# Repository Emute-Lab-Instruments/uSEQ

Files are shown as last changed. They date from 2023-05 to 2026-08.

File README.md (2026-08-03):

# uSEQ

uSEQ is a livecodeable eurorack module.

There's a paper on it here: 

Kyriakoudis, Dimitris, & Kiefer, Chris. (2023, April 19). uSEQ: A LISPy Modular Sequencer for Eurorack with a Livecodable Microcontroller. 7th International Conference on Live Coding (ICLC2023), Utrecht, The Netherlands. https://doi.org/10.5281/zenodo.7843874

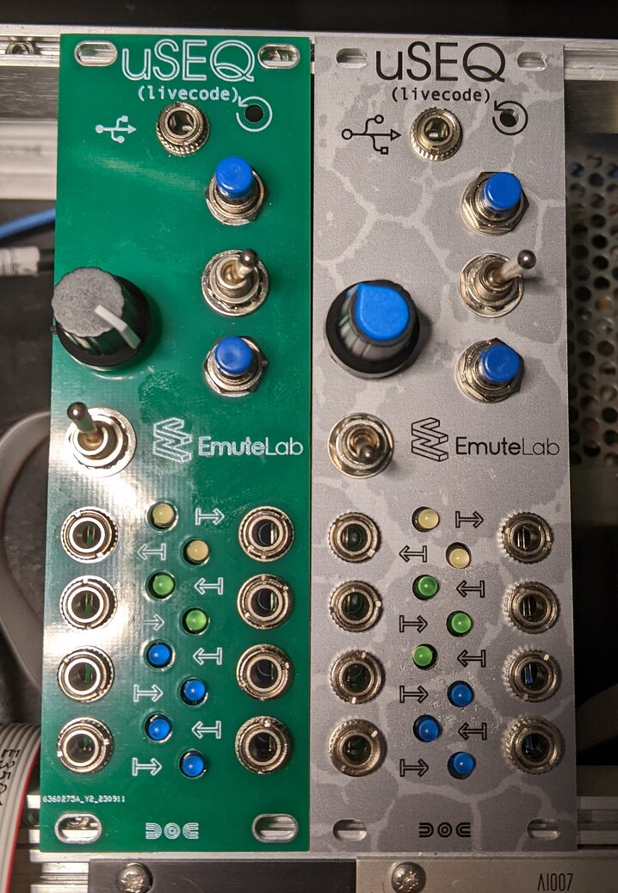
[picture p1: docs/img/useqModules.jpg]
uSEQ Modules


uSEQ modules, two panel designs (PCB, Aluminium)

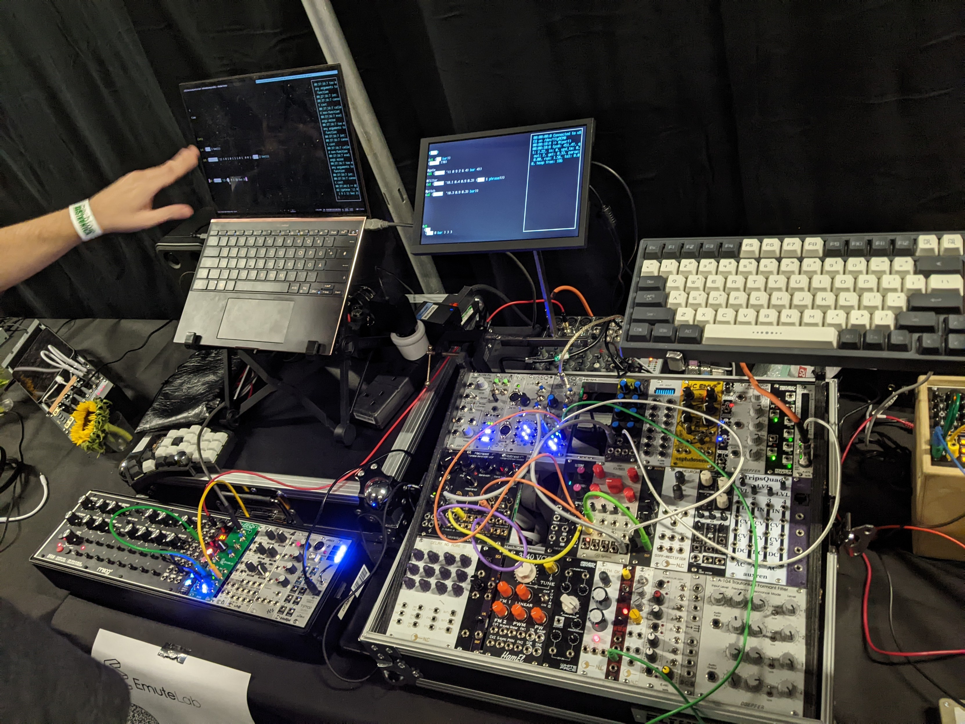
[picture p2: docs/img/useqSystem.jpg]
uSEQ In Use


uSEQ modules set up within eurorack performance systems

## Features:

* Open source hardware and software
* Low-cost DIY project
* Live code using a simple LISP language library, from a laptop or mobile device, using serial-over-USB
* Stream waveforms back over USB serial to a computer, and route it to MIDI or OSC, linking the modular with software and external hardware
* Livecoding engine with flexible timing and varied options for creating gate and CV patterns (from basic waveforms to euclidean sequencing) and structuring arrangements

More info from [https://www.emutelabinstruments.co.uk/useq/](https://www.emutelabinstruments.co.uk/useq/)

## Canonical Specs

The firmware/language specs live in [docs/specs/MAIN.md](docs/specs/MAIN.md).
Protocol details live in [docs/specs/wire-protocol.md](docs/specs/wire-protocol.md).
Read [MAP.md](MAP.md) for the repository index and [ALIGNMENT.md](ALIGNMENT.md)
for the dated mission-level gaps.

## Verification

- `nix-shell` enters the declared compiler, conformance, WASM, PlatformIO,
  and RP2040 goal-gate environment. On unattended hosts, use
  `nix-shell --run '<command>'` so PyYAML and the target tools come from the
  same environment.
- `meson setup build && meson compile -C build && meson test -C build` runs
  the native suites.
- `python3 scripts/run_conformance.py --probe build/test/signal_engine_probe --target native`
  runs the shared language corpus against the native probe.
- `scripts/build_wasm.sh` builds and checks the generated interpreter;
  `python3 scripts/run_conformance.py --target wasm` runs the same corpus
  against it; `python3 scripts/wasm_manifest.py verify` verifies its compiler
  record.
- `pio run -e musicthing` establishes target compile, link, and static size;
  it is not a physical-execution result.
- `python3 scripts/rp2040_memory_report.py` reads the exact linked ELF and
  enforces the 96KiB main-heap and 1MiB flash-image headroom gates. Runtime
  heap and stack watermarks remain separate target observations.
- `pio run -e musicthing-observe` builds the release-equivalent telemetry
  image used by simulator and physical-device capacity/endurance runs;
  `musicthing` remains the production image without devtools overhead.
- `python3 scripts/run_rp2040_profile.py` runs the full local RP2040
  acceptance surface: native correctness, constrained-profile conformance,
  capacity and sanitized endurance workloads, both target links, and exact
  ELF memory gates. See
  [docs/testing/rp2040-optimization.md](docs/testing/rp2040-optimization.md).
- `python3 scripts/run_wokwi_rp2040.py` boots that exact observation ELF in
  Wokwi and gates serial responses, target compile and tick timing, runtime
  heap/stack headroom, resource high-water, sustained tick throughput,
  protocol integrity, reset state, retained workload capacity, transactional
  rejection, and externally captured GPIO. It requires `wokwi-cli` and an
  unprinted `WOKWI_CLI_TOKEN`.
- `python3 scripts/run_rp2040_goal_gate.py` composes the complete native,
  exact-link, and simulator grades into one uniquely named candidate evidence
  directory for an optimization loop. Physical-device acceptance remains a
  separate release grade.

## Building the Firmware

The firmware is in the [uSEQ](./uSEQ/) folder.

Build the firmware in Arduino IDE, using the [Earle Philhower Pico core](https://github.com/earlephilhower/arduino-pico).

| Setting  | Value |
| --- | --- |
| Board  | Generic RP2040  |
| Boot Stage 2  | W25Q080 QSPI /2  |
| Flash Size | 16MB (Sketch 2MB, FS: 14MB) for `musicthing` |
| CPU Speed | 250MHz (Overclock) |
| Optimize | Optimize Even More (-O3) |

Overclock the Pico at 250Mhz and set the optimisation level to -O3.
Other program-card capacities require a matching PlatformIO partition profile;
the default `musicthing` environment is the 16MB card profile.

We welcome pull requests.

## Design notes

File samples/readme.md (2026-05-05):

# Sample Library Creation for uSEQ

## Requirements

Python 3
A terminal
[Picotool](https://github.com/raspberrypi/picotool)

## Samples

Create a folder with the samples that you'd like to have in your library.  The names of the files will be the names that you use to refer to the samples in Modulisp code.

# Compiling samples into a binary File

To get help:

```
 python3 multi_audio_converter.py -h
```

Usage:

This code creates a binary file ```mysamples.bin```, converting all the samples to 22050 KHz. It also creates a script to load the samples into flash memory

```
python3 multi_audio_converter.py [folder of samples] -o mysamples.bin -r 22050 -s loader.sh
```

# Load the samples onto the hardware

Connect the instrument, and make sure no other serial connections are open (e.g. the code editor).  Run the sample loading script that was generated in the step above. e.g.

```
./loader.sh
```

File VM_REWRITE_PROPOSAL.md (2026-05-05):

# VM Rewrite Proposal

## Summary

The current bytecode VM migration improved performance and correctness, but it did not fully remove the architectural mismatch between:

- cold-path Lisp evaluation for REPL / top-level forms
- hot-path sampled output execution for signals

That mismatch still shows up as:

- runtime bridges from compiled output graphs back into AST-driven evaluation
- `Environment`-copy churn on bridge-heavy paths
- hybrid semantics where some forms are fully compiled, some are partly lowered, and some fall back dynamically
- extra complexity around dependency invalidation, closure capture, and late-bound globals

This document proposes a rewrite direction that keeps the working parts of the current system, but replaces the hybrid execution model with a cleaner architecture.

## Recommendation

Do not rewrite this as "the same VM, but cleaner."

Rewrite it as a two-tier execution system with a hard boundary:

- a cold general evaluator/VM for full Lisp semantics
- a hot signal compiler/runtime for outputs and sampled execution

The hot signal path should never call back into AST evaluation on the sample path.

## Why

The current implementation has already shown three distinct categories of issues:

1. Straight defects

- semantic mismatches like `time`
- unnecessary invalidation/stringification work
- wasteful batch fallback behavior

2. Local inefficiencies

- temporary argument allocation
- repeated environment copying
- bridge cache misses

3. Structural friction

- sampled graphs still use runtime bridge callbacks for unsupported forms
- the environment model is still string-keyed and interpreter-oriented
- output execution still depends on a hybrid of compile-time inlining and runtime lookup

Category 1 should be fixed in place.

Category 2 can be improved incrementally, and we already did some of that.

Category 3 is where the architecture is carrying debt. Further work there is mostly compensation, not real simplification.

## Architectural Position

### 1. Separate Cold and Hot Execution

The system should have two execution modes with different constraints and internal representations.

Cold path:

- REPL evaluation
- top-level `define`, `defn`, transport commands, scheduling
- general Lisp semantics
- can allocate freely
- can use tagged values everywhere
- latency matters less than completeness and diagnostics

Hot path:

- output sampling
- time-window evaluation
- WASM render loops
- RP2040/RP2350 per-sample execution
- allocation-free during execution
- no AST callbacks
- no string-keyed lookups
- predictable failure and recovery behavior

This boundary should be explicit in the implementation and in the language contract.

### 2. Make Output Programs Closed Over Explicit Inputs

Compiled output programs should not depend on an `Environment` object at runtime.

Instead, a compiled output graph should read from explicit runtime inputs:

- temporal channels: `t`, `time`, `beat`, `bar`, `phrase`, `section`, counts, durations
- hardware inputs
- global cells referenced by the graph
- closure captures lowered to slots/cells

A sampled program should be executable from:

- bytecode/IR
- a runtime context struct
- a compact global-cell table

and nothing else.

### 3. Replace Environment-Based Lookup With Slot/Cell-Based Lookup

The current `Environment` is a good interpreter data structure. It is a poor hot-path runtime substrate.

A rewrite should distinguish:

- lexical local slots
- closure capture slots
- global cell indices
- builtins/opcodes
- temporal/input channels

Name lookup should happen during lowering, not repeatedly during execution.

Suggested model:

- locals: integer slot indices
- globals: interned symbol ID -> cell index
- captures: explicit capture vector or cell references
- builtins: direct opcode lowering or builtin ID dispatch

This removes the need for sampled execution to copy or walk chained `Environment` objects.

### 4. Remove Runtime AST Bridges From the Sample Path

The current fallback model is convenient but expensive:

- some forms compile natively
- some partially compile
- some fall back through bridge intrinsics

That is exactly the boundary where performance work keeps piling up.

For a rewrite, choose one of these models explicitly:

Option A: Restricted output language

- outputs may only use the signal-safe subset
- unsupported forms are compile errors
- no runtime bridge exists for sampled graphs

Option B: General output VM

- outputs may use broader Lisp semantics
- the general VM is real and self-contained
- no fallback to AST interpreter from compiled execution

What should not survive is the current middle ground where sampled graphs may bounce back into the interpreter machinery.

### 5. Use an Explicit IR Instead of Bytecode Plus Escape Hatches

The rewrite should introduce an explicit intermediate representation between AST and executable bytecode.

Suggested pipeline:

1. Parse Lisp AST
2. Lower to typed-ish IR with explicit value categories
3. Resolve names to slots/cells
4. Run transforms
5. Validate hot-path safety
6. Lower to execution form

IR-level distinctions that matter:

- numeric scalar
- tagged value
- vector data segment
- temporal/input load
- global cell load
- closure/call node
- effectful op
- bounded loop / reducible loop

This gives a clean place for:

- constant folding
- common-subexpression elimination
- closure lowering
- loop lowering
- time-transform composition
- future WASM SIMD or RP2350-specific specialization

## Language and Semantics Policy

### Output Language

A rewrite should define a hard policy for outputs.

Recommended default:

- outputs are expression graphs
- top-level effects are forbidden inside outputs
- mutable/general control-flow support is explicit and bounded
- `eval` is not allowed on the sampled path

`for` and `while` should not be "maybe compiled, maybe bridged." They should either:

- lower to native hot-path constructs
- or be rejected in output context

### Globals

Globals referenced by outputs should be represented as versioned cells.

Each cell should have:

- current value
- current expression, if lazily derived
- revision number
- hot-path compatibility metadata

Compiled outputs should depend on cell IDs and revision stamps, not on serialized snapshots.

### Closures

Closures should not capture `Environment` objects.

They should capture:

- values by slot
- or references to global cells

If a closure is allowed in output context, it must lower to a representation the hot runtime can execute without re-entering the cold evaluator.

## Runtime Design

### Hot Runtime Requirements

The hot runtime should guarantee:

- no heap allocation during steady-state execution
- no string lookup
- no AST traversal
- no `Environment` cloning
- no symbol-changed callbacks during local slot mutation
- bounded branches / bounded loops
- direct numeric fast path when possible

### Failure Model

The current LKG and batch-fallback design is reasonable and should mostly be kept.

Hot runtime errors should:

- abort the current graph evaluation
- preserve already-valid batch prefix results
- switch to last-known-good or neutral fallback
- emit diagnostics on the cold side, not allocate per sample

## WASM and Microcontroller Implications

### WASM

The rewrite should optimize for:

- compact transfer/storage of compiled graphs
- worker-friendly execution
- easy future SIMD backend
- deterministic hot loop with no JS-interpreter crossover

### RP2040 / RP2350

The rewrite should optimize for:

- low heap pressure
- fixed-size or amortized-stable runtime storage
- predictable instruction dispatch
- minimal pointer chasing
- data locality for globals and registers

This argues strongly against keeping `std::function`-heavy bridge callbacks on the hot path.

## What To Keep From The Current Work

These ideas are still good and should be retained:

- unboxed numeric fast path
- structured diagnostics
- dependency tracking by symbol ID / revision
- batch execution APIs
- LKG fallback strategy
- compile-time time-transform lowering
- direct lowering for common math / vector operations

The rewrite should preserve those gains, not start from zero conceptually.

## Proposed Rewrite Shape

### Phase 0. Freeze the Contract

Before implementation, define:

- what is legal in output context
- what closure semantics are supported in output context
- whether dynamic `for`/`while` are hot-path features or cold-path-only features
- whether a general tagged VM will fully replace cold interpreter execution

### Phase 1. Introduce Global Cells

Create a runtime global-cell table with:

- stable cell IDs
- revision counters
- current value / expression metadata

Move output invalidation and compiled dependencies onto cells directly.

### Phase 2. Introduce a Real IR

Lower AST to IR that has:

- explicit slot/cell references
- explicit effectful nodes
- explicit hot-path legality markers

Use the IR to decide:

- hot signal compilation
- cold tagged execution
- rejection with diagnostics

### Phase 3. Build the Signal Runtime

Implement a signal runtime that consumes only:

- compiled graph
- temporal/input context
- global-cell table

No runtime AST bridge.

### Phase 4. Migrate Outputs First

Do not rewrite everything at once.

Migrate output execution first:

- `a*`, `d*`, `s*`
- batch sampling
- time-window rendering

This is where the performance constraints are strictest and the architecture matters most.

### Phase 5. Decide the Fate of the General VM

At that point choose:

- keep cold evaluator as interpreter
- or finish a full tagged VM for cold execution too

Either choice is acceptable.

What matters is that the hot path no longer depends on the cold evaluator.

## Non-Goals

This proposal does not require:

- JIT compilation
- LLVM
- immediate SIMD work
- type inference beyond what is useful for hot-path validation
- eliminating tagged values from cold execution

Those can come later.

## Tradeoffs

### Pros

- cleaner hot/cold separation
- less bridge complexity
- less environment churn
- easier reasoning about correctness
- easier future specialization for WASM / RP2350

### Cons

- stricter output language unless a real general VM is built
- larger up-front rewrite cost
- migration complexity around closures and global state
- some existing permissive behaviors may become explicit compile errors

## Recommended Direction

Recommended practical choice:

- keep a permissive cold evaluator
- build a strict compiled signal runtime for outputs
- reject unsupported output forms instead of bridging them

This is the best fit for:

- live-coding reliability
- microcontroller constraints
- WASM execution
- simpler long-term maintenance

If full generality in outputs is a hard product requirement, then the right answer is not more bridge work. The right answer is a proper general VM that does not delegate back to the interpreter.

## Questions For The AI Council

1. Should output context become a formally restricted language, or is full general Lisp semantics in outputs a hard requirement?
2. Should dynamic `for` and `while` be supported natively in sampled graphs, or moved to cold-path-only semantics?
3. Should closures in output context capture by value, by cell reference, or be restricted further?
4. Is a full tagged general VM worth the complexity, or should the cold evaluator remain interpreter-based?
5. What is the minimal IR needed to support the signal runtime cleanly without overengineering?
6. What migration plan best preserves live-coding behavior while removing the runtime bridge from sampled outputs?

## Bottom Line

The recent fixes were valuable, but they also clarified the boundary:

- correctness fixes were necessary
- bridge optimization work was mostly debt service

If we rewrite from scratch, the goal should be to eliminate the need for that debt service, not become better at paying it.

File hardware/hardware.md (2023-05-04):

# uSEQ Hardware

The hardware version is show n the front side of the PCB

## Version 0.2

Panels and schematic in the version0.2 folder

[version 0.2 guide](version0.2/v0.2.guide.md)

(coming soon: build docs and Kicad files)

## Version 0.1

This is almost the same as v2, except for a differences which are detailed in the [version 0.1 guide](version0.1/v0.1.guide.md)

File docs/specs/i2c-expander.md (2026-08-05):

# I2C Output Expander

> Spec: host discovery and the synth-free eight-output expander transport.
> This is a control-rate transport between RP2040 modules, not a ModuLisp or
> synthesis execution profile.

## 1. Build and hardware profile

1.1 `bringup-expander-L2` defines `USEQHARDWARE_EXPANDER_OUT_0_1`,
`ENABLE_I2C_NETWORKING`, and `ENABLE_I2C_CLIENT`. The firmware selects client
mode at boot. A primary hardware profile selects host mode even where its
historical build flags also define client support.

1.2 The expander I2C pins are SDA GPIO4 and SCL GPIO1. GPIO0 remains LED 8.
The bus operates at 400 kHz. A valid factory record's non-zero default address
wins. Otherwise a build may set `USEQ_I2C_CLIENT_ADDRESS` in `[1,126]`; the
final fallback derives an address from the RP2040 chip ID and maps zero to 1.

1.3 The expander image contains no signal engine or synth engine. It receives
already-evaluated values and maps them to its eight continuous output slots.

1.4 The current RP2040 expander profile declares 2 MiB flash and reserves the
final 4 KiB erase sector at offset `0x1ff000` as its factory partition. The
Arduino Pico core already excludes that EEPROM sector from application UF2s;
the expander runtime exposes no EEPROM write path. This is read-only by
firmware/build policy; external QSPI has no hardware write-protect boundary.

## 2. Discovery

2.1 The host scans addresses 1 through 126 during initialization. For each
acknowledging address it writes the eight ASCII bytes `$gettype` and requests
seven response bytes.

2.2 An output expander responds with `aout08` followed by NUL. The host records
at most five matching addresses. Discovery occurs at host startup and when the
editor sends the explicit JSON `rescan-modules` request; it is not continuous.

2.3 After the legacy type response, a current host writes `$identify` and asks
for the fixed 206-byte identity response. Its schema contains the encoded
factory record, firmware version, exact firmware target, protocol version, and
capability bits. Failure to answer keeps an older expander discoverable.

2.4 A missing or CRC-invalid factory record is not repaired or guessed. The
main reports the module as `unidentified-prototype`; editors must not select a
UF2 automatically. A valid record bubbles product, hardware revision,
assembly variant, batch, unit serial, manufacture date, MCU family, update
transport, and firmware identity through `hello.modules`.

## 3. Factory identity record

3.1 `factory_identity.{h,cpp}` defines a 128-byte little-endian record with
magic `USEQID1`, schema version 1, MCU family (`rp2040` or `rp2350`), default
I2C address, feature bits, product, hardware revision, assembly variant,
batch, serial, manufacture date, flash size, and CRC32 over bytes 0 through
123. CRC provides corruption detection only; it is not authentication. A
default I2C address of zero selects the chip-ID-derived policy, avoiding a
shared fixed address across production units; 1 through 126 requests a fixed
manufacturing-assigned address.

3.2 `scripts/prepare_factory_identity.py` emits a 4 KiB sector image, a
provision-only UF2 at the final sector of the selected flash size, and JSON
metadata for manufacturing review. Flash the identity UF2 once, verify it by
discovery/readback, then flash ordinary application UF2s. Never include a
factory-identity UF2 in the public firmware manifest.

## 4. Value frame

4.1 The host mirrors logical outputs `a1` through `a8` to every discovered
output expander after signal execution on each firmware tick.

4.2 A value frame is exactly:

| Offset | Size | Meaning |
|---|---:|---|
| 0 | 6 | ASCII `$vals` followed by NUL |
| 6 | 1 | value count, 1 through 8 |
| 7 | `count * 8` | IEEE-754 binary64 values, little-endian |

No padding, checksum, or terminator follows the final value. The frame length
must equal `7 + count * 8` exactly.

4.3 The client validates the complete frame before changing any output. A bad
prefix, invalid count, wrong length, or non-finite value rejects the whole
frame. Finite values are clamped to `[0,1]` at the electrical boundary. A
valid partial frame updates its first `count` channels and retains the other
channels.

## 5. Runtime safety

5.1 The hardware receive callback only copies complete Wire transactions into
a fixed-capacity single-producer/single-consumer queue. It does not decode,
allocate, or write GPIO.

5.2 The main firmware tick drains the queue in FIFO order before writing
outputs. If several valid packets are queued, the newest applied packet is the
observable vector for that tick.

5.3 The queue holds four transactions. When full it rejects the newest
transaction and preserves accepted order. Invalid packets, queue overflow,
NACK, and disconnection retain the last applied output vector.

5.4 Host broadcast uses bounded synchronous Wire transactions. One expander
frame is 71 bytes at 400 kHz. This deliberately trades tick cadence for the
required synth-free streaming path; its physical worst-case latency remains a
target measurement, not a native-test claim.

## 6. Evidence boundary

6.1 `test/firmware/test_i2c_expander.cpp` connects production host and client
`I2CNetwork` instances through `MockI2CBus`. It strictly covers build-mode
selection, factory codec/CRC, discovery/type and identity responses, all eight output
values, malformed and non-finite rejection, queue capacity, NACK hold, and
recovery.

6.2 The native fake bus does not exercise the RP2040 Wire peripheral, board
traces, pull-ups, voltage stages, PWM filtering, LED polarity, or connector
orientation. The `bringup-expander-L2` target build and synth-boundary ELF
inspection establish target composition, not those physical properties.

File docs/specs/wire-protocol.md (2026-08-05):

# Wire Protocol

> Spec: the byte-level and message-level contract over USB CDC serial between
> a uSEQ module and a host editor. Counterpart to [MAIN.md](MAIN.md) and
> [firmware.md](firmware.md). This is the **single source of truth** for
> what crosses the wire — where any other doc, comment, or implementation
> disagrees with this file, this file wins and they are bugs.
>
> See also: [live-edit.md](live-edit.md) for the slot-write semantics that
> ride on top of `set-live-inputs`; [diagnostics.md](diagnostics.md) for the
> diagnostic shape; [failure-model.md](failure-model.md) for the
> must-deliver vs. opportunistic guarantees.
>
> Editor-side counterpart: `useq-perform/docs/specs/transport.md` (transport
> state machine, clock policy). Editor-side reference implementation:
> `useq-perform/src/transport/`.
>
> Firmware implementation map (non-normative): request handling and dispatch
> live in `uSEQ/src/firmware/serial_protocol.cpp`; protocol state and JSON
> response/log helpers live in `uSEQ/src/utils/log.cpp`; lightweight JSON
> construction lives in `uSEQ/src/utils/json_builder.h`; output routing,
> including serial stream frame emission, lives under `uSEQ/src/uSEQ/`.

### Source Files

Firmware side:

- `uSEQ/src/firmware/serial_protocol.{h,cpp}` — `SerialProtocol`: RX ring buffer, JSON message extraction, `dispatch_message()`, `handle_hello()`, `handle_ping()`, `handle_stream_config()`, `handle_set_live_inputs()`, `send_eval_response()`, `send_stream_data()`, `send_diagnostics()`, `send_log()`, `send_ready()`. Dispatches `debug` messages to the devtools subsystem.
- `uSEQ/src/devtools/devtools.{h,cpp}` — `debug` message handler: capability negotiation, channel configuration, query dispatch, streaming telemetry. Compile-gated behind `USEQ_DEVTOOLS`.
- `uSEQ/src/firmware/firmware.{h,cpp}` — `Firmware::tick()` (drains serial, dispatches eval, emits stream frames)
- `uSEQ/src/utils/serial_message.h` — wire-level constants: start marker (`0x1F`), message type bytes (`STREAM`, `INPUT_SET`), rate limits
- `uSEQ/src/utils/json_builder.h` — `JsonBuilder`: lightweight fluent JSON construction (no external library)
- `uSEQ/src/utils/log.{h,cpp}` — `Protocol` namespace: JSON mode toggle, request ID tracking, response helpers
- `uSEQ/src/firmware/flash_storage.{h,cpp}` — persistence surface referenced by boot sequence

WASM parity:

- `wasm/wasm_wrapper.cpp` — same JSON shapes as ABI calls (`useq_eval`, `useq_last_diagnostics`, etc.)

Tests:

- `test/firmware/test_wire_protocol_contract.cpp` — contract tests encoding the spec section by section
- `test/firmware/test_firmware_e2e.cpp` — end-to-end tests including serial protocol interactions

---

## 1. Frame

1.1 The protocol is **JSON-only for structured traffic** with a single binary
escape for high-rate output stream frames. There is no plain-text legacy
mode, no negotiated fallback, no `@`-prefix immediate-eval marker, and no
queued/immediate flag on the wire (per [firmware.md §6.2](firmware.md)).
The host (the *editor*, in app terminology) initiates all conversations
because Web Serial only enumerates host-side: the device has no signal
that a host is now listening.

1.2 The wire protocol has an independent integer version advertised by
`hello` and `ready`; protocol v1 first ships in firmware `1.2.0-beta.1`.
This firmware implementation remains JSON-only. A host may carry an isolated
adapter for pre-1.2 firmware, but legacy framing is not part of protocol v1
and does not enter this firmware's receive path.

1.3 The protocol is **symmetric** in framing: editor → device and device →
editor share the same on-wire shape. Reserved/forward-compatible binary
frame types (§3.4) exist in both directions.

---

## 2. Physical Layer

| Parameter | Value |
|---|---|
| Interface | USB CDC (virtual serial port) |
| Baud rate | 115,200 |
| Data bits | 8 |
| Stop bits | 1 |
| Parity | None |
| Flow control | None |

The baud rate `1200` is **not** a serial mode; opening the port at 1200 baud
and closing it immediately is the RP2040 BOOTSEL convention for entering
the DFU bootloader. The editor uses this for firmware updates. The device
itself does not handle 1200 baud as a runtime mode.

---

## 3. Wire-Level Framing

3.1 **Discrimination from the first byte.** (See `uSEQ/src/utils/serial_message.h` — start marker 0x1F, message type byte constants; `uSEQ/src/firmware/serial_protocol.cpp` — try_extract_message, byte-level discrimination.)

| First byte | Frame kind |
|---|---|
| `0x1F` (`31`, ASCII Unit Separator) | Binary frame (see §3.2). Second byte selects the binary subtype. |
| `{` | JSON message (see §3.3). Continues until terminator. |
| anything else | Garbage / out-of-sync; receiver advances one byte and re-discriminates. |

3.2 **Binary frame layout.** All binary frames begin with `[0x1F][type]`.
The type byte selects a fixed-shape payload. Binary frames are **not**
terminated by a delimiter — their length is determined by the type byte.

| Type byte | Name | Direction | Payload shape | Total length |
|---|---|---|---|---|
| `0x00` | `STREAM` | device → editor | `[channel:u8][value:f64-LE]` | 11 bytes |
| `0x01` | `INPUT_SET` (**implemented**) | editor → device | `[count:u16-LE][(slot_index:u16-LE, value:f64-LE) × count]` | 4 + 10·count bytes |

Type bytes outside this table are reserved. Receivers MUST advance one
byte (i.e. discard the leading `0x1F`) on encountering an unknown type
byte, then re-discriminate.

3.3 **JSON message layout.** A JSON message is a single JSON object (one
`{ … }` pair) followed by a line terminator. Implementations MUST emit
`\n` (LF) as terminator. Implementations MUST accept either `\n` or
`\r\n`, and MUST ignore intervening blank lines. There is **no** `0x1F`
marker or type byte preceding the `{`.

3.4 **Forward compatibility.** New binary type bytes will be added as
needed; new JSON `type` values will be added as needed. Receivers MUST
ignore unknown JSON `type` values (logging them at debug level is
acceptable; raising an error is not).

3.5 **No legacy types.** The legacy type bytes `0x20 TEXT` and `0x64
MSG_TO_EDITOR` are removed. Anything that was previously framed text from
the device is now a JSON `{type:"log",...}` envelope (§5.6). Anything
that was previously raw text from the editor (the `(useq-version)` probe,
the `@`-prefix, plain LISP code) is removed entirely.

---

## 4. Connection Lifecycle

### 4.1 Boot (device side)

On boot completion, the device emits **one** unsolicited `ready` frame
(§5.5) and then enters its tick loop. The frame may or may not be
delivered to a listening host — the device has no way to know if a host
is currently attached. Hosts MUST NOT depend on receiving the `ready`
frame.

### 4.2 Connect (editor side)

When the editor opens the port (whether via user gesture or
auto-reconnect to a saved port):

1. Editor opens the port at 115,200 baud.
2. Editor sends a `hello` request (§5.1) immediately.
3. Editor starts a retry timer (~700 ms per attempt, ≤ 8 attempts).
4. While waiting:
   - If the device replies with a `hello` response (§5.2): handshake
     complete. Editor proceeds to §4.3.
   - If the editor receives an unsolicited `ready` frame: editor
     immediately re-sends `hello` (a `ready` indicates the device just
     finished booting, possibly mid-handshake).
   - If the retry timer fires without either of the above: editor
     re-sends `hello` and increments attempt count.
5. If all 8 attempts time out, editor surfaces a connection error.

### 4.3 Steady state

Once the handshake is complete, the editor:

1. Sends a `stream-config` request (§5.3) using the io config from the
   `hello` response.
2. Starts a heartbeat: a `ping` request (§5.4) every 60 s, with a 10 s
   timeout. On heartbeat failure, the editor warns the user but does not
   forcibly disconnect.
3. Begins sending `eval` requests (§5.7) and `set-live-inputs` requests
   (§5.8) as the user works.
4. Begins consuming binary `STREAM` frames (§3.2 / §6) and any
   unsolicited JSON messages (§5.5, §5.6, §5.9, §5.10).

### 4.4 Disconnect

The Web Serial API fires a disconnect event when the USB device is
removed. On disconnect, the editor:

- Rejects all pending requests with `"Connection reset"`.
- Stops the heartbeat.
- Resets all protocol state.
- Posts a console notice.

The device has no observable disconnect event; it simply stops receiving
bytes. Outstanding TX writes that have not been drained are lost.

---

## 5. JSON Messages

5.1 **Common rules.**

- Every JSON message MUST be a single object on one line, terminated per
  §3.3.
- Every JSON message MUST have a top-level `"type"` string field.
- Every **request** (editor → device) MUST have a `"requestId"` string
  field unless that message's section explicitly defines a fire-and-forget
  form. Format is freeform (the reference editor uses `req-N`); receivers
  MUST treat it as opaque and echo it verbatim.
- Every **response** (reply to a request) MUST have `"type":"response"`,
  the echoed `"requestId"`, and a `"success":bool` field.
- Every **unsolicited** message (e.g. `ready`, `log`, standalone
  `diagnostics`) MUST have its own `type` value and MUST NOT have a
  `requestId`.

The full request → response → unsolicited message catalog follows.

### 5.1 `hello` (editor → device, request)

Sent by the editor immediately on port open. Retried per §4.2. (See `uSEQ/src/firmware/serial_protocol.cpp` — handle_hello parses hello request, sends hello response with config.)

```json
{"type":"hello","client":"editor","version":"1.2.0","requestId":"req-1"}
```

| Field | Type | Required | Description |
|---|---|---|---|
| `type` | string | yes | Always `"hello"`. |
| `client` | string | yes | Identifier for the host implementation. The reference editor sends `"editor"`. Devices MAY log this but MUST NOT vary behaviour by client. |
| `version` | string | yes | Editor's protocol version (semver). |
| `requestId` | string | yes | Per §5.1. |

### 5.2 `hello` response (device → editor)

```json
{
  "type": "response",
  "requestId": "req-1",
  "success": true,
  "mode": "json",
  "fw": "1.2.0-beta.1",
  "protocol": 1,
  "target": "hardware_v1_0",
  "capabilities": ["json-v1", "stream-v1", "diagnostics-v1"],
  "modules": [{
    "kind": "output-expander", "address": 42,
    "identityStatus": "verified", "product": "useq-exp-aout08",
    "target": "expander_aout08_v0_1", "firmware": "1.2.0-beta.1",
    "hardwareRevision": "0.1", "batch": "PP-2026-01",
    "serial": "EXP-0007", "mcu": "rp2040",
    "connectedVia": "i2c", "updateTransport": "i2c-only",
    "autoUpdateSafe": false
  }],
  "config": {
    "inputs":  [{"index": 1, "name": "ssin1"}, ...],
    "outputs": [{"index": 1, "name": "time"},
                {"index": 2, "name": "s1"}, ...]
  }
}
```

| Field | Type | Required | Description |
|---|---|---|---|
| `type` | string | yes | Always `"response"`. |
| `requestId` | string | yes | Echoed from the request. |
| `success` | bool | yes | Always `true` if a hello response is sent at all. (Failure mode is "no response"; editor times out and retries.) |
| `mode` | string | yes | Always `"json"`. Reserved field; future protocol variants might use other values. |
| `fw` | string | yes | Device firmware version. Used by the editor for upgrade checks. |
| `protocol` | integer | yes | Independent wire-protocol version; `1` for this contract. |
| `target` | string | yes | Exact build target (`musicthing`, `hardware_v0_2`, or `hardware_v1_0`; native tests report `unknown`). |
| `capabilities` | string[] | yes | Additive feature identifiers. Editors ignore unknown names and gate optional requests on advertised names. |
| `modules` | object[] | yes when I2C networking is compiled | Startup-discovered subordinate modules. A missing/corrupt factory record uses `identityStatus:"unidentified-prototype"` and `autoUpdateSafe:false`; see [i2c-expander.md](i2c-expander.md). |
| `config` | object | yes | I/O configuration; see below. |

**`config.inputs`** is an array of `{index, name}` describing externally
addressable hardware-input slots. Indices are 1-based. Names match the
ModuLisp builtins (`ssin1`, `ssin2`, …). Currently informational —
externally-driven inputs flow via `set-live-inputs` (§5.8), not via input
channels.

**`config.outputs`** is an array of `{index, name}` describing streamed
outputs. Indices are 1-based. The reserved name `"time"` denotes the
canonical time channel; other names follow the s-output convention
(`s1`, `s2`, …). Stream frames (§6) carry these indices in the channel
byte.

The hello response is the **single source of truth** for the firmware
version, protocol, build target, capabilities, module inventory, and I/O configuration, replacing all prior probing
mechanisms.

### 5.3 `stream-config` (editor → device, request)

Sent by the editor after a successful hello, using the io config from the
hello response. (See `uSEQ/src/firmware/serial_protocol.cpp` — handle_stream_config parses channel configs, updates `stream_rate_limit_us` and the `stream_channels[]` array of `StreamChannel{enabled, source, source_idx, on_change_only}`.)

```json
{
  "type": "stream-config",
  "maxRateHz": 30,
  "channels": [
    {"id": 1, "name": "time", "direction": "output", "enabled": true,  "maxRateHz": 30},
    {"id": 2, "name": "s1",   "direction": "output", "enabled": true,  "maxRateHz": 30},
    ...
  ],
  "requestId": "req-2"
}
```

| Field | Type | Required | Description |
|---|---|---|---|
| `maxRateHz` | number | yes | Global maximum stream emission rate. Device MUST NOT emit stream frames faster than this rate, summed across channels. |
| `channels` | array | yes | Per-channel configuration. |
| `channels[].id` | number | yes | Channel index (matches `hello.config` index space). |
| `channels[].name` | string | yes | Channel name (informational; mirrors `hello.config`). |
| `channels[].direction` | string | yes | One of `"input"` / `"output"`. |
| `channels[].enabled` | bool | yes | If `false`, device MUST NOT emit stream frames for this channel. |
| `channels[].maxRateHz` | number | optional | Per-channel rate cap. Reserved for future use; current firmware ignores it. The global `maxRateHz` is authoritative. |
| `requestId` | string | yes | Per §5.1. |

**Response:** standard ack `{type:"response",requestId,success:true}`.

The reference editor enables all advertised channels at the default rate
(100 Hz). Editors MAY narrow this if they need to reduce bandwidth.

### 5.4 `ping` (editor → device, request)

```json
{"type":"ping","requestId":"req-3"}
```

**Response:** standard ack `{type:"response",requestId,success:true}`.

The editor sends a ping every **60 seconds** while the connection is
established. If no response arrives within **10 seconds**, the editor
warns the user but does not forcibly disconnect.

The ping carries no payload other than the type and request id. Devices
MUST respond promptly without doing meaningful work.

### 5.5 `ready` (device → editor, unsolicited)

Sent **once** by the device on boot completion (post-flash-load,
post-watchdog-arm). Advisory only — see §4.1.

```json
{"type":"ready","version":"1.2.0-beta.1","protocol":1,"target":"hardware_v1_0","capabilities":["json-v1","stream-v1"]}
```

| Field | Type | Required | Description |
|---|---|---|---|
| `type` | string | yes | Always `"ready"`. |
| `version` | string | yes | Device firmware version (matches the `fw` field of the hello response). |
| `protocol` | integer | yes | Independent wire-protocol version. |
| `target` | string | yes | Exact hardware build target. |
| `capabilities` | string[] | yes | Additive feature identifiers. |

The field name on this frame is `"version"` — not `"fw"` — matching the
historical naming in [firmware.md §3.1.6](firmware.md). The hello
response keeps `"fw"` for backwards compatibility with prior editors;
both name the same value.

Editors that see a `ready` after their handshake is already complete MUST
treat it as a no-op (the device may have rebooted; the editor SHOULD log
this but does not need to re-handshake unless it observes other failure).

### 5.6 `log` (device → editor, unsolicited)

Replaces the legacy `TEXT (0x20)` and `MSG_TO_EDITOR (0x64)` framed-text
type bytes. Used by builtins such as `(println …)` and
`(message-editor …)` to emit unsolicited text.

```json
{"type":"log","level":"info","text":"Hello from uSEQ"}
```

| Field | Type | Required | Description |
|---|---|---|---|
| `type` | string | yes | Always `"log"`. |
| `level` | string | yes | One of `"debug"`, `"info"`, `"notice"`, `"warn"`, `"error"`. |
| `text` | string | yes | The message text. May be multi-line (newlines escaped per JSON). |

`"notice"` is the level used by `(message-editor …)` — the editor SHOULD
display these prominently rather than mixing them into routine console
output.

### 5.7 `eval` (editor → device, request)

Evaluate a ModuLisp expression. (See `uSEQ/src/firmware/serial_protocol.cpp` — dispatch_message returns true for eval type, caller reads code; `uSEQ/src/firmware/firmware.cpp` — Firmware::tick calls eval_cold with the code buffer, then send_eval_response; `uSEQ/src/signal_engine/cold_eval.cpp` — eval_cold, the actual evaluation.) Defaults to immediate; the optional
`quant` flag opts the request into the runtime's quantised-eval queue.

```json
{"type":"eval","code":"(a1 0.5)","requestId":"req-4"}
{"type":"eval","code":"(a1 0.5)","quant":true,"requestId":"req-5"}
```

| Field | Type | Required | Description |
|---|---|---|---|
| `type` | string | yes | Always `"eval"`. |
| `code` | string | yes | The ModuLisp source to evaluate. Multi-form bodies are permitted. |
| `quant` | bool | optional | When `true`, the device queues the form and evaluates it on the next wrap of the global quant phasor (see Quantisation note below). When `false` or absent, the form evaluates immediately. |
| `requestId` | string | yes | Per §5.1. |

Maximum `code` length: 2048 bytes (firmware RX buffer cap). Editors SHOULD
keep evals comfortably under this; oversized inputs MAY be truncated by
the device.

**Response shape:**

```json
{
  "type": "response",
  "requestId": "req-4",
  "success": true,
  "text": "0.5",
  "console": "",
  "diagnostics": [
    {"severity":"warning","category":"…","start":3,"end":7,"message":"…","suggestion":"…"}
  ],
  "meta": null
}
```

| Field | Type | Required | Description |
|---|---|---|---|
| `type` | string | yes | Always `"response"`. |
| `requestId` | string | yes | Echoed from the request. |
| `success` | bool | yes | `false` iff the eval produced an error diagnostic that aborted execution. Compile-time warnings do not flip success to false. |
| `text` | string | optional | The eval's return value rendered as a string. Empty string if the result is unprintable or `nil`. |
| `console` | string | optional | Captured stdout from `print`/`println` invocations during the eval, accumulated as a single string. Empty string if nothing was printed. |
| `diagnostics` | array | optional | Diagnostics produced during compile or evaluation; see [diagnostics.md](diagnostics.md). Per §5.9, these are also delivered embedded in this response (not just as standalone frames). |
| `meta` | object \| null | optional | Structured side-channel data (e.g. transport state changes resulting from the eval). When non-null, the editor dispatches this to interested subscribers. May be `null` (or absent) for evals that produce no side-effect metadata. |

Per [failure-model.md](failure-model.md) and [firmware.md §7.2](firmware.md),
eval responses are **must-deliver**: the device blocks briefly until TX
buffer space exists rather than dropping. Stream frames and standalone
diagnostics are opportunistic and may be dropped under load.

**Quantisation.** Eval requests are immediate by default. Setting
`quant: true` opts the request into the device's quantised-eval queue:
the device buffers the form and evaluates it on the next wrap of the
**global quant phasor** — a single runtime-side phasor that defaults to
`bar` and is changed via the ModuLisp builtin
`(set-quant-phasor expr)`. The wire only conveys the on/off bit; the
period itself is part of runtime state, not protocol state. See
[firmware.md §6](firmware.md) for queue ordering, drain semantics, and
phasor-update behaviour.

The eval response (§5.7 response shape) is sent **after the deferred
evaluation completes**, not at submission time, so a quantised eval's
`requestId` round-trip latency is bounded by the current quant period.
Editors SHOULD surface a "pending" affordance until the response
arrives.

### 5.8 `set-live-inputs` (editor → device, request)

Write to one or more `live-edit` slots in a single atomic message. (See `uSEQ/src/firmware/serial_protocol.cpp` — handle_set_live_inputs parses slot JSON, applies values.) See
[live-edit.md §5.3](live-edit.md) for the runtime semantics; this section
specifies only the wire shape.

```json
{
  "type":"set-live-inputs",
  "slots":{"knob1":0.5,"toggle1":true,"mode1":"forward"},
  "requestId":"req-5"
}
```

| Field | Type | Required | Description |
|---|---|---|---|
| `type` | string | yes | Always `"set-live-inputs"`. |
| `slots` | object | yes | Map of `:id` (string) → new value. Numeric values are JSON numbers; boolean slots accept `true`/`false`; keyword slots accept the keyword name as a JSON string (without the leading colon). |
| `requestId` | string | optional | Editors MAY include a request id for tracing. If present, device responds with `{type:"response",requestId,success:true,"applied":N}` where `N` is the count of slots successfully applied (matching the `useq_set_live_inputs` ABI return — see [live-edit.md §5.10](live-edit.md)). If absent, the message is fire-and-forget; the device applies what it can and emits no response. |

Per [live-edit.md §5.4](live-edit.md), unknown ids are silently dropped
(the host may be racing the most recent eval). Type or range violations
emit a runtime warning via the standalone diagnostics frame (§5.9) but
do not flip `success` for the request.

The shape of `slots` exactly mirrors the WASM ABI
`useq_set_live_inputs(json_str)` argument (see [live-edit.md §5.10](live-edit.md))
so editors and tests can use one payload-builder for both transports.

### 5.9 `diagnostics` (device → editor, unsolicited)

Standalone diagnostics frame — sent for runtime-occurring diagnostics
that do not correspond to a single eval response (e.g. live-edit
slot-write type violations, fallback-to-LKG events, runtime non-finite
warnings).

```json
{"type":"diagnostics","diagnostics":[{"severity":"warning",...}]}
```

| Field | Type | Required | Description |
|---|---|---|---|
| `type` | string | yes | Always `"diagnostics"`. |
| `diagnostics` | array | yes | Same shape as the embedded form in eval responses (§5.7). See [diagnostics.md](diagnostics.md). |

These frames are **opportunistic** — the device MAY drop them if TX is
backed up. Eval responses are still the must-deliver path for
eval-correlated diagnostics; the standalone frame is for everything else.

### 5.10 `hw-input` (device → editor, unsolicited)

Pushed by the device when a physical control (button, toggle, encoder
click, gate input) changes state. The device emits one frame per edge
transition — rising and falling for momentary controls, state-change for
toggles.

See [hardware-bindings.md](../../useq-perform/docs/specs/hardware-bindings.md)
for how the editor routes these events to bound expressions.

```json
{"type":"hw-input","kind":"button","id":"sw1","state":"pressed","ts":123456}
{"type":"hw-input","kind":"toggle","id":"sw2","state":true}
{"type":"hw-input","kind":"encoder","id":"swr","state":"pressed"}
{"type":"hw-input","kind":"gate","id":"in1","state":"released"}
```

| Field | Type | Required | Description |
|---|---|---|---|
| `type` | string | yes | Always `"hw-input"`. |
| `kind` | string | yes | One of `"button"`, `"toggle"`, `"encoder"`, `"gate"`. Identifies the control type — see below. |
| `id` | string | yes | Physical-control keyword **without** the leading colon. E.g. `"sw1"`, `"sw2"`, `"swr"`, `"in1"`. Matches the `<input-id>` keywords in [hardware-bindings.md §2.4](../../useq-perform/docs/specs/hardware-bindings.md). |
| `state` | string \| bool | yes | For `button`/`encoder`/`gate`: `"pressed"` or `"released"` (string). For `toggle`: `true` (on) or `false` (off) (boolean). |
| `ts` | number | optional | Device-side timestamp in milliseconds since boot. Absent when the firmware does not yet emit timestamps. Editors MUST NOT depend on its presence. |

**Kind semantics:**

- `"button"` — momentary switch. Two edges: `"pressed"` then `"released"`.
  The device debounces; the editor receives clean edges.
- `"toggle"` — sticky toggle switch. One event per flip, carrying the
  post-flip boolean state (`true` = on, `false` = off).
- `"encoder"` — encoder click (the push-button on a rotary encoder).
  Treated as momentary (`"pressed"` / `"released"`). Encoder *rotation*
  is a continuous signal (`(rot)`), not an event — it has no `hw-input`
  frame.
- `"gate"` — external gate/trigger input (`:in1`, `:in2`). Carries
  `"pressed"` (gate high) and `"released"` (gate low).

**Delivery.** `hw-input` frames are **must-deliver**: hardware input
events are infrequent (human-rate, not audio-rate) and losing one would
silently break the performer's control flow. The device blocks briefly
if TX is full, matching eval-response delivery semantics.

**Forward compatibility.** New `kind` values may be added in future
firmware. Editors MUST ignore unknown kinds (logging at debug level is
acceptable).

### 5.11 `calibrate-begin` (editor → device, request)

Enter calibration takeover mode for one analog output. The device freezes
all other outputs at their current LKG values and takes exclusive control
of the named output. See
[calibration.md](../../docs/specs/calibration.md) for the editor-side UX
spec.

```json
{"type":"calibrate-begin","output":"a1","requestId":"req-20"}
```

| Field | Type | Required | Description |
|---|---|---|---|
| `type` | string | yes | Always `"calibrate-begin"`. |
| `output` | string | yes | Analog output id (e.g. `"a1"`, `"a2"`). Must match an output exposed by the connected variant. |
| `requestId` | string | yes | Per §5.1. |

**Response:**

```json
{
  "type": "response",
  "requestId": "req-20",
  "success": true,
  "status": {"kind": "uncalibrated"}
}
```

| Field | Type | Required | Description |
|---|---|---|---|
| `type` | string | yes | Always `"response"`. |
| `requestId` | string | yes | Echoed from the request. |
| `success` | bool | yes | `false` if the output is unknown, already in takeover for a different output, or the variant does not support calibration. |
| `error` | string | on failure | Human-readable rejection reason. |
| `status` | object | on success | Per-output calibration status. One of `{"kind":"uncalibrated"}`, `{"kind":"calibrated","date":"<ISO>"}`, or `{"kind":"partial","savedOctaves":[0,1]}`. |

Only one output may be in takeover at a time. Sending `calibrate-begin`
for a second output while a takeover is active MUST fail with
`success: false`.

### 5.12 `calibrate-set-target` (editor → device, request)

Drive the takeover output to a specific target voltage. Sent on takeover
entry (to set the initial 0V target) and when advancing to the next
octave step.

```json
{"type":"calibrate-set-target","output":"a1","voltage":1.0,"requestId":"req-21"}
```

| Field | Type | Required | Description |
|---|---|---|---|
| `type` | string | yes | Always `"calibrate-set-target"`. |
| `output` | string | yes | Must match the output currently in takeover. |
| `voltage` | number | yes | Target voltage (typically 0, 1, 2, 3, or 4). The firmware drives the DAC to produce this voltage (before any calibration correction). |
| `requestId` | string | yes | Per §5.1. |

**Response:** standard ack `{type:"response",requestId,success:true}`.
On failure (e.g. output mismatch, no active takeover), `success: false`
with `error`.

### 5.13 `calibrate-adjust` (editor → device, request)

Apply a fine correction delta (in cents) to the current output. The
firmware accumulates deltas internally; the editor maintains a local
mirror for display (see
[calibration.md §4.5](../../docs/specs/calibration.md)).

```json
{"type":"calibrate-adjust","output":"a1","delta":0.5,"requestId":"req-22"}
```

| Field | Type | Required | Description |
|---|---|---|---|
| `type` | string | yes | Always `"calibrate-adjust"`. |
| `output` | string | yes | Must match the output currently in takeover. |
| `delta` | number | yes | Signed correction in cents. Positive = sharper / higher voltage; negative = flatter / lower voltage. |
| `requestId` | string | yes | Per §5.1. |

**Response:**

```json
{"type":"response","requestId":"req-22","success":true}
```

If the firmware clamps the accumulated offset (e.g. hardware limit), the
response includes `clampedOffset`:

```json
{"type":"response","requestId":"req-22","success":true,"clampedOffset":48.2}
```

| Field | Type | Required | Description |
|---|---|---|---|
| `clampedOffset` | number | optional | The firmware's authoritative cumulative offset in cents after applying the delta. Present only when the value was clamped. The editor MUST snap its UI to this value. |

### 5.14 `calibrate-save-point` (editor → device, request)

Stage the current calibration point for a specific octave. The value is
held in RAM; it is not flushed to flash until `calibrate-end` with
`commit: true` (§5.15).

```json
{"type":"calibrate-save-point","output":"a1","octave":2,"requestId":"req-23"}
```

| Field | Type | Required | Description |
|---|---|---|---|
| `type` | string | yes | Always `"calibrate-save-point"`. |
| `output` | string | yes | Must match the output currently in takeover. |
| `octave` | number | yes | Octave index: `0` (0V), `1` (1V), `2` (2V), `3` (3V), or `4` (4V). |
| `requestId` | string | yes | Per §5.1. |

**Response:** standard ack `{type:"response",requestId,success:true}`.
On failure (e.g. flash write error), `success: false` with `error`.

### 5.15 `calibrate-end` (editor → device, request)

Exit calibration takeover and resume normal operation.

```json
{"type":"calibrate-end","commit":true,"requestId":"req-24"}
```

| Field | Type | Required | Description |
|---|---|---|---|
| `type` | string | yes | Always `"calibrate-end"`. |
| `commit` | bool | yes | `true` — flush all staged calibration points to flash and apply them. `false` — discard staged points and revert the output to its pre-takeover calibration state. |
| `requestId` | string | yes | Per §5.1. |

**Response:** standard ack `{type:"response",requestId,success:true}`.

After a successful `calibrate-end`, the device resumes normal output
behaviour. Stream frames resume if they were suspended during takeover.

### 5.16 `debug` (editor → device, request)

Dev-build-only telemetry and introspection. Gated behind `USEQ_DEVTOOLS` at compile time. Release-build devices ignore this message type per §3.4.

```json
{"type":"debug","action":"capabilities","requestId":"req-30"}
{"type":"debug","action":"configure","channels":{"tick":"stream"},"requestId":"req-31"}
{"type":"debug","action":"query","channel":"state","requestId":"req-32"}
{"type":"debug","action":"status","requestId":"req-33"}
```

| Field | Type | Required | Description |
|---|---|---|---|
| `type` | string | yes | Always `"debug"`. |
| `action` | string | yes | One of `"capabilities"`, `"configure"`, `"query"`, `"status"`. |
| `requestId` | string | yes | Per §5.1. |

Additional fields depend on `action`. See [devtools.md](devtools.md) for
the full channel catalog, response shapes, and streaming semantics.

**Delivery.** Unsolicited `debug` frames (streaming telemetry) are
**opportunistic** — dropped if TX is full, matching stream-frame
semantics (§3.2).

### 5.17 Calibration response conventions

All `calibrate-*` requests are **must-deliver** (the device blocks
briefly on TX backpressure rather than dropping). Response shapes follow
the standard `{type:"response",requestId,success}` envelope (§5.1).

Additional fields that MAY appear on calibration responses:

| Field | Type | Description |
|---|---|---|
| `error` | string | Human-readable rejection reason (present when `success: false`). |
| `clampedOffset` | number | Firmware's authoritative cumulative offset in cents. Present on `calibrate-adjust` responses when the value was clamped. |
| `status` | object | Per-output calibration status. Present on `calibrate-begin` success responses. |

The pre-takeover calibration state is sacred: the firmware holds the
prior calibration in memory across the takeover and only commits new
points to flash on `calibrate-end { commit: true }`. Individual
`calibrate-save-point` messages stage values; they do not flush
per-step. This protects the user from data loss on disconnect / abort.
See [calibration.md §6.3](../../docs/specs/calibration.md).

### 5.18 `set-failure-mode` (editor → device, request)

Configure the runtime non-finite failure policy
([failure-model.md §3.2](failure-model.md)). (See
`uSEQ/src/firmware/serial_protocol.cpp` — `handle_set_failure_mode`.)

```json
{"type":"set-failure-mode","mode":"lkg","requestId":"req-9"}
```

| Field | Type | Required | Description |
|---|---|---|---|
| `type` | string | yes | Always `"set-failure-mode"`. |
| `mode` | string | yes | `"lkg"` (default — non-finite at an output root falls back to the last-known-good value and raises a runtime diagnostic) or `"zero"` (legacy — every non-finite node result is clamped to `0.0`, no fallback, no diagnostic). |
| `requestId` | string | optional | Standard response correlation. |

The device responds with the standard `{type:"response",success}`
envelope; `success: false` (with an explanatory `text`) for any `mode`
other than `"lkg"` / `"zero"`. The mode is engine-global (not
per-output), defaults to `"lkg"` at boot, and is not persisted — editors
that expose the setting re-send it on connect. The WASM runtime
equivalent is `useq_set_failure_mode(0|1)` (0 = lkg, 1 = zero), keeping
both transports behind one editor setting.

### 5.19 `rescan-modules` (editor → device, request)

Repeats the bounded I2C discovery scan and returns a fresh `modules` array in a
standard response envelope:

```json
{"type":"rescan-modules","requestId":"req-10"}
```

```json
{"type":"response","success":true,"modules":[],"requestId":"req-10"}
```

The request is explicit rather than continuous hotplug polling. `success` is
false when the build is not operating as an I2C host. Discovery does not imply
an I2C firmware-update relay: a subordinate expander must use its own supported
update transport.

---

## 6. Binary Stream Frames

6.1 **Output stream frame** (`type 0x00`, device → editor). (See `uSEQ/src/firmware/serial_protocol.cpp` — send_stream_data writes 0x1F 0x00 channel value bytes; `uSEQ/src/utils/serial_message.h` — SerialMsg constants for frame layout.)

```
[0x1F] [0x00] [channel: u8] [value: 8 bytes, IEEE 754 double, little-endian]
  0      1        2                3..10
```

Total: **11 bytes**, fixed.

| Field | Width | Description |
|---|---|---|
| `0x1F` | 1 byte | Marker. |
| `0x00` | 1 byte | STREAM type byte. |
| `channel` | 1 byte | 1-based channel index, matching `hello.config.outputs[].index`. |
| `value` | 8 bytes | IEEE 754 double, little-endian. NaN and ±Inf are valid (and reserved for future health-state signalling). |

6.2 **Channel space.** Channels are 1-based and dense: 1, 2, 3, …, N where
N = `hello.config.outputs.length`. The reserved channel `1` carries
`time` by convention; channels `2..N` carry s-outputs (`s1..s(N-1)`).
This is **not** the same numbering as the firmware's internal output-slot
index (the 24-slot a/d/s space defined in [firmware.md §4.4](firmware.md));
the wire uses a stream-only channel namespace advertised in `hello`.

6.3 **Rate.** Limited by the most recent `stream-config.maxRateHz`
(default 100 Hz from the editor). The firmware's built-in default rate
cap is 100 Hz (`serial_message_rate_limit` in `serial_message.h`),
which applies before `stream-config` arrives. Devices MAY emit fewer
frames than the cap when a channel's value has not changed
(implementation-defined). Devices MUST NOT emit faster than the cap.

6.3.1 **Default streaming (before `stream-config`).** On entering JSON
mode (after hello), the device streams **only channel 1 (time)** at the
firmware default rate (100 Hz). All other channels are disabled until
the editor sends `stream-config` to enable them. This ensures the wire
is not saturated during the handshake window and that the editor
receives a time reference immediately for clock synchronization.

6.4 **Drop policy.** Stream frames are **opportunistic** — the device
drops them if its TX buffer is full ([failure-model.md](failure-model.md)).
Visualisation must tolerate gaps.

6.5 **Binary input frame** (`type 0x01`, `INPUT_SET`, editor → device):
**implemented**. This is the low-latency / high-throughput fast-path for
manual live control (knob/slider/joystick scrub, MIDI-learn CC) — it
carries high-rate value updates to live-edit slots that were already
**declared** via `set-live-inputs` (§5.8). Byte layout:

```
[0x1F] [0x01] [count: u16-LE] [(slot_index: u16-LE, value: f64-LE) × count]
  0      1        2..3              4..(4 + 10·count - 1)
```

Total: 4 + 10·count bytes. Multi-byte fields are little-endian. `value`
is an IEEE-754 `binary64` (f64-LE). A `count` of 0 is a valid (empty)
frame.

**`slot_index` semantics.** `slot_index` is a **direct zero-based index
into the device's live-slot table** — i.e. the same `live_slots[]` array
(`engine->pool.live_slots[0 .. live_slot_count)`) that `set-live-inputs`
(§5.8) writes after resolving its string `:id` keys. Slot indices are
assigned in **declaration order** by the most recent successful eval
(the order in which `live-edit` slots are first allocated during graph
build). A `set-live-inputs` write to `:knob1` and an `INPUT_SET` write to
that slot's index therefore target the **identical** slot and apply the
**identical** clamp/variant coercion (numeric clamp to `[min,max]`,
boolean → 0/1, keyword → option index; non-finite values rejected,
slot retains its prior value).

**Obtaining the index.** The editor learns each slot's index from the
`liveSlots` array returned by `get-state` (state-sync.md §2) and/or from
the `set-live-inputs` declaration order: entry *i* in the device's
live-slot table has `slot_index = i`. Because eval re-allocates the
table, the editor MUST re-sync its `id → slot_index` map after every
successful eval; until it has, it should fall back to JSON
`set-live-inputs` (which is keyed by string `:id` and is robust to
re-ordering).

**Bounds / garbage.** A `slot_index ≥ live_slot_count` is silently
dropped (consistent with §5.4 "unknown ids are dropped" and the
project's "garbage: skip" philosophy); other entries in the same frame
still apply. The frame is fire-and-forget — the device emits **no**
response or `applied` count. Range/type coercion is applied silently (no
per-frame diagnostics on the hot path).

Devices parse `INPUT_SET` allocation-free directly in the serial RX
demux (`SerialProtocol::try_consume_binary_frame` →
`NodePool::set_live_slot_value_by_index`). An incomplete frame (fewer
than `4 + 10·count` bytes buffered) is left in the RX buffer until the
remaining bytes arrive — **but only if the frame can ever fit**. A frame
whose declared length `4 + 10·count` exceeds the RX buffer capacity
(2048 bytes), or whose `count` exceeds the live-slot cap
(`MAX_LIVE_SLOTS`), can never be completed by waiting; the device MUST
treat it as a protocol error, drop the `0x1F` marker, and resync to the
next message start rather than parking on it forever. (A single
corrupted `count` byte must not be able to wedge the RX path.)

**RX resync (line/frame too long).** The RX ring buffer is fixed at 2048
bytes. If a single logical message — a JSON line with no newline, or a
malformed binary frame — fills the ring so that no further bytes can be
read, the device MUST NOT stall permanently. It drops the overflowing
message (advancing the read head to the next `{` or `0x1F` marker, or
clearing the ring if none) and emits a `{"type":"log","level":"error"}`
diagnostic ("message too long") so the editor learns its send was
dropped. Serial input remains live for subsequent messages.

> **NOTE (editor manual-control path).** `set-live-inputs` (§5.8) and the
> `0x01` `INPUT_SET` binary frame are **complementary**, not alternatives:
> `set-live-inputs` **declares** a live input (binds a string `:id` to a
> slot, with min/max/variant/options) and is the robust, self-describing
> path; the §6.5 `INPUT_SET` frame carries **high-rate value updates** to
> those already-declared slots, addressed by their integer table index,
> for the lowest-latency manual-control path (knob/slider/joystick scrub,
> MIDI-learn CC). An earlier editor build emitted a malformed 10-byte
> frame (`[0x1F][channel:u8][value:f64]`, with **no** type byte and no
> count); that shape is **not** conforming — the conforming binary write
> is the type-tagged, length-prefixed `INPUT_SET` frame above. Editors
> that have not yet synced their `id → slot_index` map after an eval MUST
> use `set-live-inputs` until the map is rebuilt.

---

## 7. Limits and Constants

| Constant | Value | Notes |
|---|---|---|
| Baud rate | 115,200 | USB CDC; not negotiable (1200 is the BOOTSEL trigger, not a runtime mode). |
| Heartbeat interval | 60 s | Editor-driven. |
| Heartbeat timeout | 10 s | Editor warns user on miss; does not forcibly disconnect. |
| Default stream rate | 100 Hz | Editor's `stream-config` initial value (`DEFAULT_STREAM_MAX_RATE_HZ`). |
| Max JSON message length | 2048 bytes | Firmware RX buffer cap. Editors SHOULD stay comfortably below. Oversized messages MAY be truncated. |
| Hello retry attempts | 8 | Per §4.2. |
| Hello attempt timeout | ≈ 700 ms | Per §4.2. |
| Live-edit slot cap | 16 (firmware) / 256 (WASM) | Compile-time `MAX_LIVE_SLOTS` (`signal_engine/types.h`); see [live-edit.md §5.1](live-edit.md). `INPUT_SET` `slot_index` is bounds-checked against the live runtime `live_slot_count`, not this static cap. |
| `INPUT_SET` `slot_index` | u16 (0…65535) | Wire range; values `≥ live_slot_count` are silently dropped (§6.5). |
| `INPUT_SET` `count` | u16 (0…65535) | Entries per frame; frame is `4 + 10·count` bytes. `count = 0` is a valid no-op. |

---

## 8. Worked Examples

### 8.1 Cold start, healthy device

```
device boots:
  → 0x1F 0x65 ... NO. Device emits:
    {"type":"ready","version":"1.2.0-beta.1","protocol":1,"target":"hardware_v1_0","capabilities":[...]}\n

editor opens port:
  ← {"type":"hello","client":"editor","version":"1.2.0","requestId":"req-1"}\n

device replies:
  → {"type":"response","requestId":"req-1","success":true,"mode":"json",
     "fw":"1.2.0-beta.1","protocol":1,"target":"hardware_v1_0",
     "capabilities":[...],"config":{"inputs":[...],"outputs":[...]}}\n

editor sends stream-config:
  ← {"type":"stream-config","maxRateHz":30,"channels":[...],"requestId":"req-2"}\n

device acks:
  → {"type":"response","requestId":"req-2","success":true}\n

steady state — device emits stream frames:
  → 0x1F 0x00 0x01 [time-bytes]
  → 0x1F 0x00 0x02 [s1-bytes]
  ...
```

### 8.2 Boot race (editor connects mid-boot)

```
editor opens port (device still booting):
  ← {"type":"hello","client":"editor","version":"1.2.0","requestId":"req-1"}\n

(no response — device's RX buffer received the hello but hasn't reached
 the tick loop yet)

device finishes boot:
  → {"type":"ready","version":"1.2.0-beta.1","protocol":1,"target":"hardware_v1_0","capabilities":[...]}\n

editor sees ready, retries hello immediately:
  ← {"type":"hello","client":"editor","version":"1.2.0","requestId":"req-2"}\n

device tick loop reads RX, processes the latest hello:
  → {"type":"response","requestId":"req-2","success":true,...}\n

editor proceeds to stream-config + steady state.
```

### 8.3 Eval with diagnostics

```
editor:
  ← {"type":"eval","code":"(a1 (+ 1 nope))","requestId":"req-7"}\n

device:
  → {"type":"response","requestId":"req-7","success":false,
     "text":"","console":"",
     "diagnostics":[
       {"severity":"error","category":"unbound","start":7,"end":11,
        "message":"unknown name 'nope'",
        "suggestion":"did you mean 'note'?"}
     ],
     "meta":null}\n
```

### 8.4 Live-edit slot updates

```
editor (on every UI tick while user drags slider):
  ← {"type":"set-live-inputs","slots":{"knob1":0.42},"requestId":"req-12"}\n

device (if requestId present):
  → {"type":"response","requestId":"req-12","success":true,"applied":1}\n
```

### 8.5 Hardware button press (with binding)

```
user presses sw1 on the module:
  → {"type":"hw-input","kind":"button","id":"sw1","state":"pressed","ts":48230}\n

editor looks up binding for (on-press :sw1 …), dispatches eval:
  ← {"type":"eval","code":"(mute-toggle)","requestId":"req-14"}\n

device responds:
  → {"type":"response","requestId":"req-14","success":true,"text":"1","console":"","meta":null}\n

user releases sw1:
  → {"type":"hw-input","kind":"button","id":"sw1","state":"released","ts":48412}\n

editor looks up binding for (on-release :sw1 …) — none registered, no eval sent.
```

### 8.6 Toggle switch flip

```
user flips toggle sw2 to "on":
  → {"type":"hw-input","kind":"toggle","id":"sw2","state":true}\n

editor dispatches (on-toggle :sw2 (lambda (state) …)) with state = true.
```

### 8.7 CV calibration session (one output, two octaves then abort)

```
editor enters calibration for a1:
  ← {"type":"calibrate-begin","output":"a1","requestId":"req-20"}\n

device acks with status:
  → {"type":"response","requestId":"req-20","success":true,
     "status":{"kind":"uncalibrated"}}\n

editor sets initial target to 0V:
  ← {"type":"calibrate-set-target","output":"a1","voltage":0,"requestId":"req-21"}\n
  → {"type":"response","requestId":"req-21","success":true}\n

user adjusts slider (delta = +1.3 cents):
  ← {"type":"calibrate-adjust","output":"a1","delta":1.3,"requestId":"req-22"}\n
  → {"type":"response","requestId":"req-22","success":true}\n

user saves octave 0:
  ← {"type":"calibrate-save-point","output":"a1","octave":0,"requestId":"req-23"}\n
  → {"type":"response","requestId":"req-23","success":true}\n

editor advances to 1V:
  ← {"type":"calibrate-set-target","output":"a1","voltage":1,"requestId":"req-24"}\n
  → {"type":"response","requestId":"req-24","success":true}\n

user adjusts, firmware clamps:
  ← {"type":"calibrate-adjust","output":"a1","delta":52,"requestId":"req-25"}\n
  → {"type":"response","requestId":"req-25","success":true,"clampedOffset":50}\n
  (editor snaps slider to 50 cents)

user aborts — discard partial calibration:
  ← {"type":"calibrate-end","commit":false,"requestId":"req-26"}\n
  → {"type":"response","requestId":"req-26","success":true}\n

device reverts a1 to pre-takeover state, resumes normal operation.
```

---

## 9. Implementation Notes

This section is non-normative — pointers for implementers, not part of the
contract.

### 9.1 Device side

- `firmware::SerialProtocol` in `uSEQ/src/firmware/serial_protocol.{h,cpp}` is
  the canonical implementation surface.
- `firmware::Firmware::tick()` drains RX once per tick (non-blocking) and
  emits responses and stream frames synchronously within the tick.
- TX backpressure: eval responses use `Serial.availableForWrite()` and
  block briefly; stream frames and standalone diagnostics check the same
  flag and drop if it returns 0.
- The legacy `Protocol::` namespace in `uSEQ/src/utils/log.cpp` and the
  legacy `uSEQ/src/uSEQ_lisp.h` interpreter declarations are out of scope
  for this spec; they belong to the old interpreter path being phased
  out.

### 9.2 Editor side

- The reference implementation lives in `useq-perform/src/transport/`.
  - `connector.ts`: port lifecycle, Web Serial events.
  - `json-protocol.ts`: hello/eval/ping/set-live-inputs lifecycle.
  - `stream-parser.ts`: byte-level discrimination per §3.
  - `types.ts`: TypeScript shape definitions.
- `useq-perform/src/runtime/jsonProtocol.ts` is the schema/type layer
  shared between the wire driver and the WASM in-memory transport.

### 9.3 WASM parity

- The same JSON shapes that flow over the wire flow as ABI calls into the
  WASM build (`useq_eval`, `useq_set_live_inputs`, etc.). One shape, two
  transports.
- See [live-edit.md §5.10](live-edit.md) for the live-edit ABI mirror.

---

## 10. Migration Notes (from prior protocol versions)

This section is non-normative — context for upgrading editor and firmware
implementations against this spec.

### 10.1 Removed surfaces

- **Legacy text mode.** Editor no longer sends raw LISP text; firmware no
  longer interprets bytes outside JSON `{ … }` and binary frames.
- **Firmware-info text probe** (`@(useq-report-firmware-info)`). Replaced
  by the `hello` response's `fw` field.
- **`@`-prefix immediate-eval marker.** Wire is immediate-only.
- **`exec` field on eval requests.** The legacy string-enum `exec` field
  was removed. The current spec exposes a single boolean `quant` flag on
  the eval request (§5.7) — opting an eval into the runtime's
  quantised-eval queue, gated by the global quant phasor. This is a
  different surface from the legacy `exec` (no per-request "scheduled at
  absolute time" mode, no editor-side hold).
- **`pending_commands` ring buffer in `firmware::Firmware`.** The legacy
  ring buffer (drained on bar-phasor wrap, populated by `@`-prefix text)
  is gone. The new firmware-side quantised-eval queue (§5.7,
  [firmware.md §6](firmware.md)) is its replacement: drained on
  global-quant-phasor wrap, populated by JSON eval requests carrying
  `quant: true`.
- **`TEXT (0x20)` and `MSG_TO_EDITOR (0x64)` type bytes.** Replaced by
  `{type:"log",...}` JSON envelopes.
- **Inbound 10-byte stream frame** (`[0x1F][channel][value]` editor →
  device, no type byte). Malformed/non-conforming. Replaced by
  `set-live-inputs` (§5.8) for slot **declaration** and the
  type-tagged, length-prefixed binary `INPUT_SET` frame (§6.5,
  **implemented**) for high-rate value updates.
- **`0x65` JSON type-byte prefix.** Both directions now emit bare
  `{ … }\n` with no `0x1F`/`0x65` framing prefix.

### 10.2 Renamed / reshaped

- **Ready frame field.** Was `"fw"` in current firmware code, now
  `"version"` (matches [firmware.md §3.1.6](firmware.md)). The hello
  response keeps `"fw"`; both name the same value.
- **Diagnostics field on eval response.** Newly required: editors that
  ignored it now MUST parse it and route to inline annotations.
- **`set-live-inputs`.** Newly defined. Editors implementing live-edit
  use this; firmware implementing live-edit handles this.
- **Standalone `diagnostics` frame.** Newly defined for runtime-occurring
  diagnostics outside an eval.

### 10.3 Editor changes implied by this spec

- Drop the firmware-info text-probe path; send `hello` immediately on
  port open.
- Re-send `hello` on receiving an unsolicited `ready`.
- Drop the `0x65` JSON type-byte expectation when receiving (or accept
  both for a transition window).
- Add handlers for `{type:"ready"}`, `{type:"log"}`, and standalone
  `{type:"diagnostics"}`.
- Parse `diagnostics` from eval responses (currently read only from the
  WASM exports).
- Drop `exec: "immediate"` from `JsonEvalRequest` (legacy field).
- Send `quant: true` on the eval request when the user invokes the
  Quantised eval keybinding; omit (or send `false`) for Immediate eval.
- Surface a "pending" affordance for in-flight quantised evals — the
  response arrives only after the deferred evaluation completes.
- Implement `set-live-inputs` request (when live-edit ships).

### 10.4 Firmware changes implied by this spec

- Change `ready` frame field name from `"fw"` to `"version"`.
- Stop emitting the `0x65` JSON type-byte prefix; emit bare `{ … }\n`.
- Stop emitting `TEXT (0x20)` and `MSG_TO_EDITOR (0x64)` type bytes;
  migrate to `{type:"log",level,text}` envelopes.
- Implement `set-live-inputs` handler (when live-edit ships).
- Implement the binary `INPUT_SET` (§6.5) RX demux (done:
  `SerialProtocol::try_consume_binary_frame` →
  `NodePool::set_live_slot_value_by_index`) for the low-latency
  manual-control fast-path.
- Remove the legacy `pending_commands` ring buffer in
  `firmware::Firmware`. Add the new quantised-eval queue, drained on
  global-quant-phasor wrap, populated by eval requests with
  `quant: true` (§5.7, [firmware.md §6](firmware.md)).
- Implement the `(set-quant-phasor expr)` ModuLisp builtin (default
  phasor: `bar`).

---

## 11. Open / Deferred

11.1 **Slot-registration sync for binary `INPUT_SET` (§6.5).** The
firmware side is **implemented**: `slot_index` is a direct index into the
live-slot table in declaration order, and `get-state`'s `liveSlots` array
(state-sync.md §2) exposes that table for the editor to build its
`id → slot_index` map. Remaining open question (editor-side): whether to
add a lightweight dedicated `slot-table` query frame rather than reusing
the heavier `get-state` snapshot, and how the editor should atomically
swap its index map on eval to avoid a window where a stale index targets
the wrong slot (mitigation today: fall back to `set-live-inputs` until the
map is re-synced).

11.2 **Per-channel `maxRateHz` in `stream-config` (§5.3).** Currently
ignored by firmware. Either drop the field or implement honoring it
when a real use case appears.

11.3 **Structured error codes.** v1 surfaces protocol-level errors as
`{success:false, text:"…"}` with a human-readable message. A future
revision could add a structured `errorCode` enum for programmatic
handling.

11.4 **Capability granularity.** Protocol v1 advertises named capabilities,
but the initial set is coarse. Split a capability only when a real build can
implement one half without the other; do not infer optional support from
firmware semver.

(11.5 was the open `(at-next-bar …)` question — resolved in v1 by the
`quant: true` eval-request flag (§5.7) plus the `(set-quant-phasor expr)`
ModuLisp builtin; see [firmware.md §6](firmware.md).)

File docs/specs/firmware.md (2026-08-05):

# Firmware Architecture

> Spec: composition, tick loop, hardware contracts, persistence surface,
> hardware variants, boot/recovery behaviour. Counterpart to
> [MAIN.md](MAIN.md). The user-observable surface lives here; module C++
> contracts (struct layouts and method signatures) are implementation
> details, not independent specs.

### Source Files

- `uSEQ/src/firmware/firmware.{h,cpp}` — `Firmware` struct (composition root), `init()`, `tick()` loop, watchdog
- `uSEQ/src/firmware/hardware_io.{h,cpp}` — `HardwareIO`: pin access, input sampling, output writing, boot LED sequence. All variant-specific pin maps and I/O logic live here.
- `uSEQ/src/firmware/serial_protocol.{h,cpp}` — `SerialProtocol`: JSON wire protocol, hello/ping/eval/stream-config dispatch
- `uSEQ/src/firmware/flash_storage.{h,cpp}` — `FlashStorage`: save/load via LittleFS, CRC32 validation
- `uSEQ/src/firmware/dsp_engine.{h,cpp}` — `DSPEngine`: optional core 1 audio-rate DSP, lock-free command queue (stub — P3)
- `uSEQ/src/firmware/i2c_network.{h,cpp}` — `I2CNetwork`: host discovery,
  fixed-capacity callback intake, and output-expander value broadcast; see
  [i2c-expander.md](i2c-expander.md)
- `uSEQ/src/firmware/utils/piopwm.h` — PIO-based PWM program for LED outputs (auto-generated by pioasm)
- `uSEQ/src/signal_engine/cold_eval.{h,cpp}` — `SignalEngine` struct, `eval_cold()`, `recompile_all_outputs()`
- `uSEQ/src/signal_engine/executor.{h,cpp}` — `execute_all_outputs()`, `commit_outputs()`, `commit_state()`
- `uSEQ/src/ports/IStorage.h` — testable storage interface for flash persistence
- `test/firmware/test_firmware_e2e.cpp` — full tick-loop end-to-end tests
- `test/firmware/test_wire_protocol_contract.cpp` — wire protocol contract tests
- `test/signal_engine/test_flash_storage.cpp` — flash save/load round-trip tests

### Build Configuration

Variant selection is compile-time via PlatformIO environments in `platformio.ini`. Each environment passes `-D MUSICTHING`, `-D USEQHARDWARE_1_0`, etc. as build flags. There is no separate `configure.h` — feature flags are defined directly in the PIO env. Pin maps are defined inline in `hardware_io.cpp` under `#ifdef` guards per variant.

## 1. Composition

1.1 The firmware is a **composition of independent modules**, not an inheritance hierarchy. Each module has one responsibility and communicates through explicit data:

- `SignalEngine` — owns all interpreter state (cells, node graphs, output slots).
- `HardwareIO` — pin access, input sampling, output writing (PWM + SPI DAC), indicator LEDs.  See [hardware-io.md](hardware-io.md) for pin maps, filtering, and LED details.
- `SerialProtocol` — JSON wire protocol over USB serial.
- `FlashStorage` — preset save/load via LittleFS on on-chip flash.
- `I2CNetwork` — primary-module discovery and control-rate value broadcast to
  synth-free output expanders.
- `DSPEngine` — optional, audio synthesis on core 1 (stub — P3).

The `Firmware` struct is the composition root, instantiated once. `HardwareIO` never reads or writes the signal engine; it only touches its own input/output buffers, which the tick loop bridges to the engine.

## 2. Tick Loop

2.1 Each cycle on core 0 runs the following sequence in order:

1. Read system time.
2. `io.read_inputs()` — sample all hardware inputs once per tick.
3. If a serial command is pending: `engine.eval_cold(code)` and send response.
4. In expander client mode, validate and apply queued I2C value frames.
5. `engine.execute(time, inputs)` — one forward pass over all output graphs.
6. In host mode, broadcast logical values `a1` through `a8` to discovered
   output expanders.
7. `io.write_outputs(values)` — write to PWM / SPI DAC / digital pins.
8. **Swap `current → prev`** for cross-output `prev` reads (see [prev.md](prev.md)).
9. Opportunistic streaming back to the editor (skipped when budget exceeded).

2.2 **Hot-path invariants.** The signal execution and expander client paths
never allocate or compile; serial reads are non-blocking. Host-mode expander
broadcast is the one bounded synchronous-I2C exception: each discovered
expander receives one 71-byte frame at 400 kHz per tick. Hardware inputs are
sampled exactly once per tick; multiple reads of the same input within a tick
see the same value. Physical measurement must establish the resulting maximum
tick latency before a real-time headroom claim includes an expander.

2.3 **Dual-core split (RP2040 / RP2350).** Core 0 runs the tick loop above. Core 1 is reserved for optional `DSPEngine.tick()` (audio-rate synthesis, P3). Communication is through lock-free queues only — no shared mutable state. The signal engine can enqueue DSP commands but never waits for core 1.

## 3. Boot, Recovery, Watchdog

3.1 **Boot sequence:**

1. Hardware init (pins, ADC, PIO PWM, LEDs, PDM timer, gate interrupts).
2. Boot LED animation (variant-specific LED chase — see [hardware-io.md §6](hardware-io.md)).
3. Serial protocol init.
4. Signal engine init: register builtins, set defaults (BPM 120, 4/4).
5. Mount LittleFS. If a saved state file exists and passes CRC32 validation, load it and recompile all outputs. On checksum mismatch or missing file the engine starts with defaults.  On flash load failure, `boot_led_error_flash()`.
6. LED → green (all LEDs off, onboard LED flash — ready).
7. Enable the watchdog.
8. Send `{"type":"ready","version":"..."}` over serial. This frame is advisory; the editor does not wait for it and may send `hello` immediately after opening the port.
9. Enter the tick loop.

3.2 **LED indicator states** (user-visible minimum contract):

| Colour | Meaning |
|---|---|
| amber | booting; or compile error on most recent eval (transient flash) |
| green | running |
| red | flash load failure (transient flash); or persistent runtime error (held) |

Implementations may add finer-grained states (e.g. RGB channels per output health); the three-state contract above is the floor.

3.3 **Watchdog.** A hardware watchdog with a **200 ms timeout** is kicked at the end of every tick. If a tick exceeds the timeout (catastrophic bug, infinite loop in the cold path), the watchdog resets the MCU. On reset, the firmware boots fresh — flash-saved state is preserved and reloaded normally. The reset is invisible to the performer beyond a brief LED amber-flash.

## 4. Hardware Variants

4.1 Hardware differences are resolved at **compile time**. There is no runtime variant detection, no virtual dispatch, and no dead variant code in the binary. Variant defines (`-D MUSICTHING`, etc.) are passed by PlatformIO environments. Pin maps and I/O logic are defined inline in `hardware_io.cpp` under per-variant `#ifdef` guards.

4.2 Variant table:

| Variant | Continuous outs | Binary outs | Inputs | Controls | Flash | Notes |
|---|---|---|---|---|---|---|
| MUSICTHING | 4 | 2 | 2 CV + 2 gate + 2 audio | 3 knobs, 1 switch | 16 MB | Inverted outputs; SPI DAC for aL/aR |
| USEQHARDWARE_0_2 | 2 | 4 | 2 gate | Rotary encoder, switches | 8 MB | |
| USEQHARDWARE_1_0 | 3 | 3 | 2 CV + 2 gate | Toggle switch, momentary | 8 MB | |
| USEQHARDWARE_EXPANDER_OUT_0_1 | 8 | 0 | — | — | — | I2C output expander (no local inputs) |
| MINIMAL | 2 | 2 | — | — | 2 MB | Testing only (desktop) |

4.3 **Variant gating of language surface.** Hardware input leaves and outputs that don't exist on a given variant are compile-time errors when referenced in code. See [inputs.md](inputs.md) and [outputs.md](outputs.md). The signal engine queries `HardwareIO::num_*` counts at compile time to validate references.

4.4 **Output index convention** (matches the signal engine's slot numbering):

| Index range | Slot names | Type |
|---|---|---|
| 0–7 | `a1`–`a8` | continuous (analog voltage, 0–5 V or 0–10 V depending on variant) |
| 8–15 | `d1`–`d8` | binary (gate, 0 V or 5 V) |
| 16–23 | `s1`–`s8` | serial (virtual, streamed over the wire protocol) |

Indices beyond the variant's physical count are skipped by `write_outputs()`; they remain valid as serial-stream destinations.

4.5 **Music Thing SPI DAC.** The Music Thing variant uses an MCP4822 SPI DAC for the first two continuous outputs (aL, aR). These are driven via SPI writes, not analogWrite(). Outputs a3/a4 use PWM. The DAC SPI pins are defined in `hardware_io.cpp` under `#ifdef MUSICTHING`. **Status: not yet implemented in the new firmware — currently uses analogWrite() as a placeholder.**

4.6 **Input filtering.** Analog input filtering is variant-specific.  USEQHARDWARE_1_0 uses a **median-of-51 filter** (fixed-size, no heap allocation) matching the original production firmware.  Music Thing uses **ResponsiveAnalogRead** with 4x oversampling on mux-based inputs.  See [hardware-io.md §3](hardware-io.md) for full details.

## 5. Persistence Surface

5.1 The user-observable persistence surface — what survives a power cycle:

| Persisted | Not persisted |
|---|---|
| `(define name expr)` cells (source text) | `(set name value)` mutations (no source text) |
| Output expressions (source text) | Runtime state (current `t`, prev-output values, hardware inputs) |
| Tempo / metre (`bpm`, `time-sig`) | Diagnostic history |
| Module ID (for I2C addressing) | LKG slots (rebuilt by re-evaluation) |

5.2 **LittleFS for flash persistence.** State is stored as a named file on a LittleFS filesystem mounted on the RP2040's on-chip flash. LittleFS provides wear-levelling, power-loss atomicity, and named-file access. The `IStorage` port interface (`uSEQ/src/ports/IStorage.h`) abstracts the filesystem for testability; `MockStorage` provides an in-memory implementation for tests.

5.3 **`save` is a cold-path action.** Triggered by `(memory-save)`. The serial buffer is drained first and a `"save-in-progress"` status sent so the editor knows to expect a brief pause. Outputs continue running from the live pool throughout the save. **Status: current implementation uses raw flash sector writes — migration to LittleFS is pending.**

5.4 **No backward compatibility with pre-2.0 firmware flash.** Upgrading requires a clean flash erase. The old format serialised `Value` objects and environment maps that have no equivalent in the current signal engine.

## 6. Quantised Eval

6.1 Quantised eval is **runtime-driven**, gated by a single **global quant phasor**. The editor sets `quant: true` on the eval request (see [wire-protocol.md §5.7](wire-protocol.md)); the firmware buffers the form in a quantised-eval queue and drains the queue on the next wrap of the quant phasor. The eval response is sent only after the deferred evaluation completes, so the request's `requestId` round-trip is bounded by the current quant period. Within a single wrap, queued evals execute in submission order with no "latest wins" coalescing — every queued eval runs.

6.2 The **global quant phasor** defaults to `bar`. It is changed via the ModuLisp builtin `(set-quant-phasor expr)` — e.g. `(set-quant-phasor (slow 2 bar))` for a two-bar period. The phasor is global runtime state, not per-request: the wire only conveys the on/off bit for each eval. **Phasor changes are an atomic switch:** calling `(set-quant-phasor …)` immediately replaces the gating phasor for the entire queue — all already-queued entries, plus any subsequent ones, drain together on the next wrap of the new phasor. The previous phasor is dropped without firing; queued entries are never lost, only retimed.

6.3 The historical `@`-prefix immediate-eval surface and the legacy `pending_commands` ring buffer (drained on bar-phasor wrap, populated by `@`-prefix text) are both **gone**. The new quantised-eval queue replaces the ring buffer with a JSON-driven, phasor-configurable mechanism. Editor-side hold is no longer used; the editor sends `quant: true` and lets the runtime do the timing — keeping hardware and WASM behaviour identical by construction.

## 7. LKG and Error Handling

7.1 The "never stop the music" contract is firmware-relevant in several places beyond the language-level LKG fallback ([failure-model.md §2](failure-model.md)):

| Source of failure | Firmware behaviour | Outputs |
|---|---|---|
| Parse / compile error in serial command | Diagnostic in eval response. No engine state change. | Active program unchanged. |
| Flash load failure on boot | Engine starts with defaults. | All outputs neutral until user evaluates code. |
| Flash CRC32 mismatch | Treated as no saved state. | Same as above. |
| Serial TX buffer full during `eval` response | Block briefly until space available. Never drop. | Unchanged. |
| Serial TX buffer full during stream / diagnostic | Drop the message. | Unchanged. |
| Watchdog reset | Fresh boot; saved state reloaded. | Brief discontinuity then resume. |

7.2 `eval` responses are the user's confirmation that their code was received and processed. The serial protocol guarantees they are never silently dropped.

7.3 Diagnostics on the wire follow the format in [diagnostics.md](diagnostics.md). The firmware's serial JSON eval response embeds them as a `diagnostics` field.

## 8. Known Gaps (Implementation vs Spec)

These are known discrepancies between what this spec describes and what the firmware currently implements. Each should have a corresponding beads issue.

| Gap | Spec says | Current state | Priority |
|---|---|---|---|
| LittleFS | Persistence via LittleFS filesystem | Raw flash sector writes with CRC32 | P2 |
| General I2C networking | Named modules, leader/follower negotiation, tempo/input sharing | The output-expander discovery and value path is implemented; general module networking remains deferred | P2 |
| DSPEngine | Optional core 1 audio synthesis | Hollow stub | P3 |

Previously listed gaps that have been resolved:
- **SPI DAC** — Music Thing aL/aR now use MCP4822 SPI DAC via `dac_write()`.
- **Input filtering** — v1.0 uses median-of-51 matching original firmware; Music Thing uses ResponsiveAnalogRead with 4x oversampling.  See [hardware-io.md §3](hardware-io.md).

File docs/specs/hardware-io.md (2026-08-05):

# Hardware I/O

> Spec: physical pin assignments, input sampling, output writing, LED
> feedback, and boot LED sequences for every hardware variant.  Normative —
> where the implementation disagrees, the implementation is the bug.
> Counterpart to [firmware.md](firmware.md) (composition and tick loop) and
> [inputs.md](inputs.md) / [outputs.md](outputs.md) (language-level leaves
> and sinks).

### Source Files

- `uSEQ/src/firmware/hardware_io.{h,cpp}` — `HardwareIO` struct, all pin maps, `init()`, `read_inputs()`, `write_outputs()`, `update_leds()`, boot LED sequences
- `uSEQ/src/firmware/utils/piopwm.h` — PIO-based PWM program for LED outputs (auto-generated by pioasm)
- `uSEQ/src/firmware/utils/ResponsiveAnalogRead.{h,cpp}` — adaptive-threshold analog smoothing (Music Thing variant)
- `platformio.ini` — variant selection via build environments and `-D` flags

---

## 1. Variant Pin Maps

All pin numbers are RP2040 GPIO indices.  Pin maps are defined inline in
`hardware_io.cpp` under per-variant `#ifdef` guards.  There is no runtime
variant detection.

### 1.1 USEQHARDWARE_1_0

| Function | Pin(s) | Mode | Notes |
|---|---|---|---|
| Gate input I1 | 8 | INPUT_PULLUP | Interrupt-driven (CHANGE) |
| Gate input I2 | 9 | INPUT_PULLUP | Interrupt-driven (CHANGE) |
| Analog input AI1 | 26 | INPUT (ADC) | 11-bit, median-of-51 filter |
| Analog input AI2 | 27 | INPUT (ADC) | 11-bit, median-of-51 filter |
| Momentary switch M1 | 10 | INPUT_PULLUP | |
| Toggle switch T1 (leg A) | 14 | INPUT_PULLUP | 3-way: reads two pins |
| Toggle switch T2 (leg B) | 23 | INPUT_PULLUP | |
| Continuous out A1 | 21 | OUTPUT_2MA | 11-bit PWM, 100 kHz |
| Continuous out A2 | 20 | OUTPUT_2MA | |
| Continuous out A3 | 19 | OUTPUT_2MA | |
| Binary out D1 | 18 | OUTPUT_2MA | |
| Binary out D2 | 17 | OUTPUT_2MA | |
| Binary out D3 | 16 | OUTPUT_2MA | |
| LED A1 | 3 | OUTPUT_2MA, slew slow | PIO PWM, exponential curve |
| LED A2 | 2 | OUTPUT_2MA, slew slow | PIO PWM, exponential curve |
| LED A3 | 11 | OUTPUT_2MA, slew slow | PIO PWM, exponential curve |
| LED D1 | 12 | OUTPUT_2MA, slew slow | analogWrite, proportional |
| LED D2 | 13 | OUTPUT_2MA, slew slow | analogWrite, proportional |
| LED D3 | 22 | OUTPUT_2MA, slew slow | analogWrite, proportional |
| LED I1 | 5 | OUTPUT_2MA | Digital, driven by gate ISR |
| LED I2 | 4 | OUTPUT_2MA | Digital, driven by gate ISR |
| LED AI1 | 25 | OUTPUT_2MA | PDM via 150 µs hardware timer |
| LED AI2 | 24 | OUTPUT_2MA | analogWrite, squared curve |

Counts: 3 continuous, 3 binary, 9 serial (virtual).  No output inversion.

### 1.2 USEQHARDWARE_0_2

| Function | Pin(s) | Mode | Notes |
|---|---|---|---|
| Gate input I1 | 8 | INPUT_PULLUP | |
| Gate input I2 | 9 | INPUT_PULLUP | |
| Momentary switch M1 | 10 | INPUT_PULLUP | |
| Momentary switch M2 | 11 | INPUT_PULLUP | |
| Toggle switch T1 | 14 | INPUT_PULLUP | |
| Toggle switch T2 | 15 | INPUT_PULLUP | |
| Encoder switch R1 | 7 | INPUT_PULLUP | |
| Rotary encoder A | 13 | INPUT_PULLUP | Quadrature decoding |
| Rotary encoder B | 12 | INPUT_PULLUP | |
| Continuous out A1 | 21 | OUTPUT_2MA | |
| Continuous out A2 | 20 | OUTPUT_2MA | |
| Binary out D1–D4 | 19, 18, 17, 16 | OUTPUT_2MA | |
| LED A1 | 3 | OUTPUT_2MA, slew slow | PIO PWM |
| LED A2 | 2 | OUTPUT_2MA, slew slow | PIO PWM |
| LED D1 | 28 | OUTPUT_2MA, slew slow | analogWrite |
| LED D2 | 27 | OUTPUT_2MA, slew slow | analogWrite |
| LED D3 | 26 | OUTPUT_2MA, slew slow | analogWrite |
| LED D4 | 22 | OUTPUT_2MA, slew slow | analogWrite |
| LED I1 | 5 | OUTPUT_2MA | Digital |
| LED I2 | 4 | OUTPUT_2MA | Digital |

Counts: 2 continuous, 4 binary.  No output inversion.  No analog CV inputs.

### 1.3 MUSICTHING

| Function | Pin(s) | Mode | Notes |
|---|---|---|---|
| Gate input I1 | 2 | INPUT_PULLUP | Polled |
| Gate input I2 | 3 | INPUT_PULLUP | Polled |
| Mux input 1 | 28 | INPUT (ADC) | 12-bit, 4x oversampling, ResponsiveAnalogRead |
| Mux input 2 | 29 | INPUT (ADC) | |
| Mux logic A | 24 | OUTPUT | Channel select |
| Mux logic B | 25 | OUTPUT | |
| Audio in L | 26 | INPUT (ADC) | Direct, no mux |
| Audio in R | 27 | INPUT (ADC) | Direct, no mux |
| DAC CS | 21 | OUTPUT | MCP4822 SPI chip select |
| DAC SCK | 18 | — | SPI clock |
| DAC SDI | 19 | — | SPI data |
| Continuous out A3 | 23 | OUTPUT_2MA | PWM (a3/a4 only; aL/aR via SPI DAC) |
| Continuous out A4 | 22 | OUTPUT_2MA | |
| Binary out D1 | 8 | OUTPUT_2MA | |
| Binary out D2 | 9 | OUTPUT_2MA | |
| LED Audio L | 10 | OUTPUT_2MA, slew slow | analogWrite |
| LED Audio R | 11 | OUTPUT_2MA, slew slow | analogWrite |
| LED A3 | 12 | OUTPUT_2MA, slew slow | analogWrite |
| LED A4 | 13 | OUTPUT_2MA, slew slow | analogWrite |
| LED D1 | 14 | OUTPUT_2MA, slew slow | analogWrite |
| LED D2 | 15 | OUTPUT_2MA, slew slow | analogWrite |

Counts: 4 continuous, 2 binary.  Outputs **inverted** (`INVERT_ANALOG = true`, `INVERT_DIGITAL = true`).  First two continuous outputs (aL, aR) use MCP4822 SPI DAC (12-bit, 20 MHz SPI); output pins for those slots are `-1` (no PWM pin).

### 1.4 USEQHARDWARE_EXPANDER_OUT_0_1

| Function | Pin(s) |
|---|---|
| Continuous out 1–8 | 13, 14, 10, 11, 8, 7, 5, 3 |
| LED 1–8 | 15, 20, 17, 12, 9, 6, 2, 0 |
| I2C SDA / SCL | 4 / 1 |

8 continuous, 0 binary, 0 inputs. No inversion. I2C client only; GPIO0
remains LED 8 and must not be used as the generic SDA default. See
[i2c-expander.md](i2c-expander.md).

---

## 2. PWM Configuration

2.1 All variants configure PWM identically:
- `analogWriteFreq(100000)` — 100 kHz, well above audible range.
- `analogWriteResolution(11)` — 11-bit (0–2047).

2.2 Constants: `MAX_PWM_I = 2047`, `MAX_PWM = 2047.0`.

---

## 3. Input Sampling

All inputs are sampled once per tick in `read_inputs()`, before the signal
engine executes.  Values are stored in `HardwareIO::inputs[MAX_HW_INPUTS]`
(doubles, normalised to `[0, 1]` unless noted).

### 3.1 Input Index Convention

Indices are fixed across all variants.  Unused slots on a given variant
hold 0.0.

| Index | Name | Type |
|---|---|---|
| 0 | INP_I1 | Digital gate |
| 1 | INP_I2 | Digital gate |
| 2 | INP_M1 | Momentary switch |
| 3 | INP_M2 | Momentary switch |
| 4 | INP_T1 | Toggle switch |
| 5 | INP_T2 | Toggle switch |
| 6 | INP_RS1 | Encoder switch |
| 7 | INP_R1 | Encoder position (accumulates) |
| 8 | INP_AI1 | Analog CV |
| 9 | INP_AI2 | Analog CV |
| 10 | INP_MAINKNOB | Knob (Music Thing) |
| 11 | INP_XKNOB | Knob (Music Thing) |
| 12 | INP_YKNOB | Knob (Music Thing) |
| 13 | INP_ZSWITCH | Switch (Music Thing) |
| 14 | INP_AUDIO_L | Audio in (Music Thing) |
| 15 | INP_AUDIO_R | Audio in (Music Thing) |

### 3.2 Digital Gate Inputs (v1.0)

Gate inputs on USEQHARDWARE_1_0 are **interrupt-driven**.  ISR functions
attached via `attachInterrupt(..., CHANGE)` capture the pin state on every
edge and update volatile state variables.  A **rising-edge latch** ensures
short pulses are not missed between ticks:

1. ISR fires on pin change → reads pin, stores to `s_gateN_state`.
2. If the new state is HIGH, sets `s_gateN_latched = 1`.
3. `read_inputs()` reads the volatile state; if the latch is set, reports
   1.0 and clears the latch.

The ISR also drives the gate input LED (`LED_I1`/`LED_I2`) via `digitalWrite`
for instant visual feedback with zero main-loop latency.

The rising-edge latch is a new addition.  The original production firmware
used interrupt-driven reads and ISR-driven LEDs (same as now), but wrote
the pin state directly to the input array without latching — a short pulse
that arrived and departed between ticks could be missed by the main loop
(though the ISR still processed it for external clock tracking).  The
original ISR also called `update_clock_from_external()` on rising edges
when the clock source was set to external; in the current firmware, tempo
estimation is handled separately.

On other variants, gate inputs are polled via `digitalRead` in `read_inputs()`.

### 3.3 Toggle Switch (v1.0, 3-way)

Read from two pins (T1 leg A and T1 leg B), both active-low with pull-ups:

| Leg A | Leg B | Value |
|---|---|---|
| 0 | 0 | 1.0 (center) |
| 1 | — | 2.0 (upper) |
| 0 | 1 | 0.0 (lower) |

### 3.4 Momentary Switch

`1.0 - digitalRead(pin)` — active-low with pull-up.  0.0 = released, 1.0 = pressed.

### 3.5 Analog CV Inputs (v1.0)

- ADC resolution: 11-bit (0–2047).
- Normalisation: `raw * (1.0 / 2048.0)` → `[0, 1)`.
- Filtering: **median-of-51** filter operating on normalised doubles.
  Fixed-size circular buffer (51 elements), partial sort via
  `std::nth_element` per tick.  Same window size as the original
  production firmware.  The original used `std::vector` with heap
  allocation; the current implementation uses a fixed-size stack array.
  On startup, the buffer fills progressively (median of `n` available
  samples) rather than the original's all-zeros initialisation — this
  eliminates the brief 0-biased transient the original had.

### 3.6 Analog Inputs (Music Thing)

- ADC resolution: 12-bit (0–4095).
- Mux-based: 4 channels via 2-bit address lines, 8 µs settle delay.
- 4x oversampling: each mux channel read is averaged over 4 ADC samples
  with 1 µs inter-sample delay.
- Filtering: `ResponsiveAnalogRead` per channel (adaptive-threshold
  smoothing with noise gating and activity detection).
- Normalisation: `value * (1.0 / 4096.0)` → `[0, 1)`.
- CV inputs (mux ch 4–5) are inverted: `4095 - raw`.

### 3.7 Rotary Encoder (v0.2)

Quadrature decoding via a 4-bit state table.  The encoder position
(`INP_R1`) is an accumulating counter — it increases/decreases without
bound.  The encoder switch (`INP_RS1`) is a simple active-low digital
read.

---

## 4. Output Writing

`write_outputs()` iterates over `HardwareIO::outputs[]`, which the tick
loop fills from the signal engine's output values before calling this
method.

### 4.1 Continuous Outputs

1. Clamp value to `[0, 1]`.
2. Scale to PWM range: `(int)(val * 2047.0)`, clamped to `[0, 2047]`.
3. If `INVERT_ANALOG` (Music Thing only): `2047 - scaled`.
4. Write output pin via `analogWrite(pin, scaled)`.
5. For Music Thing aL/aR (indices 0–1): write via MCP4822 SPI DAC instead
   (12-bit, scaled from 11-bit range).

### 4.2 Continuous Output LEDs

LED brightness follows the output value with an **exponential (squared)
curve** for perceptually linear brightness:

```
led_val = (scaled * scaled) >> 11
```

On standard hardware (v1.0, v0.2), continuous output LEDs are driven by
**PIO state machines** (one per LED, 11-bit period).  On Music Thing and
Expander, they use `analogWrite`.

The `set_output_led()` helper routes correctly based on variant and LED
index, preventing conflicts between PIO and analogWrite on the same pin.

### 4.3 Binary Outputs

1. Threshold: `val > 0.0` → 1, else 0.
2. If `INVERT_DIGITAL` (Music Thing only): flip the bit.
3. Write via `digitalWrite(pin, dv)`.
4. LED: proportional brightness via `analogWrite(led_pin, (int)(val * 2047))`.

Note: the original production firmware used `digitalWrite(led_pin, val > 0)`
for binary output LEDs (simple on/off).  The current proportional brightness
is a deliberate improvement — it shows signal strength on binary LEDs.

### 4.4 Serial Outputs

Indices beyond the physical output count are virtual.  They are not
written to hardware pins; the serial protocol streams them over USB.  See
[wire-protocol.md](wire-protocol.md).

---

## 5. LED Feedback System

The module provides real-time visual feedback through multiple LED
subsystems.

### 5.1 Output LEDs (all variants)

One LED per physical output.  Continuous output LEDs show signal level
with an exponential brightness curve.  Binary output LEDs show
proportional brightness.  All output LED pins are configured with
`OUTPUT_2MA` drive strength and `GPIO_SLEW_RATE_SLOW` to reduce EMI.

### 5.2 Gate Input LEDs (v1.0)

LED_I1 (pin 5) and LED_I2 (pin 4) are driven directly by the gate input
ISR via `digitalWrite`.  They reflect the physical pin state with
effectively zero latency — no main-loop involvement.

### 5.3 Analog Input LED — AI1 (v1.0, PDM)

LED_AI1 (pin 25) is driven by a **Pulse Density Modulation** timer
running on a 150 µs hardware repeating timer (`add_repeating_timer_us`),
independent of the main tick loop.

Each tick, `read_inputs()` computes a squared+normalised duty cycle from
the raw ADC value:

```
ai1_sq = (raw * raw) >> 11      // squared, 0–2047
pdm_w  = ai1_sq / 2048.0        // normalised, 0.0–1.0
```

The timer callback runs the PDM algorithm:

```
pdm_y   = pdm_w > pdm_err ? 1 : 0
pdm_err = pdm_y - pdm_w + pdm_err
digitalWrite(LED_AI1, pdm_y)
```

This produces smooth, dithered brightness that is visually distinct from
PWM and runs at a consistent rate regardless of main-loop timing.

### 5.4 Analog Input LED — AI2 (v1.0, PWM)

LED_AI2 (pin 24) uses straightforward `analogWrite` with a squared curve:

```
ai2_sq = (raw * raw) >> 11
analogWrite(LED_AI2, ai2_sq)
```

Updated once per tick in `read_inputs()`.

---
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

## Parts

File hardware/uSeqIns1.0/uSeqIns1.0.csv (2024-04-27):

Source: | /home/ck84/Arduino/uSEQ/hardware/version1.0/useq1/useq1.kicad_sch
Date: | Fri 26 Apr 2024 09:10:29 BST
Tool: | Eeschema 7.0.11-7.0.11~ubuntu22.04.1
Generator: | /usr/share/kicad/plugins/bom_csv_grouped_by_value.py
Component Count: | 172
Collated Components:
Item | Qty | Reference(s) | Value | LibPart | Footprint | Datasheet | DNP | Category | DK_Datasheet_Link | DK_Detail_Page | Description | Digi-Key_PN | Family | Height | Link | MPN | Manufacturer | Manufacturer_Name | Manufacturer_Part_Number | Mouser Part Number | Mouser Price/Stock | Sim.Device | Sim.Pins | Status
1 | 2 | C1, C5 | 1u | Device:C | Capacitor_SMD:C_0603_1608Metric_Pad1.08x0.95mm_HandSolder | ~
2 | 2 | C2, C8 | 22u 0805 | Device:C | Capacitor_SMD:C_0805_2012Metric_Pad1.18x1.45mm_HandSolder | ~
3 | 2 | C3, C4 | 22u | Device:C | Capacitor_SMD:C_0805_2012Metric | ~
4 | 2 | C6, C7 | 1nF | Device:C | Capacitor_SMD:C_0402_1005Metric | ~
5 | 3 | C9, C13, C38 | 10u | Device:C | Capacitor_SMD:C_0603_1608Metric | ~
6 | 11 | C10, C11, C14, C16, C17, C18, C20, C21, C24, C33, C37 | 100n | Device:C | Capacitor_SMD:C_0402_1005Metric | ~
7 | 2 | C12, C15 | 1u | Device:C | Capacitor_SMD:C_0402_1005Metric | ~
8 | 13 | C19, C22, C23, C25, C26, C29, C30, C31, C32, C39, C40, C41, C42 | 100n | Device:C | Capacitor_SMD:C_0603_1608Metric | ~
9 | 2 | C27, C28 | 30p | Device:C | Capacitor_SMD:C_0402_1005Metric | ~
10 | 3 | C34, C35, C36 | 10n | Device:C | Capacitor_SMD:C_0402_1005Metric | ~
11 | 2 | D1, D2 | 1N4148W | Diode:1N4148W | Diode_SMD:D_SOD-123 | https://www.vishay.com/docs/85748/1n4148w.pdf |  |  |  |  |  |  |  |  |  |  |  |  |  |  |  | D | 1=K 2=A
12 | 2 | D3, D4 | 1N5819 | Diode:1N5818 | Diode_SMD:D_SOD-323 | http://www.vishay.com/docs/88525/1n5817.pdf
13 | 1 | D5 | LED Gate In 1 | Device:LED | LED_THT:LED_D3.0mm_FlatTop | ~
14 | 1 | D6 | LED Gate In 2 | Device:LED | LED_THT:LED_D3.0mm_FlatTop | ~
15 | 1 | D7 | LED A1 | Device:LED | LED_THT:LED_D3.0mm_FlatTop | ~
16 | 1 | D8 | LED A2 | Device:LED | LED_THT:LED_D3.0mm_FlatTop | ~
17 | 1 | D9 | LED CV In 1 | Device:LED | LED_THT:LED_D3.0mm_FlatTop | ~
18 | 1 | D10 | LED CV In 2 | Device:LED | LED_THT:LED_D3.0mm_FlatTop | ~
19 | 1 | D11 | LED A3 | Device:LED | LED_THT:LED_D3.0mm_FlatTop | ~
20 | 1 | D12 | LED D1 | Device:LED | LED_THT:LED_D3.0mm_FlatTop | ~
21 | 1 | D13 | LED D2 | Device:LED | LED_THT:LED_D3.0mm_FlatTop | ~
22 | 1 | D14 | LED D3 | Device:LED | LED_THT:LED_D3.0mm_FlatTop | ~
23 | 1 | D15 | LED Test | Device:LED | LED_SMD:LED_0603_1608Metric | ~
24 | 2 | FB1, FB2 | FerriteBead GZ2012D101TF | Device:FerriteBead | Resistor_SMD:R_0805_2012Metric | ~
25 | 1 | H1 | PIN_HEADER_2x5 POWER | eurocad:PIN_HEADER_2x5 | Connector_PinHeader_2.54mm:PinHeader_2x05_P2.54mm_Vertical_SMD
26 | 1 | J1 | Hanbo_USB_C_Receptacle_USB2.0_MC-110LD-L137 | emutelab:Hanbo_USB_C_Receptacle_USB2.0_MC-110LD-L137 | emutelab:USB-C-TH_MC-110LD-L137-A | https://www.lcsc.com/product-detail/USB-Connectors_Hanbo-Electronic-MC-110LD-L137_C2962416.html
27 | 1 | J2 | Gate In 1 | Connector:AudioJack2_SwitchT | Connector_Audio:Jack_3.5mm_QingPu_WQP-PJ398SM_Vertical_CircularHoles | ~
28 | 1 | J3 | Gate In 2 | Connector:AudioJack2_SwitchT | Connector_Audio:Jack_3.5mm_QingPu_WQP-PJ398SM_Vertical_CircularHoles | ~
29 | 1 | J4 | CV In 1 | Connector:AudioJack2_SwitchT | Connector_Audio:Jack_3.5mm_QingPu_WQP-PJ398SM_Vertical_CircularHoles | ~
30 | 1 | J5 | CV In 2 | Connector:AudioJack2_SwitchT | Connector_Audio:Jack_3.5mm_QingPu_WQP-PJ398SM_Vertical_CircularHoles | ~
31 | 2 | J7, J8 | Conn_02x01 | Connector_Generic:Conn_02x01 | Connector_PinHeader_2.54mm:PinHeader_1x02_P2.54mm_Vertical | ~
32 | 1 | J9 | Out A1 | Connector:AudioJack2_SwitchT | Connector_Audio:Jack_3.5mm_QingPu_WQP-PJ398SM_Vertical_CircularHoles | ~
33 | 1 | J10 | Out A2 | Connector:AudioJack2_SwitchT | Connector_Audio:Jack_3.5mm_QingPu_WQP-PJ398SM_Vertical_CircularHoles | ~
34 | 1 | J11 | Out A3 | Connector:AudioJack2_SwitchT | Connector_Audio:Jack_3.5mm_QingPu_WQP-PJ398SM_Vertical_CircularHoles | ~
35 | 1 | J12 | Out D1 | Connector:AudioJack2_SwitchT | Connector_Audio:Jack_3.5mm_QingPu_WQP-PJ398SM_Vertical_CircularHoles | ~
36 | 1 | J13 | Out D2 | Connector:AudioJack2_SwitchT | Connector_Audio:Jack_3.5mm_QingPu_WQP-PJ398SM_Vertical_CircularHoles | ~
37 | 1 | J14 | Out D3 | Connector:AudioJack2_SwitchT | Connector_Audio:Jack_3.5mm_QingPu_WQP-PJ398SM_Vertical_CircularHoles | ~
38 | 1 | J15 | SWD | Connector_Generic:Conn_01x03 | Connector_PinHeader_2.54mm:PinHeader_1x03_P2.54mm_Vertical | ~
39 | 2 | Q1, Q2 | MMBT3904 | dk_Transistors-Bipolar-BJT-Single:MMBT3904-TP | Package_TO_SOT_SMD:SOT-23 | https://www.mccsemi.com/pdf/Products/MMBT3904(SOT-23).pdf |  | Discrete Semiconductor Products | https://www.mccsemi.com/pdf/Products/MMBT3904(SOT-23).pdf | /product-detail/en/micro-commercial-co/MMBT3904-TP/MMBT3904TPMSCT-ND/717395 | TRANS NPN 40V 0.2A SOT23 | MMBT3904TPMSCT-ND | Transistors - Bipolar (BJT) - Single |  |  | MMBT3904-TP | Micro Commercial Co |  |  |  |  |  |  | Active
40 | 10 | R1, R2, R4, R5, R7, R8, R9, R10, R11, R12 | 100k | Device:R | Resistor_SMD:R_0402_1005Metric | ~
41 | 2 | R3, R6 | 5.1k | Device:R | Resistor_SMD:R_0402_1005Metric | ~
42 | 2 | R13, R14 | 33k | Device:R | Resistor_SMD:R_0402_1005Metric | ~
43 | 2 | R15, R66 | 1.8, >24mW | Device:R | Resistor_SMD:R_0603_1608Metric | ~
44 | 6 | R16, R17, R19, R20, R67, R68 | 5.1k 1% | Device:R | Resistor_SMD:R_0402_1005Metric | ~
45 | 1 | R18 | 4.7k | Device:R | Resistor_SMD:R_0603_1608Metric | ~
46 | 2 | R21, R22 | 27 | Device:R | Capacitor_SMD:C_0402_1005Metric | ~
47 | 5 | R23, R24, R33, R34, R35 | 18k | Device:R | Resistor_SMD:R_0603_1608Metric | ~
48 | 5 | R25, R26, R27, R28, R32 | 9.1k | Device:R | Resistor_SMD:R_0603_1608Metric | ~
49 | 7 | R29, R59, R60, R61, R62, R63, R64 | 1k | Device:R | Resistor_SMD:R_0402_1005Metric | ~
50 | 1 | R30 | DNF | Device:R | Capacitor_SMD:C_0805_2012Metric | ~
51 | 3 | R31, R37, R65 | 1.5k | Device:R | Resistor_SMD:R_0603_1608Metric | ~
52 | 1 | R36 | 1k | Device:R | Resistor_SMD:R_0603_1608Metric | ~
53 | 3 | R38, R39, R40 | 12k | Device:R | Resistor_SMD:R_0603_1608Metric | ~
54 | 3 | R41, R42, R43 | 1.2k | Device:R | Resistor_SMD:R_0603_1608Metric | ~
55 | 3 | R44, R45, R46 | 33k | Device:R | Resistor_SMD:R_0603_1608Metric | ~
56 | 3 | R47, R48, R49 | 51k | Device:R | Resistor_SMD:R_0603_1608Metric | ~
57 | 6 | R50, R51, R52, R53, R54, R55 | 47k | Device:R | Resistor_SMD:R_0603_1608Metric | ~
58 | 3 | R56, R57, R58 | 27k | Device:R | Resistor_SMD:R_0603_1608Metric | ~
59 | 2 | RV1, RV2 | 100k | Device:R_Potentiometer | Eurocad:Alpha9mmPot | ~
60 | 2 | S1, S2 | B3U-1000P | dk_Tactile-Switches:B3U-1000P | digikey-footprints:Switch_Tactile_SMD_B3U-1000P | https://omronfs.omron.com/en_US/ecb/products/pdf/en-b3u.pdf |  | Switches | https://omronfs.omron.com/en_US/ecb/products/pdf/en-b3u.pdf | /product-detail/en/omron-electronics-inc-emc-div/B3U-1000P/SW1020CT-ND/1534357 | SWITCH TACTILE SPST-NO 0.05A 12V | SW1020CT-ND | Tactile Switches |  |  | B3U-1000P | Omron Electronics Inc-EMC Div |  |  |  |  |  |  | Active
61 | 1 | SW1 | SW_Push | GPBS-850N:GPBS-850N | GPBS850N | http://switches-connectors-custom.cwind.com/Asset/GPBS850NR1.pdf |  |  |  |  |  |  |  | 14.2 |  |  |  | CW Industries | GPBS-850N | 629-GPBS-850N | https://www.mouser.co.uk/ProductDetail/CW-Industries/GPBS-850N?qs=sajaCoHCXPRZB3tbc1cuTA%3D%3D
62 | 1 | SW3 | SW_SPDT | Switch:SW_SPDT | emutelab:Thonk DWB2 | ~
63 | 1 | TP1 | RP2040 Power | Connector:TestPoint_Probe | TestPoint:TestPoint_Pad_1.5x1.5mm | ~
64 | 1 | TP2 | Analog Power | Connector:TestPoint_Probe | TestPoint:TestPoint_Pad_1.5x1.5mm | ~
65 | 2 | TP3, TP9 | 5V reference | Connector:TestPoint_Probe | TestPoint:TestPoint_Pad_1.5x1.5mm | ~
66 | 1 | TP4 | -5V Ref | Connector:TestPoint_Probe | TestPoint:TestPoint_Pad_1.5x1.5mm | ~
67 | 1 | TP5 | CVIn | Connector:TestPoint_Probe | TestPoint:TestPoint_Pad_1.5x1.5mm | ~
68 | 1 | TP6 | CV Out | Connector:TestPoint_Probe | TestPoint:TestPoint_Pad_1.5x1.5mm | ~
69 | 1 | TP7 | Digital Out | Connector:TestPoint_Probe | TestPoint:TestPoint_Pad_1.5x1.5mm | ~
70 | 1 | TP8 | 1V1 | Connector:TestPoint_Probe | TestPoint:TestPoint_Pad_1.5x1.5mm | ~
71 | 2 | U1, U4 | TLV76733DRVR | Regulator_Linear:TLV76733DRVx | Package_SON:WSON-6-1EP_2x2mm_P0.65mm_EP1x1.6mm_ThermalVias | www.ti.com/lit/gpn/TLV767 |  |  |  |  |  |  |  |  | https://jlcpcb.com/partdetail/TexasInstruments-TLV76733DRVR/C2848334
72 | 4 | U2, U8, U9, U10 | TL072 | Amplifier_Operational:TL072 | Package_SO:SO-8_3.9x4.9mm_P1.27mm | http://www.ti.com/lit/ds/symlink/tl071.pdf
73 | 1 | U3 | MCP6002-xMS | Amplifier_Operational:MCP6002-xMS | Package_SO:MSOP-8_3x3mm_P0.65mm | http://ww1.microchip.com/downloads/en/DeviceDoc/21733j.pdf
74 | 3 | U5, U6, U12 | CJ431 SOT-23 | emutelab:CJ431 SOT-23 | Package_TO_SOT_SMD:SOT-23 | http://www.ti.com/lit/ds/symlink/tl431.pdf
75 | 1 | U7 | RP2040 | MCU_RaspberryPi_RP2040:RP2040 | emutelab:RP2040-QFN-56
76 | 1 | U11 | W25Q128JVS | Memory_Flash:W25Q128JVS | Package_SO:SOIC-8_5.23x5.23mm_P1.27mm | http://www.winbond.com/resource-files/w25q128jv_dtr%20revc%2003272018%20plus.pdf
77 | 1 | Y1 | YXC X322512MSB4SI | Device:Crystal_GND24 | Crystal:Crystal_SMD_3225-4Pin_3.2x2.5mm | ~

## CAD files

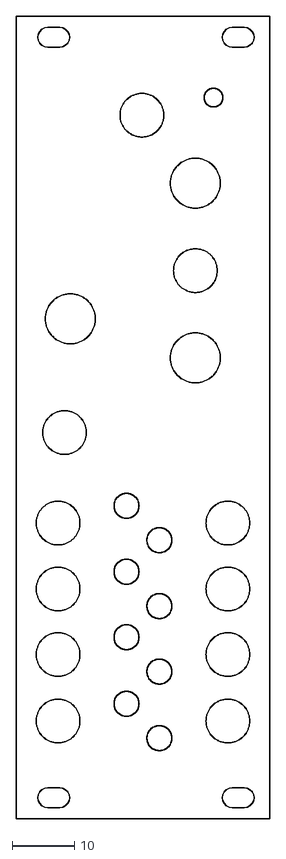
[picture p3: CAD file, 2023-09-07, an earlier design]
hardware/version0.2/panel/useqPanel_export.dxf
40.6 x 128.5

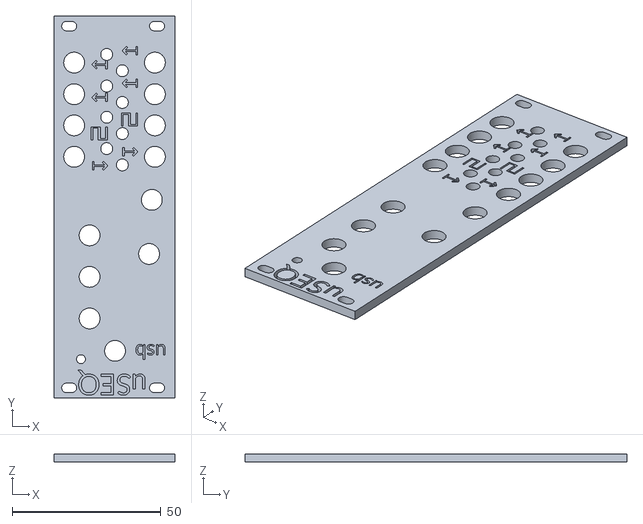
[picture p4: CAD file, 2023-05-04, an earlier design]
hardware/version0.2/panel/useqPanel_v0.2.stl
40.6 x 128.5 x 2.80

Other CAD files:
hardware/version0.2/panel/useqPanel_v0.2.scad

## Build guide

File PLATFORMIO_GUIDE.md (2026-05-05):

# PlatformIO Build System Guide

## Overview

The uSEQ firmware now uses PlatformIO as the recommended build system for hardware targets. PlatformIO provides better dependency management, multiple environment support, and easier configuration management compared to Arduino CLI.

## Quick Start

### Installation (NixOS)

```bash
# Enter PlatformIO development environment
nix-shell platformio.nix

# Or use direnv (edit .envrc first)
# Change: use nix
# To:     use nix platformio.nix
direnv allow
```

### Basic Usage

```bash
# Build for default environment (musicthing)
scripts/pio.sh build

# Build for specific hardware variant
scripts/pio.sh build hardware_v0_2
scripts/pio.sh build hardware_v1_0
scripts/pio.sh build minimal

# Flash to device
scripts/pio.sh flash

# Flash to specific device
scripts/pio.sh flash musicthing /dev/ttyACM0

# Monitor serial output
scripts/pio.sh monitor

# Clean builds
scripts/pio.sh clean

# Show firmware size
scripts/pio.sh size

# List all available environments
scripts/pio.sh list
```

## Hardware Environments

### Production Environments

#### musicthing (Default)
Music Thing Modular hardware variant with all features:
- DSP engine and tempo estimation
- I2C networking (host and client)
- Flash storage for persistent state
- RGB LED control
- Analog inputs and digital I/O
- Rotary encoder support

**Build:** `pio run -e musicthing`

#### hardware_v0_2
uSEQ Hardware v0.2 variant:
- DSP engine
- I2C networking
- Flash storage
- LED control
- Analog inputs
- Rotary encoder

**Build:** `pio run -e hardware_v0_2`

#### hardware_v1_0
uSEQ Hardware v1.0 variant:
- DSP engine and tempo estimation
- I2C networking
- Flash storage
- LED control
- Analog inputs
- No rotary encoder (hardware limitation)

**Build:** `pio run -e hardware_v1_0`

#### minimal
Minimal build with core features only:
- No DSP, no I2C, no flash storage
- Useful for testing and debugging
- Smallest binary size

**Build:** `pio run -e minimal`

### Development Environments

#### musicthing-debug
Debug build with symbols and reduced optimization:
- All musicthing features
- Debug symbols enabled
- USEQ_DEBUG=1 flag
- Better for GDB debugging

**Build:** `pio run -e musicthing-debug`

#### musicthing-verbose
Verbose serial output build:
- All musicthing features
- Extra verbose serial debugging
- VERBOSE_SERIAL=1 flag

**Build:** `pio run -e musicthing-verbose`

### Native Testing Environment

#### native
Desktop build for running tests on the host computer:
- No Arduino dependencies
- Uses standard C++ libraries
- For running unit tests without hardware

**Build:** `pio test -e native`

## Configuration

### platformio.ini Structure

The `platformio.ini` file defines all build configurations:

```ini
[platformio]
default_envs = musicthing    # Default environment

[env]
# Common settings shared by all environments
platform = ...
board = pico
build_flags = ...

[env:musicthing]
# Music Thing specific settings
build_flags = ${env.build_flags}
    -DMUSICTHING
    -DENABLE_DSP_ENGINE
    ...
```

### Adding a New Hardware Variant

1. **Create new environment in platformio.ini:**
   ```ini
   [env:my_hardware]
   build_flags =
       ${env.build_flags}
       -DMY_HARDWARE
       -DENABLE_DSP_ENGINE
       # Add other flags as needed
   ```

2. **Update build scripts** (if needed):
   - Add to `VALID_ENVS` in `scripts/build_pio.sh`
   - Add to `VALID_ENVS` in `scripts/flash_pio.sh`

3. **Test the build:**
   ```bash
   scripts/pio.sh build my_hardware
   ```

## Build System Comparison

### PlatformIO vs Arduino CLI

| Feature | PlatformIO | Arduino CLI |
|---|---|---|
| Multi-environment | ✅ Native | ❌ Manual |
| Dependency mgmt | ✅ Automatic | ⚠️ Manual |
| Build caching | ✅ Yes | ✅ Yes |
| Testing framework | ✅ Built-in | ❌ External |
| CI/CD support | ✅ Excellent | ⚠️ Manual |
| Configuration | ✅ Single file | ❌ CLI flags |

### PlatformIO vs Meson

| Feature | PlatformIO | Meson |
|---|---|---|
| Embedded targets | ✅ Excellent | ⚠️ Complex |
| Desktop targets | ⚠️ Limited | ✅ Excellent |
| Multi-platform | ✅ Yes | ✅ Yes |
| Test framework | ✅ Built-in | ✅ Built-in |
| Build speed | ✅ Fast | ✅ Fast |

**Recommendation:**
- Use **PlatformIO** for hardware/embedded builds
- Use **Meson** for desktop/development builds
- Both systems coexist in this project

## Advanced Usage

### Custom Build Flags

Add temporary build flags:
```bash
pio run -e musicthing -D CUSTOM_FLAG=1
```

### Upload via BOOTSEL Mode

1. Hold BOOTSEL button on Pico
2. Connect USB cable
3. Release BOOTSEL button
4. Run flash command:
   ```bash
   scripts/pio.sh flash
   ```

### Debugging with Serial Monitor

```bash
# Build with verbose output
pio run -e musicthing-verbose

# Flash and immediately monitor
pio run -e musicthing-verbose -t upload && pio device monitor
```

### Building Multiple Environments

```bash
# Build all production environments
for env in musicthing hardware_v0_2 hardware_v1_0; do
    pio run -e $env
done
```

## Troubleshooting

### Build Fails: Platform Not Found

**Problem:** First build fails because platform needs to be downloaded

**Solution:** PlatformIO will automatically download the platform on first build. Be patient.

### Build Fails: Permission Denied

**Problem:** PlatformIO cache directory has wrong permissions

**Solution:**
```bash
rm -rf ~/.platformio
pio run -e musicthing  # Will recreate cache
```

### Upload Fails: Device Not Found

**Problem:** Pico not in bootloader mode or wrong device path

**Solutions:**
1. Put Pico in BOOTSEL mode (hold button while connecting USB)
2. Check device path: `ls /dev/tty*`
3. Use correct device: `scripts/pio.sh flash musicthing /dev/ttyACM0`

### Build Warnings About Conversions

**Problem:** Type conversion warnings in embedded code

**Solution:** These are expected and disabled with `-Wno-conversion` flag in platformio.ini

## File Locations

### Build Output
- Firmware binary: `.pio/build/{env}/firmware.elf`
- UF2 file: `.pio/build/{env}/firmware.uf2`
- Size report: `.pio/build/{env}/firmware.elf.size`

### PlatformIO Cache
- Platform packages: `~/.platformio/platforms/`
- Build cache: `~/.platformio/.cache/`
- Installed tools: `~/.platformio/packages/`

## Migration Notes

### From Arduino CLI

The PlatformIO configuration replicates all Arduino CLI settings:
- FQBN: `rp2040:rp2040:generic` → `board = pico` + platform settings
- Build options: `freq=250,opt=Optimize3` → build_flags in platformio.ini
- Flash layout: `flash=8388608_7340032` → `board_build.filesystem_size = 7M`

Old Arduino CLI builds will continue to work, but PlatformIO is recommended going forward.

### Configuration Migration

Hardware-specific defines previously in `configure.h` are now in `platformio.ini`:

**Before (configure.h):**
```cpp
#define MUSICTHING
#define ENABLE_DSP_ENGINE
```

**After (platformio.ini):**
```ini
[env:musicthing]
build_flags =
    -DMUSICTHING
    -DENABLE_DSP_ENGINE
```

This allows better separation of concerns and easier multi-variant builds.

## Integration with Development Workflow

### With Meson (Desktop Testing)

```bash
# Desktop development cycle
./scripts/build.sh          # Build with Meson
./scripts/test.sh           # Run tests
./build/standalone          # Test interpreter

# Hardware flash cycle
scripts/pio.sh build        # Build firmware
scripts/pio.sh flash        # Flash to device
```

### With direnv

```bash
# .envrc for PlatformIO
use nix platformio.nix

# Then all pio commands work automatically
pio run -e musicthing
```

### With CI/CD

PlatformIO has excellent CI/CD support:
```yaml
# Example GitHub Actions
- name: Install PlatformIO
  run: pip install platformio

- name: Build all variants
  run: |
    pio run -e musicthing
    pio run -e hardware_v0_2
    pio run -e hardware_v1_0
```

## Future Enhancements

Planned improvements to the PlatformIO setup:

1. **Unified testing** - Run Meson tests through PlatformIO native environment
2. **Hardware-in-loop tests** - Automated testing with connected hardware
3. **CI/CD pipeline** - Automated builds and releases
4. **Library management** - Track external dependencies in platformio.ini
5. **Custom scripts** - Pre/post build actions for code generation

---

*Last updated: 2025-09-30*

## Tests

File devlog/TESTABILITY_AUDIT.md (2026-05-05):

# uSEQ Codebase Testability Audit Report

## Executive Summary

The uSEQ codebase shows good progress toward testability with existing test infrastructure covering core LISP interpreter components. However, significant refactoring is needed to enable comprehensive testing of hardware-dependent features in a virtual environment. The main challenge is tight coupling between business logic and hardware I/O operations.

## Current State Analysis

### Strengths

1. **Existing Test Infrastructure**
   - Comprehensive test suite using Catch2 framework
   - Good coverage of core components (Value, Environment, Parser, Interpreter, ModuLisp API)
   - Tests run successfully in desktop environment without hardware
   - Meson build system supports both Arduino and desktop builds

2. **Partial Abstraction**
   - `#ifdef ARDUINO` preprocessor directives provide some hardware/desktop separation
   - Desktop stubs exist for some Arduino functions (millis, micros, delay)
   - ModuLisp interpreter is mostly hardware-independent

3. **Modular Architecture**
   - Clear separation between LISP interpreter core and hardware-specific code
   - OutputManager class provides some abstraction for output handling
   - DSP components are somewhat isolated

### Critical Issues

1. **Tight Hardware Coupling**
   - Direct Arduino API calls throughout codebase (pinMode, digitalWrite, analogRead, etc.)
   - Hardware-specific code mixed with business logic in uSEQ class
   - I2C, SPI, and GPIO operations directly embedded in implementation files
   - No consistent hardware abstraction layer (HAL)

2. **Incomplete Test Coverage**
   - No tests for uSEQ hardware-specific functions
   - I/O operations cannot be tested without hardware
   - DSP engine testing disabled due to removed methods
   - No integration tests for complete signal flow

3. **Dependency Injection Absent**
   - Hardware interfaces are not injected, making mocking impossible
   - Static instance pattern in uSEQ class prevents easy testing
   - Global variables for I2C communication (bNewI2CMessage, i2cInBuff)

4. **Mixed Responsibilities**
   - uSEQ class handles both LISP interpretation and hardware management
   - I/O operations scattered across multiple files (uSEQ_io.cpp, uSEQ_i2c.cpp, etc.)
   - No clear separation between hardware control and business logic

## Testability Assessment by Component

### Component: LISP Interpreter Core
**Testability: GOOD** ✅
- Well-tested with comprehensive unit tests
- Minimal hardware dependencies
- Clear interfaces and predictable behavior

### Component: ModuLisp Extensions
**Testability: MODERATE** ⚠️
- Basic tests exist but could be more comprehensive
- Some timing functions depend on hardware timing
- Beat/bar/phrase calculations could be better isolated

### Component: Hardware I/O (uSEQ_io.cpp)
**Testability: POOR** ❌
- Direct hardware API calls without abstraction
- PIO state machine programming (Pico-specific)
- PWM configuration tightly coupled to hardware
- No way to mock or simulate I/O operations

### Component: I2C Communication
**Testability: POOR** ❌
- Global variables for message passing
- Direct Wire library usage
- No abstraction for multi-module communication
- Cannot test networking logic without hardware

### Component: DSP Engine
**Testability: POOR** ❌
- Runs on separate CPU core (hardware-specific)
- Tests currently disabled
- Tight coupling to hardware audio I/O
- No way to inject test signals or capture output

### Component: Flash Storage
**Testability: VERY POOR** ❌
- Direct flash memory operations
- Hardware-specific memory addresses
- No abstraction for persistence layer
- Cannot test save/load without hardware

## Recommendations for Improved Testability

### 1. Implement Hardware Abstraction Layer (HAL)

Create a proper HAL interface to decouple business logic from hardware:

```cpp
class IHardwareInterface {
public:
    virtual ~IHardwareInterface() = default;
    
    // Digital I/O
    virtual void setPinMode(uint8_t pin, uint8_t mode) = 0;
    virtual void digitalWrite(uint8_t pin, uint8_t value) = 0;
    virtual int digitalRead(uint8_t pin) = 0;
    
    // Analog I/O
    virtual void analogWrite(uint8_t pin, uint16_t value) = 0;
    virtual uint16_t analogRead(uint8_t pin) = 0;
    
    // PWM Configuration
    virtual void configurePWM(uint32_t frequency, uint8_t resolution) = 0;
    
    // Timing
    virtual uint32_t millis() = 0;
    virtual uint32_t micros() = 0;
    
    // I2C
    virtual bool i2cBegin(uint8_t address) = 0;
    virtual size_t i2cWrite(uint8_t address, const uint8_t* data, size_t len) = 0;
    virtual size_t i2cRead(uint8_t address, uint8_t* data, size_t len) = 0;
    
    // Flash/Persistence
    virtual bool saveData(const uint8_t* data, size_t len, uint32_t offset) = 0;
    virtual bool loadData(uint8_t* data, size_t len, uint32_t offset) = 0;
};

// Production implementation
class PicoHardware : public IHardwareInterface {
    // Actual hardware calls
};

// Test implementation
class MockHardware : public IHardwareInterface {
    // Simulated behavior with state tracking
};
```

### 2. Refactor uSEQ Class with Dependency Injection

```cpp
class uSEQ : public ModuLispInterpreter {
private:
    std::unique_ptr<IHardwareInterface> m_hardware;
    std::unique_ptr<OutputManager> m_output_manager;
    
public:
    // Constructor injection for testability
    explicit uSEQ(std::unique_ptr<IHardwareInterface> hw = nullptr);
    
    // Setter injection as alternative
    void setHardware(std::unique_ptr<IHardwareInterface> hw);
};
```

### 3. Create Testable I/O Manager

```cpp
class IOManager {
private:
    IHardwareInterface* m_hardware;
    
public:
    explicit IOManager(IHardwareInterface* hw) : m_hardware(hw) {}
    
    // High-level I/O operations
    void setOutput(size_t channel, float value);
    float readInput(size_t channel);
    void updateOutputs();
    
    // Testable business logic separated from hardware
    float processCV(float raw_value);
    bool shouldTrigger(float current, float previous);
};
```

### 4. Implement Message Bus for I2C

Replace global variables with a proper message passing system:

```cpp
class I2CMessageBus {
public:
    virtual ~I2CMessageBus() = default;
    virtual bool sendMessage(uint8_t address, const Message& msg) = 0;
    virtual bool hasMessage() = 0;
    virtual Message receiveMessage() = 0;
};

class MockI2CBus : public I2CMessageBus {
private:
    std::queue<Message> m_messages;
    // Simulate multi-module communication
};
```

### 5. Create DSP Abstraction

```cpp
class IDSPEngine {
public:
    virtual ~IDSPEngine() = default;
    virtual void process(float* input, float* output, size_t samples) = 0;
    virtual void setParameter(const std::string& name, float value) = 0;
    virtual float estimateTempo() = 0;
};

class MockDSPEngine : public IDSPEngine {
    // Predictable test behavior
};
```

### 6. Implement Test Fixtures

Create comprehensive test fixtures for integration testing:

```cpp
class uSEQTestFixture {
private:
    std::unique_ptr<MockHardware> m_mock_hw;
    std::unique_ptr<uSEQ> m_useq;
    
public:
    void setUp() {
        m_mock_hw = std::make_unique<MockHardware>();
        m_useq = std::make_unique<uSEQ>(m_mock_hw.get());
    }
    
    void simulateClockInput(uint32_t pin, uint32_t interval_us);
    void verifyOutput(uint32_t pin, float expected_value);
    void injectI2CMessage(const std::string& lisp_code);
};
```

### 7. Build System Improvements

Enhance Meson configuration for better test builds:

```meson
# Create separate test configurations
test_with_mocks = executable(
  'test_with_mocks',
  sources: test_sources + mock_sources,
  dependencies: [catch2_dep],
  cpp_args: ['-DUSE_MOCK_HARDWARE']
)

# Hardware simulation tests
hw_sim_tests = executable(
  'hw_sim_tests',
  sources: hw_sim_sources,
  dependencies: [catch2_dep, hw_sim_lib]
)
```

## Implementation Priority

### Phase 1: Foundation (Week 1-2)
1. Define IHardwareInterface and create MockHardware implementation
2. Refactor uSEQ constructor for dependency injection
3. Create basic test fixtures

### Phase 2: Core Refactoring (Week 3-4)
1. Extract I/O operations into IOManager with HAL usage
2. Implement I2CMessageBus abstraction
3. Update existing tests to use mocks

### Phase 3: Comprehensive Testing (Week 5-6)
1. Create integration tests for complete signal paths
2. Implement DSP engine mocking
3. Add timing and synchronization tests

### Phase 4: Advanced Features (Week 7-8)
1. Implement hardware simulation library
2. Create performance benchmarks
3. Add fuzz testing for LISP interpreter

## Testing Strategy

### Unit Tests
- Test each component in isolation with mocks
- Focus on business logic correctness
- Aim for >80% code coverage

### Integration Tests
- Test component interactions
- Verify signal flow from input to output
- Test I2C multi-module communication

### System Tests
- Run complete scenarios with simulated hardware
- Test timing accuracy and jitter
- Verify real-time constraints

### Hardware-in-the-Loop Tests
- Optional tests with actual hardware
- Compare mock behavior with real hardware
- Validate assumptions and timing

## Expected Benefits

1. **Faster Development**: Run tests without hardware
2. **Better Coverage**: Test edge cases and error conditions
3. **Regression Prevention**: Catch bugs before deployment
4. **Documentation**: Tests serve as usage examples
5. **Refactoring Confidence**: Make changes without fear
6. **CI/CD Integration**: Automated testing in pipelines
7. **Hardware Independence**: Develop features without hardware access

## Risks and Mitigation

### Risk: Performance Impact
**Mitigation**: Use templates and compile-time polymorphism where virtual calls are too expensive

### Risk: Increased Complexity
**Mitigation**: Keep abstractions simple and well-documented

### Risk: Divergence from Hardware Behavior
**Mitigation**: Regular hardware validation tests

## Conclusion

The uSEQ codebase requires significant refactoring to achieve comprehensive testability. The primary focus should be on introducing a Hardware Abstraction Layer and implementing dependency injection throughout the system. While this requires substantial initial effort, the long-term benefits in maintainability, reliability, and development speed will be significant.

The existing test infrastructure provides a solid foundation to build upon, and the modular architecture of the LISP interpreter shows that testable design is achievable. By following the recommendations in this audit, the project can achieve professional-grade testability suitable for a production embedded system.

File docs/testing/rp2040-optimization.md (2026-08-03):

# RP2040 optimization and acceptance

This document defines the evidence model for reducing the uSEQ compiler and
runtime while preserving language and failure semantics. It covers the Music
Thing RP2040 profile: 264 KiB of SRAM, with 256 KiB main RAM plus two 4 KiB
scratch banks used by the linked core stacks, and a 2 MiB sketch partition in
the configured 16 MiB external flash.

## Acceptance order

Optimization proceeds through four distinct grades. A later grade supplements
rather than replaces the earlier ones.

1. **Exact link:** build the production and observation ELFs with the pinned
   PlatformIO toolchain. `rp2040_memory_report.py` reads sections and linker
   symbols rather than relying on the generic size summary.
2. **Native firmware-capacity profile:** compile the real compiler and executor
   with `USEQ_FIRMWARE_PROFILE`. Run the full 85-case conformance corpus, the
   declared capacity corpus, and optimized plus ASan/UBSan endurance binaries.
   This grade tests retained limits and recovery on the host; its timing is not
   RP2040 timing evidence.
3. **Automated simulator:** boot the exact `musicthing-observe` ELF, exercise
   the production serial protocol, drive GPIO inputs, capture output pins, and
   collect runtime heap, stack, tick, resource, and reset telemetry.
4. **Physical device:** repeat the release subset on the program card. This is
   the authority for USB behavior, actual timing, clock configuration, PIO,
   DMA, multicore behavior, electrical I/O, and allocator behavior on silicon.

The full local grades run with:

```bash
nix-shell --run 'python3 scripts/run_rp2040_profile.py'
```

The hosted simulator grade runs with:

```bash
nix-shell --run 'python3 scripts/run_wokwi_rp2040.py'
```

For an optimization candidate, run all non-physical grades through the
non-overwriting composition command:

```bash
nix-shell --run 'python3 scripts/run_rp2040_goal_gate.py'
```

The tracked Nix shell includes PyYAML for the shared conformance runner and
the native C++, Meson, Emscripten, Binaryen, WABT, and Node.js tool classes
used by the composed gate. Candidate comparisons must use one unchanged
Nixpkgs revision or channel state; entering a newly updated channel is a
toolchain change and requires a new baseline.

Each local summary records the resolved executable path and first version line
for C++, Meson, Ninja, PlatformIO, Emscripten, Binaryen, WABT, Node.js, and
Python. The composed candidate summary carries this snapshot together with
the Wokwi version/model record, making a comparison-series environment change
visible in the same evidence used for retention.

`platformio.ini` pins the RP2040 platform repository to commit
`aa70b802be8851668053d4f09734e4089fe41932`. After each exact target link, the
local summary includes the resolved PlatformIO framework and tool package
report plus its SHA-256. Measurements from another platform revision are a
different baseline even when the firmware source revision is unchanged.

On the VPS, PlatformIO 6.1.18 is installed in the isolated
`~/.cache/useq-rp2040-goal/platformio-6.1.18` virtual environment. The Nixpkgs
PlatformIO wrapper requires bubblewrap user namespaces, which the production
VPS denies. The preparation script exposes only a `pio` shim from that
environment; `shell.nix` retains its own Python and the rest of the Nix
toolchain. This exception can be removed when the host supports the Nix
wrapper or an unwrapped Nix package is adopted.

## Current budgets

Static gates are encoded in `scripts/rp2040_budget.json`:

- at least 96 KiB of linked main-RAM heap remains after static allocation;
- the flash image occupies at most 1 MiB of the 2 MiB sketch partition.

The firmware workload manifest defines complexity as measured utilization,
not as an informal program label. The combined-high workload simultaneously
uses at least 40% of nodes and 50% each of data entries, state slots, and live
slots while retaining at least 15% node and arena headroom. Focused workloads
exercise 70–100% of individual retained capacities. Every workload must
compile without diagnostics, execute one million finite-output ticks, and
survive 200 same-session recompiles.

The initial target-runtime acceptance thresholds are:

- `heap_min_free >= 49152` bytes during the complete combined workload;
- the core-0 watermark is initialized over the expected 2048-byte linked
  reserve, `core0_stack_margin_intact == true`, and at least 512 bytes remain
  outside the observed high-water mark;
- no allocation failure, protocol overflow affecting required responses,
  non-finite output, watchdog reboot, or unexpected reset;
- combined-high tick p99 below 1 ms, consistent with the current approximately
  1 kHz control-rate contract, and at least 1,000 completed ticks per simulated
  second during a minimum 30-second sustained observation;
- at least 300 target tick samples are delivered at a requested 20 Hz during
  that observation, with a strictly increasing target tick counter;
- every resource sample reports the configured 250 MHz target clock, so timing
  evidence cannot silently come from a simulator or image running another
  clock configuration;
- every individual compilation below the 200 ms watchdog interval, with
  moderate-workload compile p99 below 10 ms and combined/high compile p99
  below 100 ms.

These are safety and responsiveness gates, not measured claims. They become
claims only when the observation image records them. A threshold may be made
stricter from evidence; weakening one requires an explicit change to this
document and its executable budget.

## Simulator boundary

Wokwi is the intended automated peripheral lane because its CLI can boot an
ELF, expose serial through RFC2217, run input scenarios, and record GPIO as
VCD. The test runner should use the normal wire protocol for program eval,
live inputs, and devtools queries. GPIO results should be observed externally
through connected components or VCD rather than inferred from firmware state.

Wokwi is not the memory authority. Capacity is enforced by the exact linker
and measured by firmware telemetry. Its RP2040 model currently executes one
core and does not represent every USB, PIO, DMA, flash, or timing property.
The Wokwi lane is therefore bounded to serial/GPIO functional checks and
repeatable workload automation; endurance and target timing remain mandatory
on a physical card before release-level hardware claims.

The tracked `wokwi/diagram.json` models the two active-low gate inputs and
captures direct outputs `d1`, `d2`, `a4`, and `a3` with an external logic
analyzer. The generated scenario uses the production JSONL protocol to run two
cycles each of the moderate and combined-high corpora, polls target-side
compiler durations, then sustains the combined workload for at least 30
simulated seconds while sampling tick duration and target tick-count progress.
It verifies every required response and transport counter, rejects receive
overflow, exercises one controlled invalid replacement, records fixed-resource
high-water values, checks retained resources and output health, and validates
both scenario pin assertions and VCD transitions.

The CLI requires a token and consumes hosted simulation quota. On the VPS,
install the official CLI in the account PATH and load `WOKWI_CLI_TOKEN` from
the server secret environment; never place it in the repository, shell
history, logs, or evidence. The sustained optimization loop runs native and
exact-link grades before Wokwi for every candidate and schedules the physical
subset only for retained candidates. Candidate comparisons use the same
compiler toolchain and Wokwi CLI version.

## Goal-loop contract

The goal loop optimizes one named resource cause per candidate. It may change
representation, layout, algorithms, and target-specific lowering, but it may
not reduce a public language or workload capacity, weaken a conformance case,
remove a failure/recovery assertion, or raise a budget merely to admit a
candidate. Each candidate is retained only when the complete goal gate passes
and its before/after evidence improves a named flash, static-RAM, runtime-
headroom, compilation, or tick metric without a material regression elsewhere.

The loop stops when the production image and observation image satisfy their
static gates, the moderate and combined-high target workloads satisfy every
runtime gate, and further changes do not yield a reproducible improvement.
This stopping condition is a comfortable-fit criterion, not merely successful
linking. Physical-device evidence remains required before timing or endurance
is attributed to the program card itself.

## Optimization discipline

- Preserve the conformance corpus and transactional rejection behavior.
- Change one named resource cause at a time and retain before/after ELF and
  workload JSON.
- Do not infer target timing from x86 measurements or memory headroom from a
  simulator process.
- Do not reduce a public capacity unless the implemented capability contract
  proves the removed combinations unreachable or the specification is changed
  explicitly.
- A failed workload must leave the previous program executable and all bounded
  resources reusable; accepting a diagnostic alone is insufficient.

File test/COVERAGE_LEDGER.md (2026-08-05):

# Signal Compiler Coverage Ledger

Maps `docs/specs/` sections to C++ test coverage. Updated alongside code changes.

## Legend
- **Strict**: deterministic C++ assertion exists with value checks
- **WARN**: test exists but is non-strict (e.g. checks compile-only, not semantics)
- **None**: no test coverage for an implemented feature
- **N/A**: not yet implemented (deferred)

## Test File Key
- **golden** = `test/signal_engine/test_signal_engine_golden.cpp` — user-visible semantic tests
- **node** = `test/signal_engine/test_signal_engine.cpp` — node-shape / internal tests
- **e2e** = `test/firmware/test_firmware_e2e.cpp` / `test_firmware_e2e_part2.cpp` — firmware E2E
- **fuzz** = `test/firmware/test_firmware_fuzz.cpp` — fuzz tests
- **audit** = `test/signal_engine/test_audit_fixes.cpp` — adversarial regression tests
- **i2c-expander** = `test/firmware/test_i2c_expander.cpp` — native host/client fake-bus simulation

## i2c-expander.md

| Section | Feature | Status | Test File | Test Name |
|---|---|---|---|---|
| 1.1-1.3 | Client selection, expander pins, synth-free value sink | Strict | i2c-expander + target ELF gate | "expander build selects client mode and the PCB bus pins" |
| 2.1-2.2 | `$gettype` discovery and `aout08` response | Strict | i2c-expander | "fake bus discovers an expander and delivers all eight outputs" |
| 3.1-3.3 | `$vals` binary64-LE framing, validation, clamping | Strict | i2c-expander | codec, validation, and integration cases |
| 4.1-4.3 | Bounded callback queue, LKG on NACK, recovery | Strict | i2c-expander | queue and recovery cases |
| 5.2 | Physical electrical behavior | None | -- | Requires expander PCB or wired Pico surrogate |

---

## MAIN.md

| Section | Feature | Status | Test File | Test Name |
|---|---|---|---|---|
| 1.1 | ModuLisp is the live-coding language | -- | -- | (framing, not testable) |
| 1.2 | Outputs keep producing across edits/errors | Strict | golden | "compile error leaves previous output running" |
| 1.3 | Not a general-purpose language | -- | -- | (framing, not testable) |
| 1.4 | Two dialects (Reactive/Imperative) | N/A | -- | Imperative dialect not implemented in signal engine |
| 1.5 | WASM and firmware interchangeable | -- | -- | (arch constraint, not unit-testable) |
| 2.1 | Compile error must not stop the music | Strict | golden | "compile error leaves previous output running" |
| 2.2 | Runtime error falls back to LKG | Strict | node | "LKG fallback: output with no graph uses last known good value" |
| 2.3 | LKG is observed safety | Strict | node | "LKG fallback" tests |
| 2.4 | Diagnostics are structured | Strict | golden | "unknown names produce a diagnostic with fuzzy suggestions" |
| 2.5 | Diagnostics survive across evals | None | -- | No test for per-output health persistence |
| 2.6 | Diagnostic framing is "doesn't support this here" | Strict | golden | "side effects are rejected inside output expressions" |
| 2.7 | Numerical errors not silently zeroed | Strict | node | "LKG fallback" tests check NaN/Inf |
| 3.1 | Hot path never allocates | -- | -- | (performance constraint, not unit-testable) |
| 3.2 | Recompilation is sub-tick | -- | -- | (performance, not unit-testable) |
| 3.3 | Invalidation proactive, recompilation lazy | Strict | node | "Dependency tracking: cell changes trigger recompilation" |
| 3.4 | Pervasive constant folding | Strict | node | "Constant folding: transitive chains", "all unary ops", "all binary ops" |
| 3.5 | Tick rate ~1 kHz | -- | -- | (deployment constraint, not unit-testable) |
| 4.1-4.4 | Stable compatibility surface | -- | -- | (policy, not testable) |
| 5.1-5.9 | Open/deferred cross-cutting | N/A | -- | Open questions, not testable yet |

## values-types.md

| Section | Feature | Status | Test File | Test Name |
|---|---|---|---|---|
| 1.1 | Clojure-shaped value tower | -- | -- | (framing) |
| 1.2 | Parser-level first-class values | Strict | node | "Tokenizer: basic tokens" |
| 1.3 | Numbers are doubles | Strict | golden | "constant arithmetic" |
| 1.4 | Truthiness: non-zero is true | Strict | golden | "numeric truthiness treats any non-zero as true" |
| 1.4 | Comparison returns 1.0/0.0 | Strict | node | "Graph builder: comparisons" |
| 1.5 | nil/0 are false | Strict | golden | "if without else defaults to zero", "nil is falsy in if" (coverage) |
| 1.6 | Signal context type-restricted by reachability | -- | -- | (arch constraint) |
| 1.7 | Vectors are first-class signal data | Strict | golden | "step over literal vector", node: "Graph builder: step function" |
| 1.8 | Callables in signal context are pure | Strict | golden | "defn with one argument inlines at call site" |
| 1.9 | nil is a value, not an error; unbound is compile-time error | Strict | golden | "unknown names produce a diagnostic" |
| 2.1 | Keywords are first-class | N/A | -- | Keyword arguments not yet in signal engine |
| 2.2 | Trailing keyword arguments | N/A | -- | Not yet implemented |
| 2.3 | Keyword parsing rules | N/A | -- | Not yet implemented |
| 2.4 | Keyword args are compile-time contract | N/A | -- | Not yet implemented |
| 3.1-3.3 | Open/deferred (maps, non-numeric roots, integers) | N/A | -- | Open questions |

## signal-model.md

| Section | Feature | Status | Test File | Test Name |
|---|---|---|---|---|
| 1.1 | Implicit lifting: every expression is f(t) | Strict | golden | "constant arithmetic", "raw t is seconds" |
| 1.2 | Concrete lifting examples | Strict | golden | "constant folding is time-invariant", "raw t is seconds" |
| 1.3 | No explicit lambda wrapper | Strict | golden | all output assignments are implicitly lifted |
| 1.4 | Operators combine signals pointwise | Strict | golden | "constant arithmetic", "fractional arithmetic" |
| 1.5 | Canonical time input is t | Strict | golden | "raw t is seconds" |
| 1.6 | Sampling boundaries are engine concern | -- | -- | (arch constraint) |
| 1.7 | No hidden state on hot path | Strict | node | node-shape tests verify no allocations |
| 1.8 | Deterministic pseudorandomness | Strict | node | "random: deterministic per-beat hash", "index-rand: deterministic hash" |

## time.md

| Section | Feature | Status | Test File | Test Name |
|---|---|---|---|---|
| 1.1 | t is seconds, monotonic | Strict | golden | "raw t is seconds" |
| 1.1.1 | t0 unaffected by time mods | N/A | -- | t0 not implemented in signal engine |
| 1.1.2 | ground-time never resets | N/A | -- | ground-time not implemented in signal engine |
| 1.1.3 | Pause excludes wall time; resume/rewind use zero dt; stop is pause+rewind | Strict | e2e | "Playback: pause excludes wall time from logical time", "Playback: rewind and stop preserve programs and state" |
| 1.2 | Phasor: beat wraps 0->1 | Strict | golden | "beat phasor at 120 bpm", "beat phasor at 60 bpm" |
| 1.2 | Phasor: bar wraps 0->1 | Strict | golden | "bar phasor at 120 bpm 4/4" |
| 1.2 | Phasor: phrase | Strict | golden | "phrase phasor uses bars-per-phrase default" |
| 1.2 | Phasor: section | Strict | golden | "section phasor uses phrase defaults" |
| 1.3 | Beat counters: beat-num | Strict | golden | "beat-num is an unwrapped counter" |
| 1.3 | Beat counters: bar-num | Strict | golden | "bar-num is an unwrapped counter" |
| 1.3.1 | Phasors re-derived inside time-as | None | -- | No test for phasor re-derivation inside time-as |
| 1.4 | Durations: beat-dur | Strict | golden | "beat-dur follows bpm" |
| 1.4 | Durations: bar-dur | Strict | golden | "bar-dur follows metre" |
| 1.5 | Timing cells are ordinary cells | Strict | node | "set-bpm affects beat phasor" |
| 1.6 | Phasors bipolar-domain agnostic | Strict | golden | "usin is unipolar sine over phase" |
| 1.7 | Mathematical primitives bipolar by default | Strict | node | "Graph builder: waveforms" |

## time-warps.md

| Section | Feature | Status | Test File | Test Name |
|---|---|---|---|---|
| 1.1-1.3 | Two ideas: substitution vs rate integration | -- | -- | (framing) |
| 2.1 | Profunctor: premap/postmap | None | -- | No direct premap test (fast/slow test it indirectly) |
| 2.2 | time-as user-facing substitution | None | -- | No direct time-as test in golden (only fast/slow sugars tested) |
| 2.3 | Substitution is pointwise and pure | Strict | golden | "fast doubles local time", "slow halves local time" |
| 2.4 | Dynamic substitution is valid but not phase-coherent | Strict | golden | "dynamic fast is pointwise substitution" |
| 3.1 | fast sugar | Strict | golden | "fast doubles local time" |
| 3.1 | slow sugar | Strict | golden | "slow halves local time" |
| 3.1 | offset sugar | Strict | golden | "offset uses seconds" |
| 3.1 | shift alias | Strict | golden | "shift aliases offset" |
| 3.2 | Dynamic args are stateless substitution | Strict | golden | "dynamic fast is pointwise substitution" |
| 3.3 | Hint for dynamic fast on oscillator-like | N/A | -- | Hint policy not implemented |
| 3.4 | Musical offsets via beat-dur | Strict | golden | "musical offset can use beat-dur" |
| 3.5 | Constant affine compose/flatten | Strict | golden | "nested constant warps compose" |
| 4.1-4.3 | Rate clocks are not warps | N/A | -- | rate-as not implemented |
| 5.1-5.2 | Open/deferred | N/A | -- | |

## cells.md

| Section | Feature | Status | Test File | Test Name |
|---|---|---|---|---|
| 1.1 | define creates/replaces a cell | Strict | node | "Cold eval: define number", "Cold eval: redefine overwrites" |
| 1.2 | Cells are reactive bindings | Strict | golden | "redefining a depended-on cell recompiles output" |
| 1.3 | User model: changed cell, signals follow | Strict | golden | "redefining a depended-on cell recompiles output" |
| 1.4 | Recompilation is sub-tick | -- | -- | (performance, not unit-testable) |
| 1.5 | Dependency tracking by symbol identity | Strict | node | "Dependency tracking: cell changes trigger recompilation" |
| 1.6 | Diamond/cascading dependencies | Strict | golden | "diamond dependency: redefining root propagates through chain" |
| 1.7 | Redefining unused cell is no-op | None | -- | No explicit test |
| 1.8 | Cells not stateful in reactive mode | Strict | golden | "expression cell is time-varying" |
| 1.9 | Cell body is a signal expression | Strict | golden | "expression cell is time-varying" |
| 1.10 | Cell redefs from any source | -- | -- | (arch constraint) |

## functions.md

| Section | Feature | Status | Test File | Test Name |
|---|---|---|---|---|
| 1.1 | defn, fn, lambda produce callables | Strict | golden | "defn with one argument inlines at call site"; lambda: golden "fn anonymous lambda in signal context is rejected" |
| 1.2 | Callables inlined at call site | Strict | golden | "defn with one argument inlines at call site" |
| 1.3 | Recursion is compile-time error | Strict | golden | "recursion is rejected instead of hanging" |
| 1.4 | Higher-order returning callables | None | -- | No test for nested callable returns |
| 1.5 | Callables in cells with dependency tracking | Strict | golden | "function redefinition recompiles callers" |
| 1.6 | Top-level callables are first-class | Strict | node | "Defn and user function calls" |
| 1.7 | Variadic arithmetic left-folded | Strict | golden | "variadic addition", "variadic subtraction left folds", "unary negation form" |
| 1.8 | Local time context is lexical through inlining | Strict | golden | "defn inherits caller time context" |
| 1.9 | Keyword arguments | N/A | -- | Not yet implemented |
| 2.1 | Open: closures escaping signal context | N/A | -- | |

## outputs.md

| Section | Feature | Status | Test File | Test Name |
|---|---|---|---|---|
| 1.1 | Standard outputs a1-a8, d1-d8, s1-s8 | Strict | node | "Multiple outputs: a1 and d1 simultaneously" |
| 1.2 | Output assignment is top-level form | Strict | golden | all assign_ok calls |
| 1.3 | Numeric literal, including zero, is a running constant signal | Strict | golden | "unassigned outputs use neutral zero" (0 case); node: constant output tests |
| 1.4 | Active program/source and last healthy scalar sample | Strict | node | "commit_outputs updates prev_output_values and lkg" |
| 1.5 | Reassignment replaces active program | Strict | node | "Output reassignment silently replaces" |
| 1.6 | q0 scheduling callback | Strict | e2e | "G1: Queued command executes at bar boundary" |
| 1.7 | Unassigned outputs produce 0 | Strict | golden | "unassigned outputs use neutral zero" |
| 1.8 | Runtime errors fall back to LKG | Strict | node | "LKG fallback" tests |
| 1.9 | Clear removes outputs/LKG and next running tick emits neutral zero | Strict | audit+e2e | "Inactive outputs overwrite reused caller buffers with neutral zero", "Playback: clear resets everything" |

## prev.md

| Section | Feature | Status | Test File | Test Name |
|---|---|---|---|---|
| 1.1 | Current sample not readable from other outputs | Strict | golden | "bare output reference reads previous committed sample" |
| 1.2 | (prev a1) reads previous sample | Strict | golden | "explicit prev reads previous committed sample" |
| 1.3 | Bare output name is sugar for prev | Strict | golden | "bare output reference reads previous committed sample"; node: "Bare output reference" |
| 1.4 | prev within batch reads preceding sample | None | -- | Batch prev semantics not tested |
| 1.5 | First sample reads neutral default | Strict | golden | "bare output reference reads previous committed sample" (first tick is 0.0) |
| 1.6 | prev enables feedback loops | Strict | golden | "self-reference via prev for integration" |
| 1.7 | prev does not introduce hidden state | -- | -- | (design constraint, not testable) |
| 1.8 | prev of undeclared output rejected; self-ref allowed | Strict | node | "(prev non-output) is an error", "(prev a1) explicit form" |
| 2.1 | Open: prev window across batches | N/A | -- | |

## inputs.md

| Section | Feature | Status | Test File | Test Name |
|---|---|---|---|---|
| 1.1 | External leaves besides t | Strict | golden | "hardware input leaves read injected input values" |
| 1.2 | in1, in2 digital gates | Strict | golden | "hardware input leaves read injected input values" (in1) |
| 1.3 | ain1, ain2 analog CV | Strict | golden | "hardware input leaves read injected input values" (ain1) |
| 1.4 | swm/swt switch values | None | -- | No test for switch inputs |
| 1.5 | swr encoder switch | None | -- | No test for encoder switch |
| 1.6 | rot encoder position | None | -- | No test for encoder position |
| 1.7 | Inputs sampled once per tick | -- | -- | (arch constraint) |
| 1.8 | WASM inputs default to neutral | Strict | golden | implicit: hw_inputs init to 0 |
| 1.9 | Unsupported input is compile-time error | None | -- | No test for variant-gated inputs |

## top-level.md

| Section | Feature | Status | Test File | Test Name |
|---|---|---|---|---|
| 1.1 | Top level is eval surface | Strict | node | "Cold eval" tests |
| 1.2 | No @ prefix | -- | -- | (historical note) |
| 1.3 | Quantised eval is editor concern | -- | -- | (not testable here) |
| 1.4 | define | Strict | node | "Cold eval: define number" |
| 1.4 | defn | Strict | node | "Cold eval: defn creates callable" |
| 1.4 | let | Strict | golden | "let creates local scope"; node: "Graph builder: let" |
| 1.4 | do | Strict | node | "Graph builder: do returns last" |
| 1.4 | if | Strict | golden | "if without else defaults to zero"; node: "Graph builder: if" |
| 1.4 | Output assignment a1-s8 | Strict | golden | all assign_ok tests |
| 1.4 | Transport: useq-play etc | Strict | node | "Cold eval: play/pause/stop/rewind" |
| 1.4.1 | useq-clear is fresh-session equivalent for in-memory storage | Strict | audit | "Clear is fresh-session equivalent for compiler-owned storage" |
| 1.4.2 | Transport preserves programs/state and obeys logical-time boundaries | Strict | e2e | "Playback: pause excludes wall time from logical time", "Playback: rewind and stop preserve programs and state" |
| 1.4 | setbpm | Strict | node | "Cold eval: set-bpm changes bpm cell" |
| 1.4 | settimesig | Strict | node | "Cold eval: set-time-sig changes beats-per-bar" |
| 1.4 | schedule/unschedule | N/A | -- | Not implemented in signal engine |
| 1.4 | eval (dynamic) | None | -- | No test for dynamic eval |
| 1.4 | print, perf, timeit | None | -- | No test for diagnostic side-effects |
| 1.5 | Top-level forms eagerly evaluated | Strict | node | "Cold eval" tests |
| 1.6 | Compiler may compile top-level to graph | -- | -- | (implementation detail) |
| 2.1 | Open: schedule/unschedule | N/A | -- | |

## compilation.md

| Section | Feature | Status | Test File | Test Name |
|---|---|---|---|---|
| 1.1 | Every signal is a node graph | Strict | node | All graph builder tests |
| 1.2 | Compilation passes | Strict | node | Constant folding, CSE tests verify pass results |
| 1.3 | Pervasive constant folding | Strict | node | "Constant folding: transitive chains", "all unary ops", "all binary ops", "all ternary ops" |
| 1.4 | Time-substitution flattening | Strict | golden | "nested constant warps compose" |
| 1.5 | Node graph is not always a signal | -- | -- | (arch observation) |
| 1.6 | Dependency set | Strict | node | "Dependency tracking: cell changes trigger recompilation" |
| 1.7 | Invalidation proactive, recompilation lazy | Strict | node | dependency tracking tests |
| 1.8 | for unrolled at compile time | Strict | node | "Graph builder: for with literal vector", "for with range" |
| 1.9 | Higher-order on constant collections | None | -- | No test for map/reduce/filter |
| 1.10 | Numerical health: NaN/Inf | Strict | node | LKG fallback tests |
| 1.11 | Sub-tick guarantees | -- | -- | (performance, not unit-testable) |
| 2.1 | State-slot allocation | N/A | -- | defstate not implemented |
| 2.2 | CSE for state-bearing nodes | N/A | -- | Not implemented |
| 2.3 | State migration across recompilation | N/A | -- | Not implemented |
| 2.4 | dt is per-tick input | N/A | -- | Not implemented |
| 2.5 | Constant folding across state | N/A | -- | Not implemented |
| 2.6 | No symbolic-integration pass | -- | -- | (design decision, not testable) |
| 2.7 | Keyword arguments affect lowering | N/A | -- | Not implemented |
| 3.1 | Signal context definition | -- | -- | (framing) |
| 3.2 | Side-effect forms rejected | Strict | golden | "side effects are rejected inside output expressions" |
| 3.3 | Side effects rejected in subtree | Strict | node | "Negative: nested side-effect" |
| 3.4 | Reachable callables checked transitively | None | -- | No test for transitive side-effect checking through callables |
| 3.5 | Recursion rejected | Strict | golden | "recursion is rejected instead of hanging" |
| 3.5 | Mutual recursion rejected | Strict | node | "Mutual recursion detected", "Three-way mutual recursion" |
| 3.6 | Dynamic eval rejected | None | -- | No test for eval-in-signal rejection |
| 3.7 | Unresolvable symbols with fuzzy match | Strict | golden | "unknown names produce a diagnostic with fuzzy suggestions" |
| 3.8 | Type errors compiler can prove | None | -- | No test for type error diagnostics |
| 3.9 | Dynamic affine sugar allowed | Strict | golden | "dynamic fast is pointwise substitution" |
| 3.10 | Plain language diagnostics | Strict | golden | message substring checks |
| 3.11 | Diagnostic framing | Strict | golden | "side effects are rejected" message check |
| 4.1-4.3 | Open: while, FP determinism, locally-scoped state | N/A | -- | |
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

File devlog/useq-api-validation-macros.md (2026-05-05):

# uSEQ API Validation Macro System Design

## Overview

This document describes the design and implementation of a new macro-based validation system for uSEQ API functions that addresses performance, maintainability, and automatic registration concerns.

## Problem Statement

The current uSEQ API function implementation has several issues:

1. **Repetitive validation code** - Each function manually validates arguments with boilerplate code
2. **Inconsistent error messages** - Different functions report errors differently
3. **Manual registration** - Functions must be manually registered in `init_builtinfuncs()`
4. **Performance concerns** - Validation code isn't optimized for the common case
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

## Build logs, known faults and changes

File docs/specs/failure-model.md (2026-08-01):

# Failure Model

> Spec: compile-time vs runtime errors, LKG fallback, diagnostic survival,
> per-output health states, success feedback, REPL-vs-output channels,
> batch-eval isolation, cascade-noise mitigation, chain-of-blame.
> Counterpart to [MAIN.md](MAIN.md). See [compilation.md §3](compilation.md)
> for the compile-time rejection rules in signal context, and
> [diagnostics.md](diagnostics.md) for the on-wire diagnostic data shapes.

### Source Files

- `uSEQ/src/signal_engine/executor.{h,cpp}` — `execute_all_outputs()` (per-output isolation, LKG fallback via `OutputSlot.lkg_value`), `commit_outputs()` (LKG promotion), `commit_state()` (state-slot updates)
- `uSEQ/src/signal_engine/node_pool.h` — `OutputSlot` (`root_node`, active-assignment `valid`, `lkg_value`, independent `has_lkg`); runtime output/state failure masks
- `uSEQ/src/signal_engine/graph_builder.{h,cpp}` — compile-time error reporting (`report_error`, `report_error_cat`, `report_warning`), `GraphBuildResult.has_error`, dependency tracking for chain-of-blame (`dep_cells`)
- `uSEQ/src/signal_engine/cold_eval.{h,cpp}` — `EvalResult` (diagnostic array, error kind), `on_cell_changed()` (dependency-triggered recompilation — chain of blame source)
- `uSEQ/src/signal_engine/diagnostics.{h,cpp}` — `Diagnostic` struct (severity, category, span, message, suggestion), `DiagnosticSeverity`, `DiagnosticCategory`
- `wasm/wasm_wrapper.cpp` — `useq_last_diagnostics()`, `useq_active_diagnostics()`, batch-eval isolation in `useq_eval_outputs_time_window_into()`
- `uSEQ/src/firmware/firmware.{h,cpp}` — tick-loop error handling, watchdog recovery
- `test/signal_engine/test_signal_engine_robustness.cpp` — robustness and error-recovery tests

## 1. Error Categories

1.1 ModuLisp distinguishes **compile-time errors** (program never produces a value) from **runtime errors** (program ran but a sample was unhealthy).

1.2 **Compile-time errors** include: parse errors, unresolved symbols (with fuzzy-match suggestions), arity mismatches, side-effect forms inside signal context, recursion in signal context, oversized `for` collections, type errors that the compiler can prove (e.g. arithmetic on a string with no type-promoting operator), unsupported builtins for the current target, and structurally invalid forms.

1.3 Compile-time errors are **structured diagnostics**: they carry severity, category, source span, human-readable message, and a suggestion (often a working example). They surface in the editor as inline annotations and in the firmware as serial-protocol messages. The data shapes live in [diagnostics.md](diagnostics.md).

1.4 **A compile-time error does not stop the music.** The previously active program for that output (if any) keeps running. Other outputs are unaffected.

1.5 **Runtime errors** are: division by zero, out-of-bounds vector access on an unbounded path, integer-modulo by zero, NaN/Inf propagation that survives to the output root, and invalid local-clock deltas in state-bearing contexts.

1.6 `rate-as` rates follow ordinary numeric health rules. A non-finite rate is a runtime error. Zero rate is valid: the local clock stops. Negative rates are valid only for primitives that explicitly document reverse-time state semantics; otherwise they are compile-time errors when provable or runtime errors when only discovered from inputs.

1.7 **Runtime errors are time-phase-dependent.** A signal is a pure function of time and inputs; an expression valid at `beat = 0.3` may produce `NaN` at `beat = 0.95`. Runtime diagnostics describe *when* something went wrong, not just *that* it went wrong. A diagnostic carrying `transient = true` ([diagnostics.md §3.4](diagnostics.md)) signals "this fails on some samples and succeeds on others"; `transient = false` signals "this fails on every sample observed so far". The user should treat transient errors as soft signals (the output is mostly running on LKG but recovers periodically) and persistent errors as hard ones (the output has been on LKG continuously since the failure began).

1.8 **Runtime errors are deduplicated and rate-limited.** A signal sampled hundreds of times per second per output must not produce hundreds of diagnostics. The runtime collapses runtime errors by `(output, category)` and reports at most **one diagnostic per output per frame**. The diagnostic's `last_occurrence` field is updated when the same `(output, category)` recurs without a healthy sample in between. A diagnostic that persists across multiple frames may be annotated with phrasing such as "occurring frequently" — the message text is implementation-defined, the rate-limit is normative.

## 2. Last-Good-Sample Hold

2.1 **Per-sample output hold.** When an active output graph produces a
non-finite root, the runtime substitutes that output's stored last finite
sample for this sample. The active graph is retried on the next sample; a
phase-dependent failure can therefore recover without reassignment. The
runtime does not retain or execute an older compiled program.

2.2 **What is stored.** Each output has one `lkg_value` scalar. A healthy
committed sample replaces it. A substituted sample leaves the same scalar in
place; NaN/Inf is never promoted.

2.3 **State coherence.** A state resource owned by the failing output does not
commit its candidate next value on a fallback sample. It resumes from its
previous finite state when that owner next produces a healthy root. This
prevents oscillators and integrators from advancing inaudibly behind a held
sample. Named/shared state sources have their own writer context and continue
according to their own finite-update rule.

2.4 **Bootstrap.** If no healthy sample has ever been committed, no LKG exists.
The published substitute is still the compiler-domain neutral output, numeric
`0`, but health is `error`, not `fallback`; committing that substitute does
not manufacture an LKG.

2.5 **No fallback chains.** There is exactly one held scalar per output, not a
chain of candidate programs or values. Every runtime sample either publishes
its finite root or reuses that scalar.

2.6 **Compile-time errors do not consume fallback.** A program that fails to
compile is not promoted, demoted, or substituted; the active graph, held
sample, source, dependencies, state ownership, and health are unchanged. The
same publication rule applies to a rejected reactive synth-control candidate:
its prior root and control LKG remain live.

## 3. Numerical Hygiene

3.1 **Numerical errors are not silently zeroed at the output level.** Per-node NaN/Inf clamping (if any engine performs it) is an internal hygiene mechanism; the user-observable contract is "if the output goes unhealthy, you fall back to LKG, and you see a diagnostic." The engine must not silently produce subtly-wrong output instead of declaring failure.

3.2 **Configurable failure mode.** The runtime exposes two non-finite policies as a single engine-global option (`sig::FailureMode`, `uSEQ/src/signal_engine/executor.h`):

| Mode | Behaviour |
|---|---|
| `lkg` (**default**) | §3.1 semantics: values propagate freely through the node graph; a non-finite value reaching an *output root* substitutes that output's LKG value (or the neutral default per §2.4), marks the output as `fallback` (§5), and surfaces a runtime diagnostic (`useq_active_diagnostics()` on WASM). |
| `zero` (legacy) | Pre-v1.2 behaviour: every non-finite node result is clamped to `0.0` at the node level. No fallback, no diagnostic. Retained for compatibility with patches that exploited the squash. |

The mode is set over the serial wire protocol via `set-failure-mode` ([wire-protocol.md §5.18](wire-protocol.md)) and on the WASM runtime via `useq_set_failure_mode(0|1)` / `useq_get_failure_mode()`. It is global, not per-output (a per-output variant was considered and rejected as disproportionate wire/UI complexity). It defaults to `lkg` at boot/init and is not persisted by the engine; the editor re-sends its setting on connect.

3.3 **Fallback tracking is per-pass.** The engine recomputes the per-output
fallback set (`NodePool::runtime_fallback_mask`) on every live execution pass:
a sample whose root is finite clears that output's fallback state. Read-only
sampling and projection restore this diagnostic field with the rest of the
runtime snapshot and cannot create or clear live health. State commits follow
§2.3 and never accept non-finite update roots. Each rejected state update sets
its slot in `state_update_failure_mask`; a later finite candidate commits and
clears that same bit. Projection snapshots preserve both masks.

> **Status note.** Prior to v1.2.0 the implementation only performed the `zero` squash (spec drift flagged by two independent audits). The `lkg` path above is now implemented and is the default; the squash survives solely as the opt-in legacy mode.

## 4. Diagnostic Survival

4.1 **Diagnostics survive across evals.** Per-output health is queryable by the editor and shown to the user. A successful eval clears prior diagnostics for *that output* — not for the whole document. The clearing policy is detailed in [diagnostics.md §4.4](diagnostics.md).

## 5. Per-Output Health States

5.1 Every output is in exactly one of four states at any time. (See
`uSEQ/src/signal_engine/node_pool.h` — `valid`/`root_node` identify an active
assignment while `has_lkg` independently identifies a committed finite root;
`uSEQ/src/signal_engine/executor.cpp` — `output_health()` and
`commit_outputs()`.)

| State | Meaning |
|---|---|
| `idle` | No program assigned. Output emits the neutral default (`0`). |
| `running` | Active program is healthy and producing samples. |
| `fallback` | The latest live sample was unhealthy; output held its last finite sample. |
| `error` | Latest live sample was unhealthy and no LKG has ever existed; output holds neutral zero. |

5.2 Transitions:

```
idle ── (assign) ─────────► running
running ── (compile fail on new assignment) ─► running   (active unchanged)
running ── (runtime error) ──────────────────► fallback
running-with-no-LKG ── (first runtime error) ─► error
fallback ── (next healthy sample or assignment) ─► running
error ── (next healthy committed sample) ────► running
* ── (clear) ────────────────────────────────► idle
```

5.3 The state is queryable by the editor (typically once per animation frame).
It drives output-pane indicators and a "holding last good sample — view
error" badge on `fallback`.

## 6. Success Feedback

6.1 **Silence on success is also a bug.** A user typing `(a1 (sin beat))` needs to know it *worked*. If nothing visibly changes — no echo, no indicator, no waveform redraw — they cannot tell whether the code was received, compiled, or is running. The system MUST close the loop.

6.2 Success feedback travels through the same channels as error feedback but is more subdued:

- A brief confirmation that fades after roughly one second ("a1 updated").
- An output-state transition (idle/error/fallback → running), visible on the indicator.
- A waveform redraw if the output is being visualised.

6.3 Success feedback must not be noisy. It should be visible enough for a beginner to notice, quiet enough that an expert performing on stage never thinks about it.

## 7. REPL Errors vs Output Errors

7.1 The user types in two distinct contexts. **Output assignments** (`(a1 ...)`, `(d3 ...)`, etc.) install a persistent signal expression; **REPL evals** (e.g. `(+ 1 2)`, `(define foo 42)`, exploratory `(sin 0.5)`) run once and return.

7.2 The two contexts have different failure semantics:

| | Output assignment | REPL eval |
|---|---|---|
| Persistent program? | Yes | No |
| LKG fallback applies? | Yes | No — the expression either works or doesn't |
| Failure surface | Editor inline annotation; fallback indicator on the output | Inline in the console output stream |
| Cleared by | Successful reassignment of the same output | The next REPL line |

7.3 Both contexts use the same `Diagnostic` data model. Only the delivery channel differs: output errors are read from `useq_active_diagnostics()` and `useq_output_diagnostics()`; REPL errors are read from `useq_last_diagnostics()` immediately after the eval call.

## 8. Cascade Noise and Display Cap

8.1 **Candidate-local report-and-continue.** Within one candidate graph the
compiler may collect multiple independent diagnostics using typed
placeholders. The candidate remains rejected and publishes nothing. At the
top-level submission boundary, evaluation stops at the first rejected form;
later forms are not executed.

8.2 **Typed placeholders.** When a non-fatal error is reported in a numeric context, the compiler substitutes `0.0`, not a sentinel `nil`. This prevents a single error from triggering a cascade of spurious type errors in downstream arithmetic.

8.3 **Placeholder-register suppression.** The compiler tracks which registers hold placeholder values. A diagnostic whose *only* failing input is a placeholder register is suppressed — it is a consequence of the primary error, not an independent problem.

8.4 **Speculative compilation discards diagnostics on rollback.** Where the compiler does speculative compilation (e.g. trying to specialise a callable, attempting numeric while-loop lowering), checkpoint state must include the diagnostic-vector size and rollback must truncate any speculative diagnostics. The user must not see error messages about bytecode that was discarded.

8.5 **Frontend display cap.** Even when the compiler produces many diagnostics, the editor shows at most **5 errors per eval** by default; additional diagnostics are reachable via "show all". Warnings render separately and do not count against this cap.

## 9. Chain of Blame

9.1 When a cell mutation triggers recompilation of a dependent output, named
state, or synth control and that recompilation fails, the error is *caused by*
the cell change but *manifests in* the persistent consumer expression. The user
needs to see both halves to know what to fix.

9.2 The diagnostic carries a `triggered_by` field ([diagnostics.md §2](diagnostics.md)) holding the symbol name of the mutated cell that triggered the recompile. The frontend renders it as context — *"this broke because `x` changed"* — alongside the primary message.

9.3 **Span attribution.** The diagnostic's source span points at the *reference
site* where the mutated symbol is used inside the consumer expression, not at
the redefinition site. The user needs to see which part of the persistent
program depends on the symbol whose meaning changed; the redefinition is in
another pane and is by definition the recent action.

9.4 A rejected background output, named-state, or synth-control recompile
publishes one active compile diagnostic indexed by the consumer, including
`triggered_by`. The old root, dependencies, state and resources remain live. A
subsequent successful recompile of that consumer clears its diagnostic;
unrelated evals do not. A later rejection replaces the consumer's complete
record rather than accumulating multiple causes.

9.5 Active diagnostics serialize in stable ownership order: output index,
dense named-state slot, then synth artifact control order. Direct replacement,
parameter removal, and full clear remove the corresponding synth-control slots
atomically with the public artifact.

## 10. Batch-Eval Isolation

10.1 When the runtime evaluates multiple outputs in a single batch (`useq_eval_outputs_time_window()` and equivalents), a runtime error on one output **must not** abort the others. Each output is independent: errors are recorded per-output, healthy outputs continue producing samples to the end of the batch. This is the per-output expression of the language-wide "never stop the music" guarantee. (See `wasm/wasm_wrapper.cpp` — useq_eval_outputs_time_window_into, per-output loop with errors isolated; `uSEQ/src/signal_engine/executor.cpp` — execute_all_outputs iterates outputs independently.)

10.2 When an output errors mid-batch the runtime:

1. Records the runtime diagnostic against that output.
2. Substitutes its held sample (or neutral default per §2.4) for each failing
   sample; later samples are still evaluated and may recover.
3. Continues evaluating the next output.

10.3 The batch return value indicates overall success only as a coarse summary. Individual output errors are retrieved via `useq_active_diagnostics()` / `useq_output_diagnostics()`.

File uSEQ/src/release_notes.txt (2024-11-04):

1.1.0

Features:
Ratio sequencing: rpulse, rstep, ridx, rwarp
Added 'shift' function (#75)

Bug fixes:
Fixed println
(schedule) should search and replace existing items in list #49 
random function has gone missing #107 
s7 and s8 not defined #118
scale is casting to int #109
usine phasor argument #110
len function is broken #116 

1.0.2
Variable duty triangle oscillator ('tri')

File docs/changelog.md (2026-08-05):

# Changelog

## Unreleased

- Fixed browser-local evaluation on Chromium releases that expose
  `WebAssembly.Memory.toResizableBuffer()`. The WASM build now keeps classic
  fixed-length heap views across memory growth, and artifact verification
  rejects generated glue that re-enables growable ArrayBuffer views.

## 1.2.0-beta.1

- Firmware identity now uses canonical SemVer prereleases and one build-info
  source rather than hard-coded protocol strings.
- `hello` and `ready` advertise independent protocol version, exact hardware
  target, and additive capability names so an editor can select safe behavior
  and the correct UF2 without inferring from firmware semver.
- I2C output expanders advertise a CRC-protected factory identity, exact
  firmware target/version, hardware revision, batch, and serial to the main
  module. `hello.modules` exposes startup discovery and `rescan-modules`
  repeats it explicitly without inventing an I2C firmware-relay path.

## 1.2.0 (Protocol Enhancements)

### Additions
- JSON protocol handlers: `hello` (negotiation with ioConfig), `ping` (heartbeat), `stream-config` (channel configuration)
- `useq-get-transport-state` builtin — returns `"playing"`, `"paused"`, or `"stopped"`
- Transport state push via `meta` field in JSON eval responses
- `console` field in JSON responses (editor prefers this over `text`)
- `JsonBuilder` utility class (`utils/json_builder.h`) for structured JSON construction
- `Protocol::send_raw_json()` for sending pre-built JSON payloads

### Changes
- `handle_json_serial_request` now dispatches on request type instead of rejecting non-eval requests
- Transport builtins (`useq-play`, `useq-pause`, `useq-stop`, `useq-rewind`) set `m_pending_transport_meta` for automatic state reporting

---

## 1.0 -> 1.0.1
bb280b0..cc04555

# Fixes
- Fixed `pulse`'s width parameter being inverted.
- Fixed `pow` so that base is on the right
- Fixed `scale` to work with floats and take either 3 or 5 args
- added `lerp`
- added `random`
- added vector call syntax

- added `toggle_select` (?)

- fix `dm` args error checking
- fix `gatesw`, phasor on the right
- fix (re-introduce) `trigs`

- change IO analogWriteFreq from 80000 to 100000

- change `euclid`, remove some args and phasor on the right
- add `eu` TODO
- remove `looph`

- `len` now works with sequentials (currently, that means List & Vector) and not just with Lists.

# Additions
# Removals
# Changes
- Changed println to accept any object, not just strings

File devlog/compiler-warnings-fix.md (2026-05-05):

# Compiler Warnings System Refactoring

## Issue Identified

The codebase had a critical maintainability issue: **excessive use of blanket warning suppression via `#pragma GCC diagnostic` directives** across 8+ core files. This created several problems:

1. **Hidden bugs**: Blanket suppression hides potential bugs, type safety issues, and code quality problems
2. **Build system contradiction**: meson.build enables strict warnings but files immediately disable them
3. **Lost compiler feedback**: Developers lose crucial information about potential issues
4. **Maintenance burden**: Code can't be gradually improved without compiler guidance
5. **Technical debt accumulation**: Problems compound invisibly

### Files Affected
- `uSEQ/src/uSEQ.h` - Main hardware interface (blanket suppression)
- `uSEQ/src/modulisp/lisp/interpreter.cpp` - Core interpreter (blanket suppression)
- `uSEQ/src/modulisp/lisp/value.cpp` - Value system (blanket suppression)
- `uSEQ/src/modulisp/modulisp_api.cpp` - API layer (blanket suppression)
- `uSEQ/src/modulisp/lisp/generated_builtins.cpp` - Generated code (appropriate)
- Multiple utility files with format-specific suppressions

## Solution Implemented

### 1. Centralized Compiler Configuration

Created `/uSEQ/src/utils/compiler_config.h` with:

- **Targeted warning suppressions** instead of blanket disable-all
- **Clear documentation** about when and why to use each macro
- **Consistent approach** across the codebase
- **Platform-specific handling** for Arduino vs desktop builds

### Macros Provided:

- `USEQ_SUPPRESS_WARNINGS_PUSH/POP` - For generated code only
- `USEQ_SUPPRESS_FORMAT_WARNINGS_PUSH/POP` - For sprintf/format functions  
- `USEQ_SUPPRESS_EXTERNAL_WARNINGS_PUSH/POP` - For third-party library interfaces
- `USEQ_FAST_MEM` / `USEQ_FAST_FUNC` - Memory attribute management

### 2. Build System Cleanup

Fixed contradictory warning flags in `meson.build`:
- **Removed**: Contradictory `-Wconversion` + `-Wno-conversion` pair
- **Clarified**: Comments explaining why each flag is enabled/disabled
- **Rationalized**: Warning selection for embedded development context

### 3. File-by-File Migration

**Core interpreter files**: Removed blanket suppression, warnings now enabled
- `/modulisp/lisp/interpreter.cpp` - Core interpreter logic
- Warnings will now surface for maintenance and improvement

**Generated code**: Appropriate targeted suppression
- `/modulisp/lisp/generated_builtins.cpp` - Uses new macro system
- Only suppresses warnings for machine-generated code

**Hardware interface**: Platform-specific handling
- `/uSEQ.h` - Only suppresses external library warnings on Arduino
- Enables warnings for uSEQ-authored code

**Format functions**: Targeted suppression
- `/utils/dtostrf.h` - Uses format-specific macro
- Only suppresses format-related warnings where unavoidable

## Benefits Achieved

### Immediate Improvements

1. **Compiler feedback restored** - Warnings now visible in core code
2. **Build consistency** - meson.build flags now have clear purpose  
3. **Maintainability** - Contributors get compiler guidance
4. **Documentation** - Clear guidelines for warning management

### Long-term Impact

1. **Code quality improvement** - Warnings help catch issues early
2. **Refactoring safety** - Compiler feedback during modifications
3. **Technical debt visibility** - Problems no longer hidden
4. **Contributor experience** - Clear guidance on warning management

## Migration Guidelines

### For New Code
- **DO NOT** use blanket warning suppression
- **DO** fix warnings instead of suppressing them
- **USE** specific macros from `compiler_config.h` only when necessary
- **DOCUMENT** why any suppression is needed

### For Existing Code
- **PRIORITIZE** fixing warnings over suppressing them  
- **USE** `compiler_config.h` macros instead of raw pragmas
- **JUSTIFY** any remaining suppressions with comments
- **MIGRATE** incrementally as code is touched

### When Suppression Is Appropriate

1. **Generated code** that cannot be modified
2. **Third-party library interfaces** with unfixable warnings  
3. **Legacy format functions** with inherent string formatting issues
4. **Platform compatibility** where warnings differ between targets

## Testing Verification

- ✅ All existing tests pass
- ✅ Build system works for both desktop and Arduino targets
- ✅ No build errors introduced
- ✅ Warning configuration is consistent

## Next Steps

1. **Gradual improvement**: Fix warnings as they surface in development
2. **Code review process**: Require justification for any new warning suppressions
3. **Continuous monitoring**: Track warning trends over time
4. **Documentation maintenance**: Keep `compiler_config.h` guidelines current

This refactoring establishes a foundation for sustainable code quality improvement while maintaining the dual-build system requirements of the uSEQ project.

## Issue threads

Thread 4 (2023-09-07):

chaining modules thru serial connections

chriskiefer, 2023-09-07:

chriskiefer, 2024-03-18:
try i2c on 1.0b hardware

chriskiefer, 2024-03-19:
test working, small edit needed on 1.0b hardware, fixed in 1.0c

Closed 2024-03-19.

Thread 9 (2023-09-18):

editor:  outerbrackets error if unbalanced right bracket

chriskiefer, 2023-09-18:

Closed 2023-09-28.

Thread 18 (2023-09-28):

general: More descriptive error messages

monkey-w1n5t0n, 2023-09-28:

monkey-w1n5t0n, 2024-05-30:
Happy with the current state of error messages, so closing this for now.

Closed 2024-05-30.

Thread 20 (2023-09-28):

dev: Build on Linux

monkey-w1n5t0n, 2023-09-28:
The entire module (minus the Arduino-specific bits) should be buildable, testable, and most importantly debug-able on x64 (mostly Linux for now).

Some progress has been made on the [separate-interpreter branch](https://github.com/lnfiniteMonkeys/uSEQ/tree/separate-interpreter).

Tasklist:
TBD

chriskiefer, 2023-10-13:
fixed with the virtual interface

Closed 2023-10-13.

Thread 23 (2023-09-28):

error in a[x] mappings

chriskiefer, 2023-09-28:

chriskiefer, 2023-09-28:
a3 sets a1 and a3

chriskiefer, 2023-09-28:
the signals outputs are actually fine, but when you set a3 PWM (19) it also sets A1 LED (3) because they're on the same PWM slice.  The solution is to make PIO state machines to run either LEDS or PWM signal outputs.

Compile the asm from https://wokwi.com/tools/pioasm, use code from CK's clockdiv module

Closed 2023-09-29.

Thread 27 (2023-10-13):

interpreter: not receiving result of @immediate commands

chriskiefer, 2023-10-13:
println missing

Closed 2023-10-13.

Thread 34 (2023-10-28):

useqedit serial - glitch on raspberry pi when refreshing screen

chriskiefer, 2023-10-28:
need to collect serial in a separate thread?  then have two FIFO queues for text and serial streams

Closed 2024-04-26.

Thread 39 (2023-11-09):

Move arduino sketch into new subfolder

chriskiefer, 2023-11-09:
So arduino IDE doesn't pick up other code

Closed 2023-11-15.

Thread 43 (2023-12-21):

issue with unevalled arguments

chriskiefer, 2023-12-21:
(defun offs (ph offset) (% (+ ph offset) 1.0))
(print (offs bar 0.25))

last statement crashes the module

chriskiefer, 2024-05-16:
(defun step (ph x) (floor (* ph x)))

(step (+ bar 0) 2)

causes error

list isn't getting eval'd

rcv:(product) All arguments should evaluate to a number, b
main.mjs:38 rcv:ut argument #1 is a list instead:
(+ bar 0)
\nERROR: (ard_floor) Argument #1 evaluates to an error:
(* ph x)\n==> <error type>

Closed 2024-05-28.

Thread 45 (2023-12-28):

add diode to protect gate inputs

chriskiefer, 2023-12-28:
https://northcoastsynthesis.com/news/design-mistakes-in-synth-schematics/

Closed 2024-01-26.

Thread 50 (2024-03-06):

Persist state to flash memory

chriskiefer, 2024-03-06:
3 functions

**(save)**

Saves the LISP environment in human readable format to flash memory

**(restore)**

Automatically called on startup

**(save-usb)**

Send state down the wire for saving in another place

Notes: philhower EPROM only reserves 4kb, can we expand this?

Expts:
1. save and restore string to eprom
2. save env to string
3. restore env from string
4. Add above functions
5. Expand storage

monkey-w1n5t0n, 2024-03-06:
> Saves the LISP environment in human readable format to flash memory

Human-readable can mean a couple of different things here:
1) The raw (user-provided) code that created the environment in the first place and can fully recreate it:
```lisp
(def a 1)
(def b (+ a 2))
```
Pros:
- looks exactly like what the user saved (and can also maintain comments, which may be very important to the user)
- code can be stored entirely in the module and sent to any number of editors to instantly reflect what's going on
- is immediately hackable upon boot
- _may_ be more space-efficient (TBD via testing)

Cons:
- Requires cache management (i.e. keeping track of the latest block of code that was used to define a symbol)
- Requires parsing and interpreting the code into a full Environment object (which will slow down boot, but only needs to happen once per restoration)

2) The raw serialisation of the environment (which is a map of symbols->values), formatted in e.g. JSON:
```
{
  "a": 1,
  "b": 3
}
```
Pros:
- Is easier to code (there's already an `Environment::toString()` method, just needs to be made to recurse through parent/child envs)

Cons:
- Only stores pairs of symbol->value, which doesn't retain the relationships between variables that were known at definition time. In the above example, the information that "b" is meant to be `a + 2` is lost.
- It's lossy, i.e. doesn't maintain original code (including formatting, comments, etc)
- Needs an additional de-serialiser method (as opposed to just passing the saved code string to `eval`)

> Notes: philhower EPROM only reserves 4kb, can we expand this?

This is being determined [here](https://github.com/earlephilhower/arduino-pico/blob/ea8874037c3027385d64fbdb89842291e9e34c61/libraries/EEPROM/src/EEPROM.cpp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) in the arduino-pico library, with a simple clamp of the requested size to [0,4096]. At first glance it seems that we can just remove this clamp and then request as much as we want, but need to make sure that the rest of the library doesn't assume that the size will never be over 4k.

Closed 2024-08-28.

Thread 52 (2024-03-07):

Sample player

chriskiefer, 2024-03-07:
Assuming samples are in flash ROM, they can be streamed:

https://github.com/raspberrypi/pico-examples/blob/master/flash/xip_stream/flash_xip_stream.c#L45-L48

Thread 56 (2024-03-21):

extra testing on gate clock external sync

chriskiefer, 2024-03-21:
use kuramoto style phase correction?

chriskiefer, 2024-06-03:
notes:  redone tracking to use gpio interrupt for better accuracy.  Now it does bpm sync but not phase sync.

Suggestion

timesig = x beats per bar
every x clocks on the input,
time to next bar = projected next bar time - current transport time
time to next bar < half a bar, go backwards else go forwards
nudge transport time towards bar boundary

chriskiefer, 2024-06-03:
api functions
(set-clock-internal)
(set-clock-external [1 or 2])

chriskiefer, 2024-06-03:
also try above but from reset signal (test this from another useq)

Closed 2024-06-04.

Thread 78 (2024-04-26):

Speed up firmware with __not_in_flash_func

chriskiefer, 2024-04-26:
void __not_in_flash_func(dosomething)(void) {
}

q: does this pull in functions called from the parent function?

monkey-w1n5t0n, 2024-05-08:
> q: does this pull in functions called from the parent function?

According to [this](https://github.com/raspberrypi/pico-sdk/issues/410#issuecomment-841300503) comment, it doesn't seem that the compiler automatically propagates that to other functions being called.

monkey-w1n5t0n, 2024-05-31:
Attempted on eval, apply, and update_signals but doesn't seem to make much of a difference. Tabling for now.

Closed 2024-05-31.

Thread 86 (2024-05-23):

decide on error bubbling

chriskiefer, 2024-05-23:
just show first error message

monkey-w1n5t0n, 2024-05-30:
Yes I agree, otherwise it can get too messy and the additional errors don't really add any useful context.

In cases where the error is not obvious however (e.g. it's hidden deep down in a hierarchy of variables/functions and is only triggered under specific conditions), this may make it a bit harder for users to debug.

I think that, ideally, when an error occurs we want the following to happen:
1. Print an error message that mentions the name of the function in which the first error occurred, giving useful information that clearly contrasts what was expected and what was received, perhaps even with some suggestions on how to fix it.
2. uSEQ should be able to tell the editor where in the source code that happened, so that we can e.g. highlight the error.
3. If the error happened within the context of an output expr (e.g. when updating a1), then there should also be an additional message informing the user that a1 has been cleared due to the error, because otherwise it will be cleared silently and there may be some confusion about what happened and why.
4. Optionally, the user might want to ask for a stack trace, but we shouldn't show one unless it's requested.

Number 1 is more-or-less in place, number 2 and 4 are perhaps beyond the scope of 1.0, and number 3 should be realistically hackable - I'll look into it.

Closed 2024-06-24.

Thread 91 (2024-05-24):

issue in useq_fast

chriskiefer, 2024-05-24:
(a1 (fast (+ 1 (ain1)) bar))

gives very jittery output

Closed 2024-06-04.

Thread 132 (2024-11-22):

[editor] orphaned bracket after deletion to left

chriskiefer, 2024-11-22:
```
blah blah blah [cursor here]()
```

press delete (not backspace)

=>
```
blah blah blah )
```

also same issue in reverse

which messes up all the editing

*delete doesn't respect param balancing*

Closed 2025-03-10.

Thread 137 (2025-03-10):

Compile all ARM code directly, through Meson, without Arduino IDE

monkey-w1n5t0n, 2025-03-10:
Reasons:

1. Provides much more flexibility in terms of structuring the codebase and include paths.
2. Control over which compiler & version of C++ we're using (we're sticking with `gcc` for the forceable future anyway, but we want to use some C++20 features).
3. Integrates with the rest of the building and testing workflows.

Might still have to install the Arduino IDE and the libraries just as an easy way to get access to the tooling and precompiled arduino-pico core.

Some progress has been made here:
https://github.com/Emute-Lab-Instruments/arduino-pico-meson

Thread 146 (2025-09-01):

MTM Hardware: CV and Pulse Outputs are inverted

TomWhitwell, 2025-09-01:
```
(a1 (slow 2 beat))
```
Produces a downward ramp on A1 - from high voltage to low voltage. I would expect an upward ramp

```
(d1 (from-list [1 0 0 0 ] bar))
```
D1 is briefly low, mostly high, I'd expect it to be briefly high, mostly low

TomWhitwell, 2025-09-09:
Fixed in useq_mtm_ws_2mb-code_14mb-fs.uf2

Closed 2025-09-09.

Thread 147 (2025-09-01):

MTM Hardware: Knob inputs noisy and interactive

TomWhitwell, 2025-09-01:
```
(a1 (knob))
```
If you map A1 to an oscillator, the output is very noisy
-  Switch Z and Knob Y influence the output

```
(a1 (knobx))
```
- In this case Knob Y strongly influences the output, as does Switch Z

```
(a1 (knoby))
```
- In this case the main knob and the switch influence the output

Maybe the mux is not being called correctly, or the Normalisation probe (GPIO4) is interfering?

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

[Computer module Documentation](https://docs.google.com/document/d/1NsRewxAu9X8dQMUTdN0eeJeRCr0HmU0pUjpKB4gM-xo/edit?usp=sharing)

(a1 output is also inverted #146 )

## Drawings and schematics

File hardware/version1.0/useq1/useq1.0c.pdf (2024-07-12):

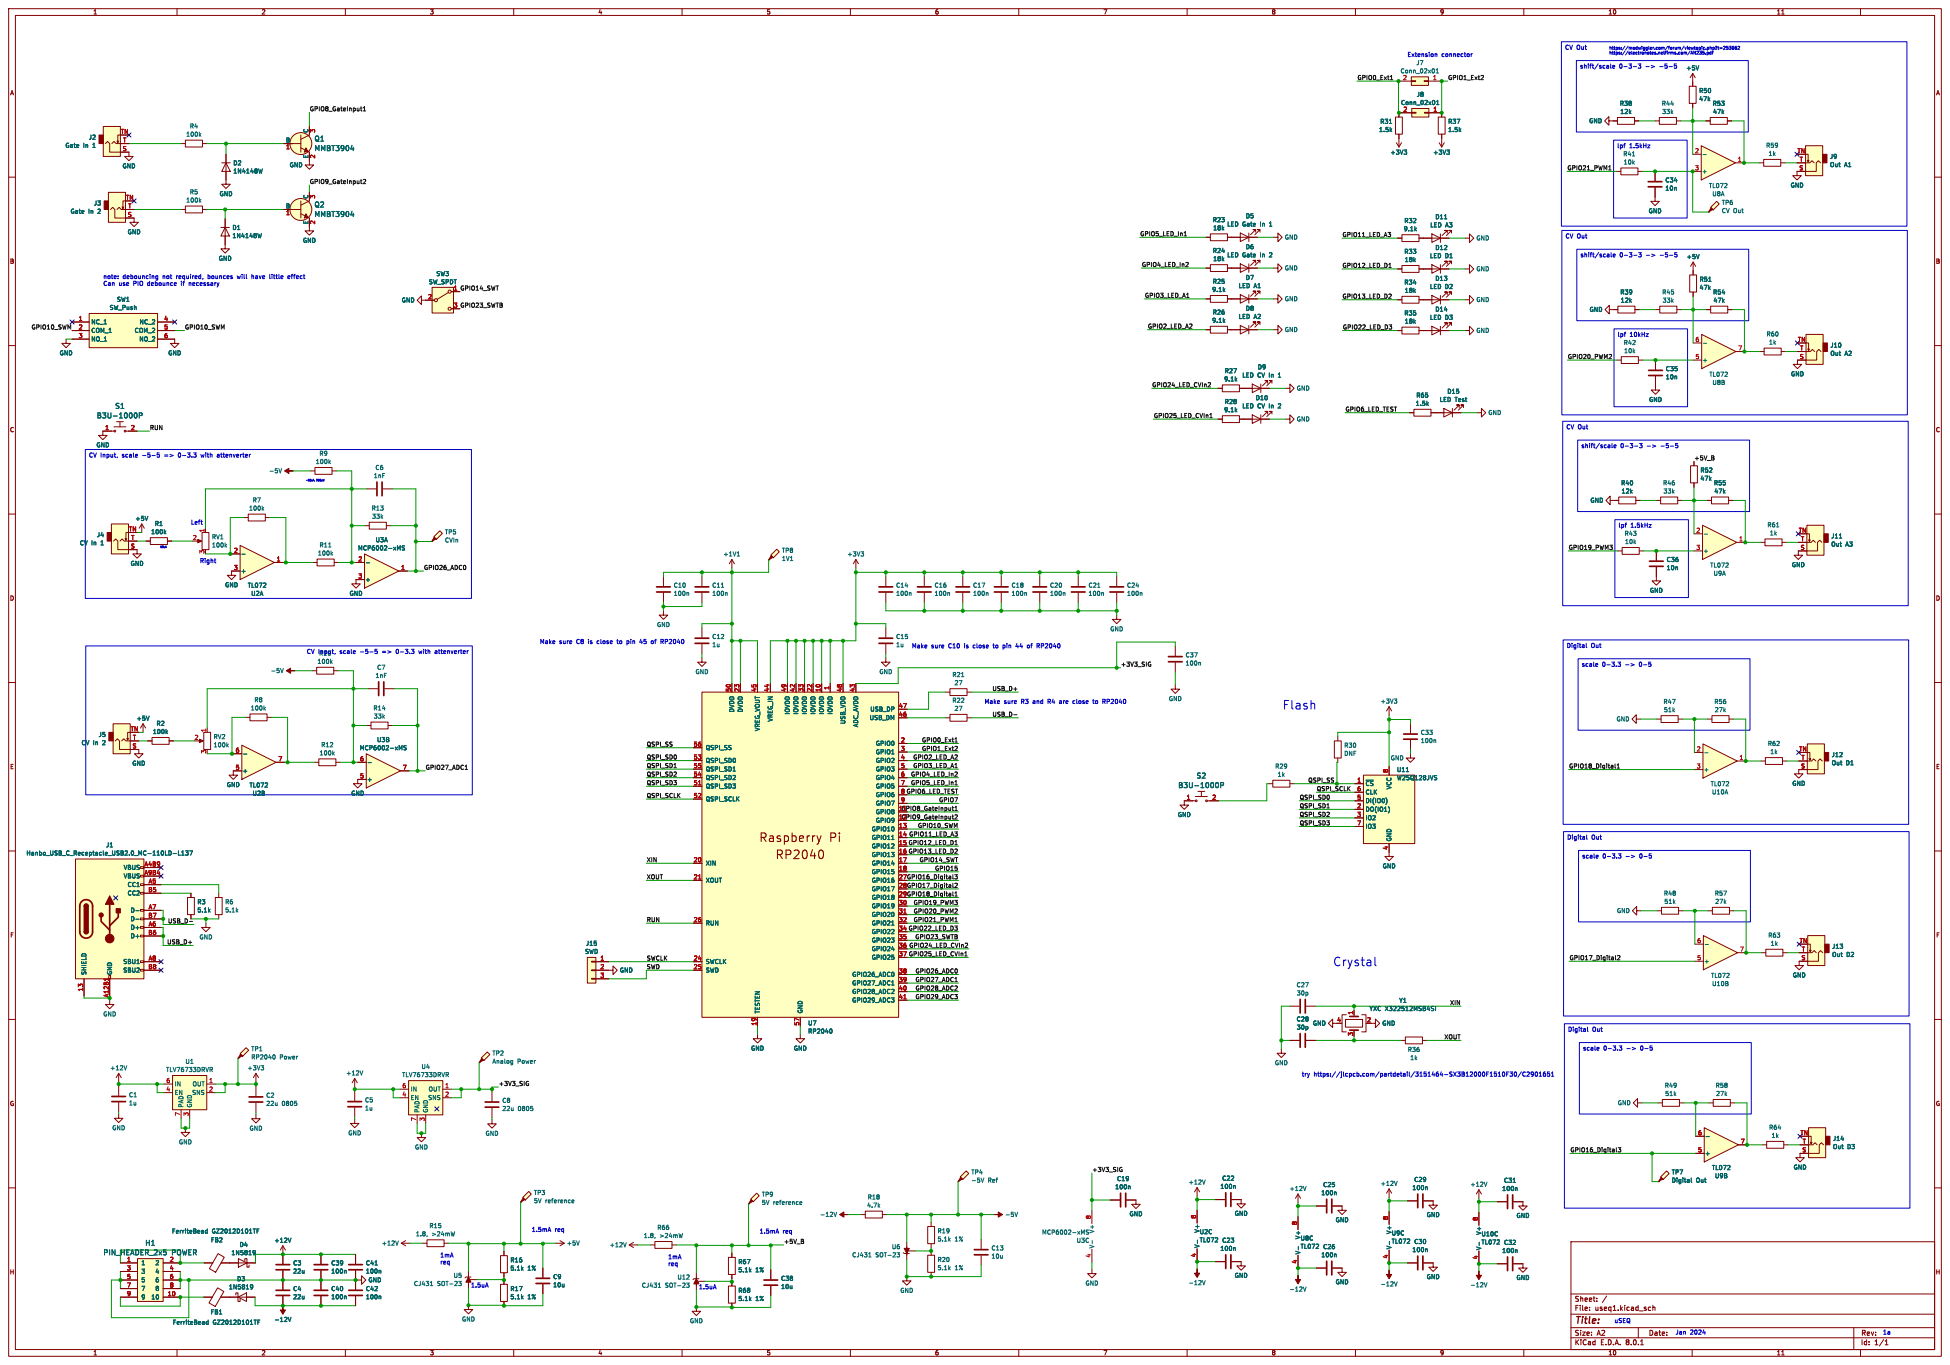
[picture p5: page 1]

https://modwiggler.com/forum/viewtopic.php?t=253062
https://electronotes.netfirms.com/AN235.pdf

LED Gate In 1 GND

LED CV In 2 GND

Make sure C10 is close to pin 44 of RP2040 Make sure R3 and R4 are close to RP2040

1 IOVDD 10 GPIO8 11 GPIO9 12 GPIO10 13 GPIO11 14 GPIO12 15 GPIO13 16 GPIO14 17 GPIO15 18 TESTEN 19 GPIO0 2 XIN 20 XOUT 21 IOVDD 22 DVDD 23 SWCLK 24 SWD 25 RUN 26 GPIO16 27 GPIO17 28 GPIO18 29 GPIO1 3 GPIO19 30 GPIO20 31 GPIO21 32 IOVDD 33 GPIO22 34 GPIO23 35 GPIO24 36 GPIO25 37 GPIO26_ADC0 38 GPIO27_ADC1 39 GPIO2 4 GPIO28_ADC2 40 GPIO29_ADC3 41 IOVDD 42 ADC_AVDD 43 VREG_IN 44 VREG_VOUT 45 USB_DM 46 USB_DP 47 USB_VDD 48 IOVDD 49 GPIO3 5 DVDD 50 QSPI_SD3 51 QSPI_SCLK 52 QSPI_SD0 53 QSPI_SD2 54 QSPI_SD1 55 QSPI_SS 56 GND 57 GPIO4 6 GPIO5 7 GPIO6 8 GPIO7 9 U7 RP2040

1 IOVDD 10 GPIO8 11 GPIO9 12 GPIO10 13 GPIO11 14 GPIO12 15 GPIO13 16 GPIO14 17 GPIO15 18 TESTEN 19 GPIO0 2 XIN 20 XOUT 21 IOVDD 22 DVDD 23 SWCLK 24 SWD 25 RUN 26 GPIO16 27 GPIO17 28 GPIO18 29 GPIO1 3 GPIO19 30 GPIO20 31 GPIO21 32 IOVDD 33 GPIO22 34 GPIO23 35 GPIO24 36 GPIO25 37 GPIO26_ADC0 38 GPIO27_ADC1 39 GPIO2 4 GPIO28_ADC2 40 GPIO29_ADC3 41 IOVDD 42 ADC_AVDD 43 VREG_IN 44 VREG_VOUT 45 USB_DM 46 USB_DP 47 USB_VDD 48 IOVDD 49 GPIO3 5 DVDD 50 QSPI_SD3 51 QSPI_SCLK 52 QSPI_SD0 53 QSPI_SD2 54 QSPI_SD1 55 QSPI_SS 56 GND 57 GPIO4 6 GPIO5 7 GPIO6 8 GPIO7 9 S2 B3U-1000P

try https://jlcpcb.com/partdetail/3151464-SX3B12000F1510F30/C2901651

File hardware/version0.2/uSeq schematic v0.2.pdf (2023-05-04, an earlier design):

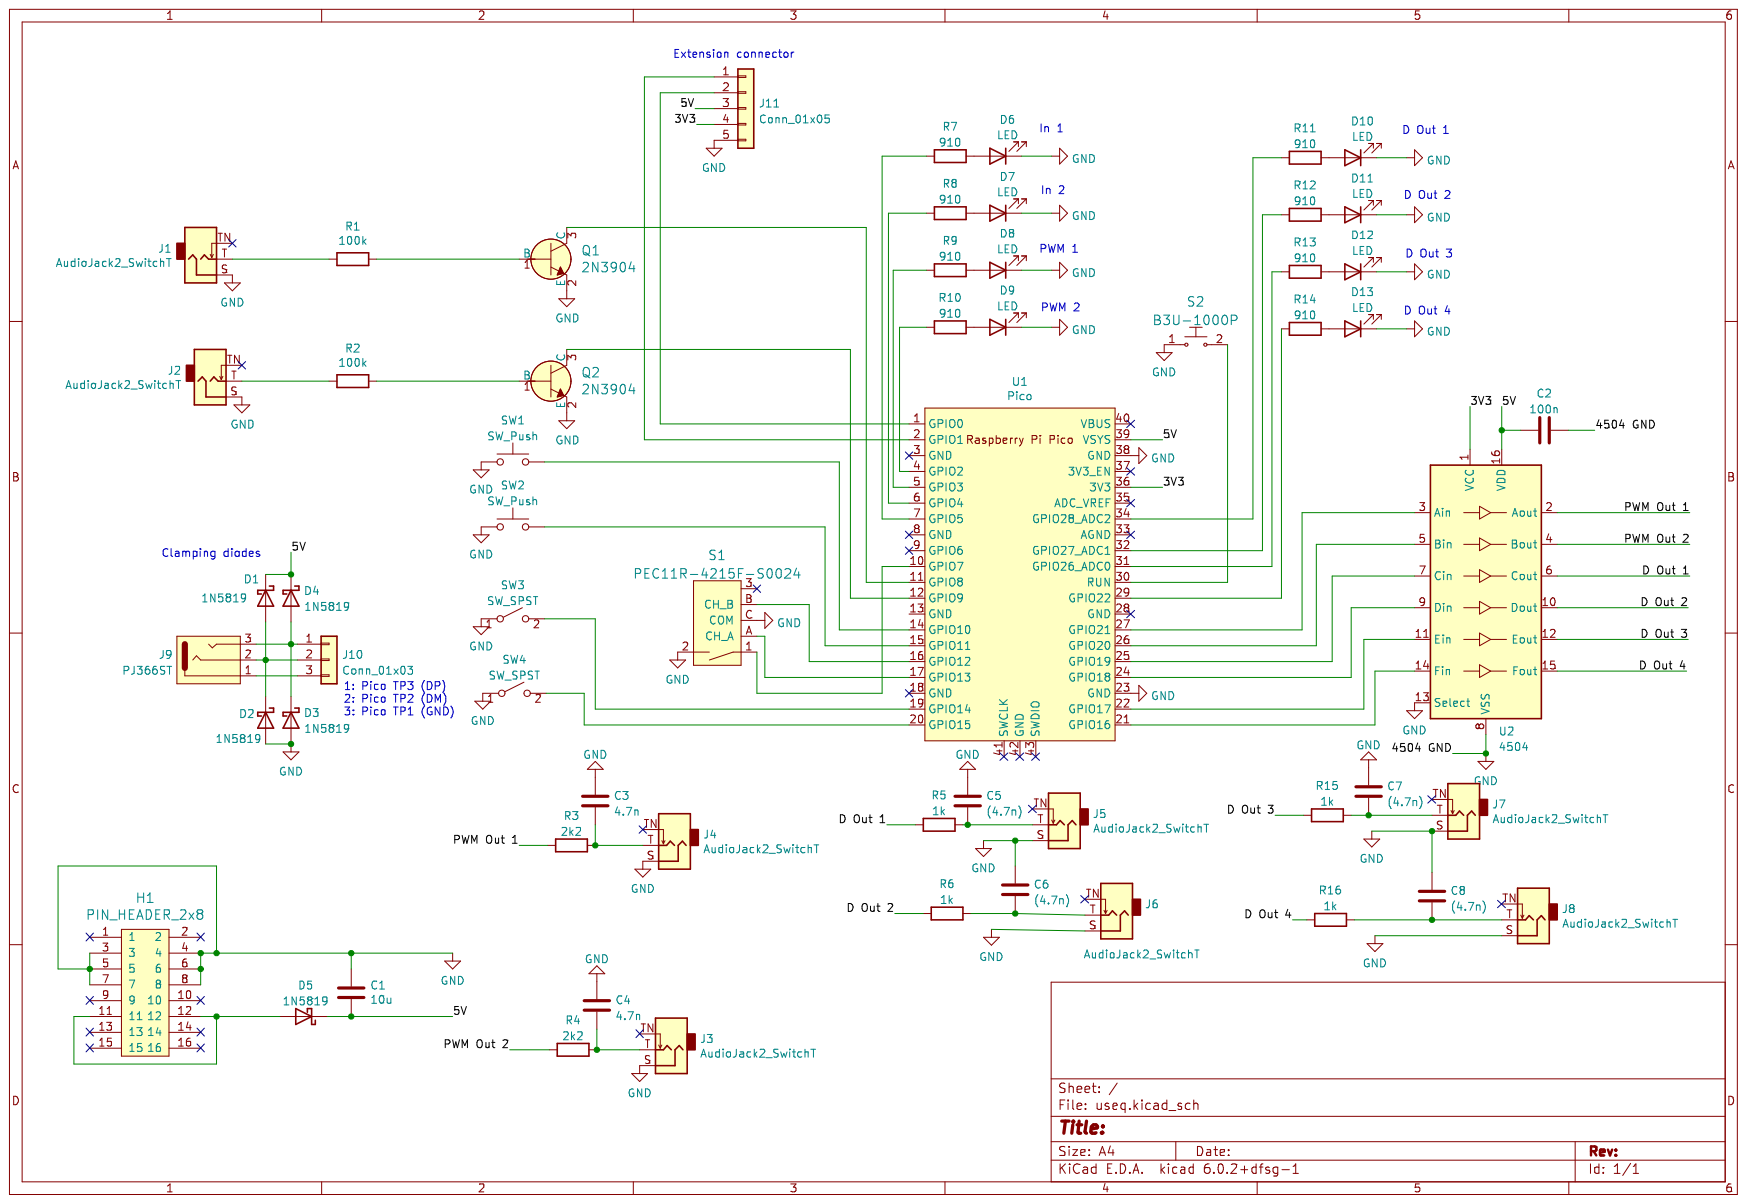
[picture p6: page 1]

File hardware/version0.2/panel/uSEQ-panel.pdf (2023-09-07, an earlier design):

# uSEQ

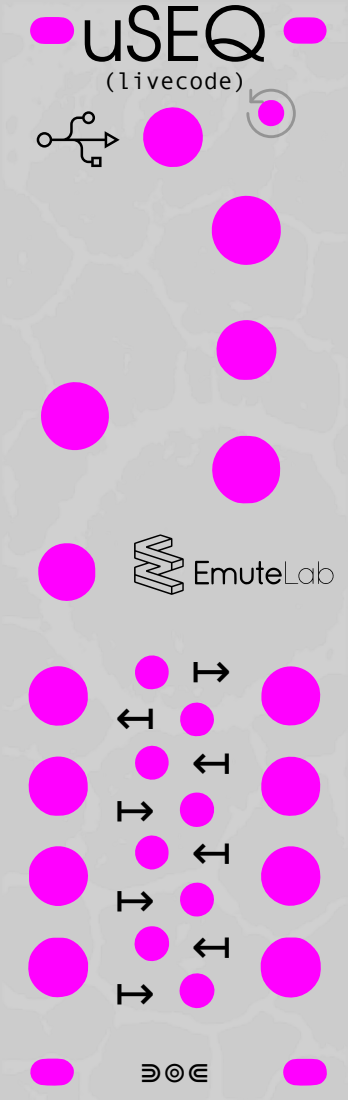
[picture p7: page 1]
(livecode)

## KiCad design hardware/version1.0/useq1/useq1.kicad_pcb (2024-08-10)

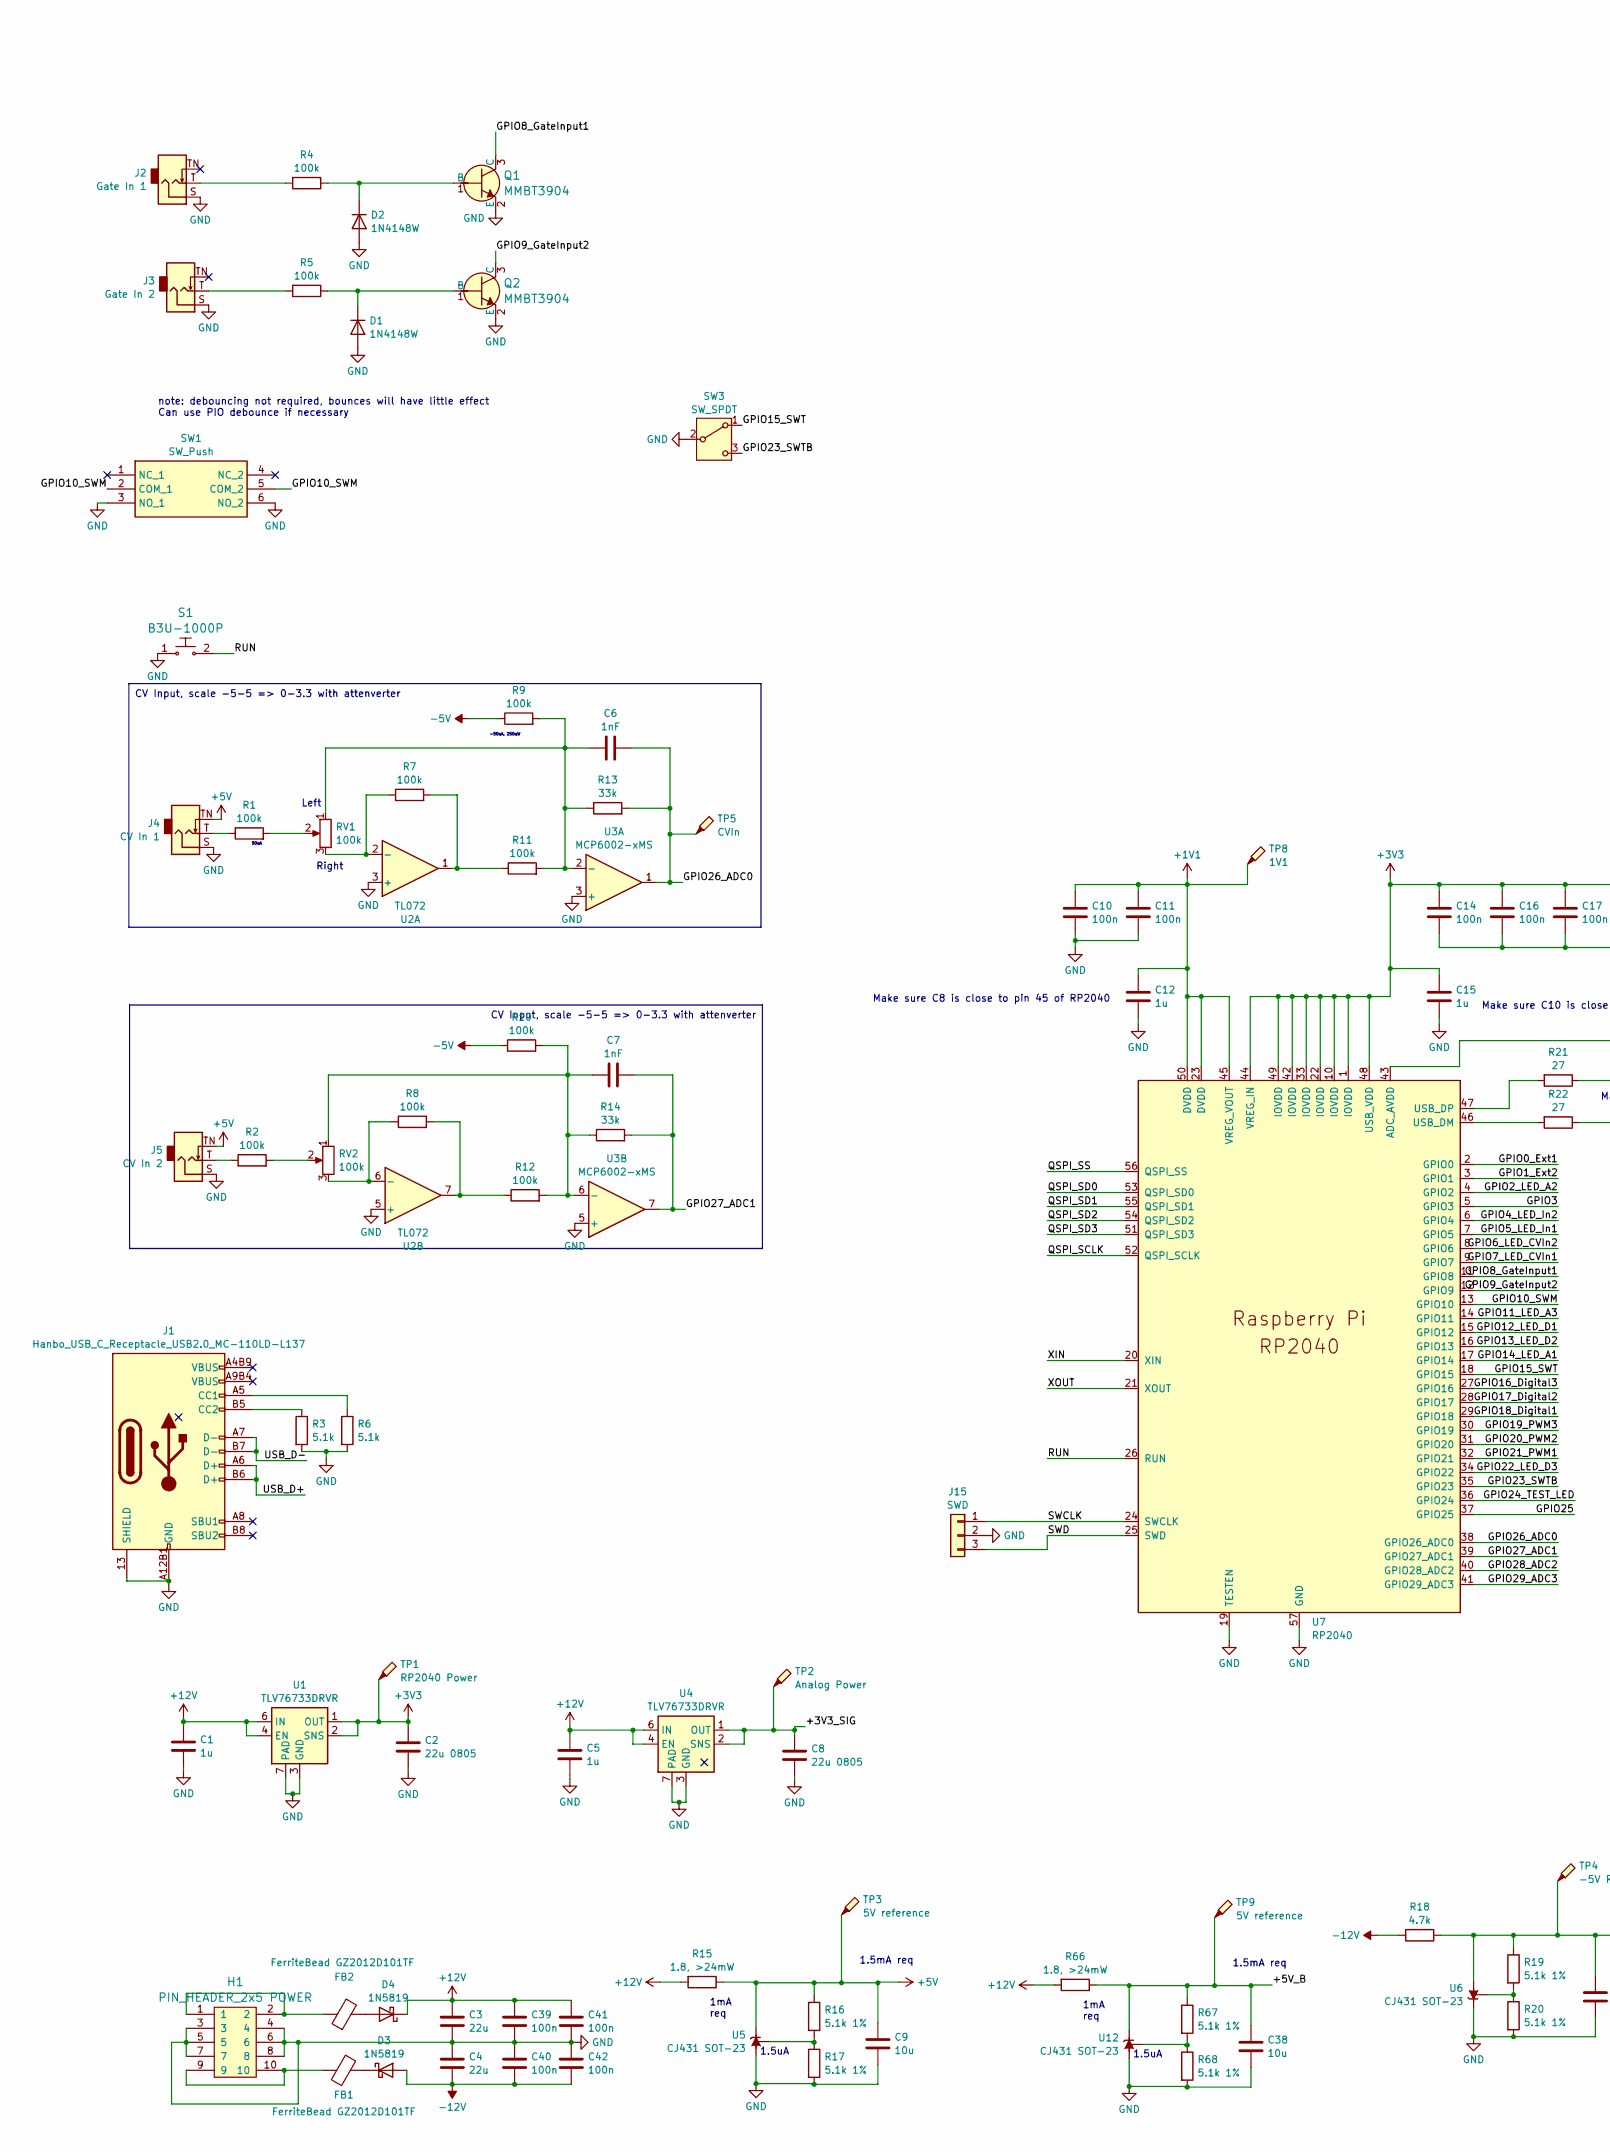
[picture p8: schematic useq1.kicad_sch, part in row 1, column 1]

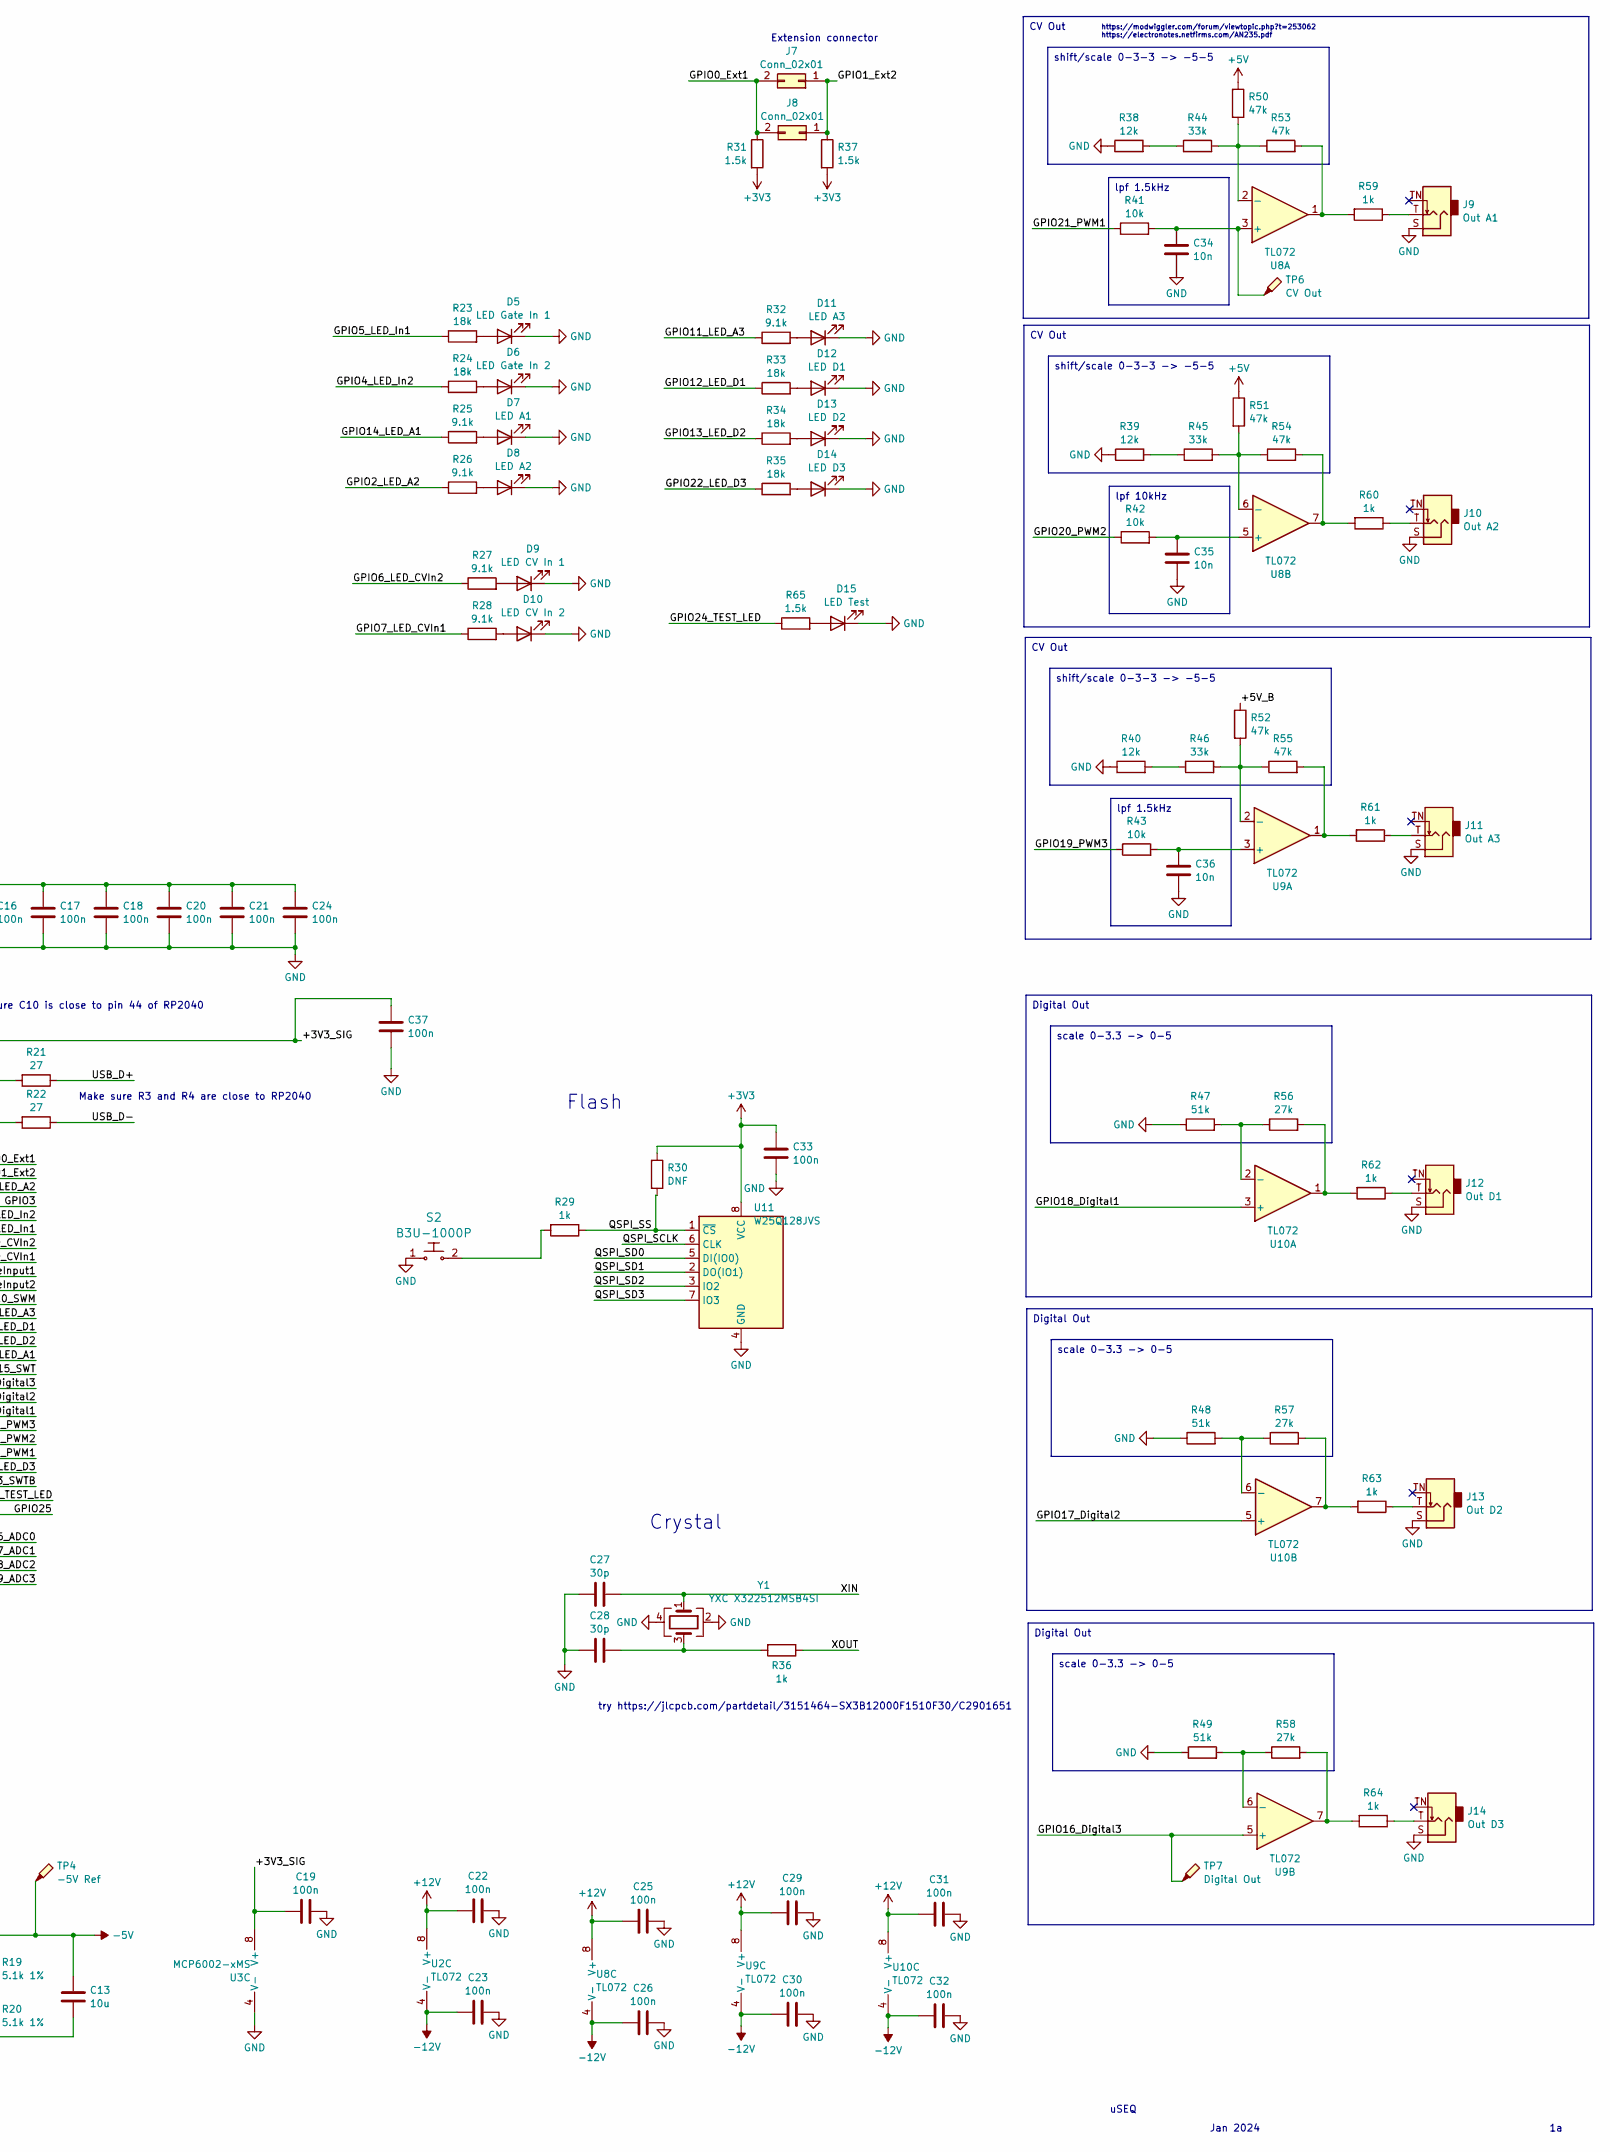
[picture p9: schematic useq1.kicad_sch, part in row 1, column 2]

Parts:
C1, C5: 1u; C_0603_1608Metric_Pad1.08x0.95mm_HandSolder
C2, C8: 22u 0805; C_0805_2012Metric_Pad1.18x1.45mm_HandSolder
C3, C4: 22u; C_0805_2012Metric
C6, C7: 1nF; C_0402_1005Metric
C9, C13, C38: 10u; C_0603_1608Metric
C10, C11, C14, C16, C17, C18, C20, C21, C24, C33, C37: 100n; C_0402_1005Metric
C12, C15: 1u; C_0402_1005Metric
C19, C22, C23, C25, C26, C29, C30, C31, C32, C39, C40, C41, C42: 100n; C_0603_1608Metric
C27, C28: 30p; C_0402_1005Metric
C34, C35, C36: 10n; C_0402_1005Metric
D1, D2: 1N4148W; D_SOD-123
D3, D4: 1N5819; D_SOD-323
D5: LED Gate In 1; LED_D3.0mm_FlatTop
D6: LED Gate In 2; LED_D3.0mm_FlatTop
D7: LED A1; LED_D3.0mm_FlatTop
D8: LED A2; LED_D3.0mm_FlatTop
D9: LED CV In 1; LED_D3.0mm_FlatTop
D10: LED CV In 2; LED_D3.0mm_FlatTop
D11: LED A3; LED_D3.0mm_FlatTop
D12: LED D1; LED_D3.0mm_FlatTop
D13: LED D2; LED_D3.0mm_FlatTop
D14: LED D3; LED_D3.0mm_FlatTop
D15: LED Test; LED_0603_1608Metric
FB1, FB2: FerriteBead GZ2012D101TF; R_0805_2012Metric
H1: PIN_HEADER_2x5 POWER; PinHeader_2x05_P2.54mm_Vertical_SMD
J1: Hanbo_USB_C_Receptacle_USB2.0_MC-110LD-L137; USB-C-TH_MC-110LD-L137-A
J2: Gate In 1; Jack_3.5mm_QingPu_WQP-PJ398SM_Vertical_CircularHoles
J3: Gate In 2; Jack_3.5mm_QingPu_WQP-PJ398SM_Vertical_CircularHoles
J4: CV In 1; Jack_3.5mm_QingPu_WQP-PJ398SM_Vertical_CircularHoles
J5: CV In 2; Jack_3.5mm_QingPu_WQP-PJ398SM_Vertical_CircularHoles
J7, J8: Conn_02x01; PinHeader_1x02_P2.54mm_Vertical
J9: Out A1; Jack_3.5mm_QingPu_WQP-PJ398SM_Vertical_CircularHoles
J10: Out A2; Jack_3.5mm_QingPu_WQP-PJ398SM_Vertical_CircularHoles
J11: Out A3; Jack_3.5mm_QingPu_WQP-PJ398SM_Vertical_CircularHoles
J12: Out D1; Jack_3.5mm_QingPu_WQP-PJ398SM_Vertical_CircularHoles
J13: Out D2; Jack_3.5mm_QingPu_WQP-PJ398SM_Vertical_CircularHoles
J14: Out D3; Jack_3.5mm_QingPu_WQP-PJ398SM_Vertical_CircularHoles
J15: SWD; PinHeader_1x03_P2.54mm_Vertical
Q1, Q2: MMBT3904; SOT-23; MPN MMBT3904-TP; Digi-Key_PN MMBT3904TPMSCT-ND
R1, R2, R4, R5, R7, R8, R9, R10, R11, R12: 100k; R_0402_1005Metric
R3, R6: 5.1k; R_0402_1005Metric
R13, R14: 33k; R_0402_1005Metric
R15, R66: 1.8, >24mW; R_0603_1608Metric
R16, R17, R19, R20, R67, R68: 5.1k 1%; R_0402_1005Metric
R18: 4.7k; R_0603_1608Metric
R21, R22: 27; C_0402_1005Metric
R23, R24, R33, R34, R35: 18k; R_0603_1608Metric
R25, R26, R27, R28, R32: 9.1k; R_0603_1608Metric
R29, R59, R60, R61, R62, R63, R64: 1k; R_0402_1005Metric
R30: DNF; C_0805_2012Metric
R31, R37, R65: 1.5k; R_0603_1608Metric
R36: 1k; R_0603_1608Metric
R38, R39, R40: 12k; R_0603_1608Metric
R41, R42, R43: 10k; R_0603_1608Metric
R44, R45, R46: 33k; R_0603_1608Metric
R47, R48, R49: 51k; R_0603_1608Metric
R50, R51, R52, R53, R54, R55: 47k; R_0603_1608Metric
R56, R57, R58: 27k; R_0603_1608Metric
RV1, RV2: 100k; Alpha9mmPot
S1, S2: B3U-1000P; Switch_Tactile_SMD_B3U-1000P; MPN B3U-1000P; Digi-Key_PN SW1020CT-ND
SW1: SW_Push; GPBS850N; Mouser Part Number 629-GPBS-850N
SW3: SW_SPDT; Thonk DWB2
TP1: RP2040 Power; TestPoint_Pad_1.5x1.5mm
TP2: Analog Power; TestPoint_Pad_1.5x1.5mm
TP3, TP9: 5V reference; TestPoint_Pad_1.5x1.5mm
TP4: -5V Ref; TestPoint_Pad_1.5x1.5mm
TP5: CVIn; TestPoint_Pad_1.5x1.5mm
TP6: CV Out; TestPoint_Pad_1.5x1.5mm
TP7: Digital Out; TestPoint_Pad_1.5x1.5mm
TP8: 1V1; TestPoint_Pad_1.5x1.5mm
U1, U4: TLV76733DRVR; WSON-6-1EP_2x2mm_P0.65mm_EP1x1.6mm_ThermalVias
U2, U8, U9, U10: TL072; SO-8_3.9x4.9mm_P1.27mm
U3: MCP6002-xMS; MSOP-8_3x3mm_P0.65mm
U5, U6, U12: CJ431 SOT-23; SOT-23
U7: RP2040; RP2040-QFN-56
U11: W25Q128JVS; SOIC-8_5.23x5.23mm_P1.27mm
Y1: YXC X322512MSB4SI; Crystal_SMD_3225-4Pin_3.2x2.5mm

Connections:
+1V1: C10.1, C11.1, C12.1, TP8.1, U7.23 (DVDD), U7.45 (VREG_VOUT), U7.50 (DVDD)
+3V3: C2.1, C14.1, C15.1, C16.1, C17.1, C18.1, C20.1, C21.1, C24.1, C33.1, R30.1, R31.2, R37.2, TP1.1, U1.1 (OUT), U1.2 (SNS), U7.1 (IOVDD), U7.10 (IOVDD), U7.22 (IOVDD), U7.33 (IOVDD), U7.42 (IOVDD), U7.44 (VREG_IN), U7.48 (USB_VDD), U7.49 (IOVDD), U11.8 (VCC)
+5V: C9.1, J4.TN, J5.TN, R15.1, R16.1, R50.1, R51.1, TP3.1, U5.2 (K)
+12V: C1.1, C3.1, C5.1, C22.2, C25.2, C29.2, C31.2, C39.1, C41.1, D4.1 (K), R15.2, R66.2, U1.4 (EN), U1.6 (IN), U2.8 (V+), U4.4 (EN), U4.6 (IN), U8.8 (V+), U9.8 (V+), U10.8 (V+)
-5V: C13.1, R9.1, R10.1, R18.1, R19.1, TP4.1, U6.3 (A)
-12V: C4.2, C23.2, C26.2, C30.2, C32.2, C40.2, C42.2, D3.2 (A), R18.2, U2.4 (V-), U8.4 (V-), U9.4 (V-), U10.4 (V-)
/+3V3_SIG: C8.1, C19.2, C37.1, TP2.1, U3.8 (V+), U4.1 (OUT), U4.2 (SNS), U7.43 (ADC_AVDD)
/+5V_B: C38.1, R52.1, R66.1, R67.1, TP9.1, U12.2 (K)
/GPIO0_Ext1: J7.2, J8.2, R31.1, U7.2 (GPIO0)
/GPIO1_Ext2: J7.1, J8.1, R37.1, U7.3 (GPIO1)
/GPIO2_LED_A2: R26.1, U7.4 (GPIO2)
/GPIO3: U7.5 (GPIO3)
/GPIO4_LED_In2: R24.1, U7.6 (GPIO4)
/GPIO5_LED_In1: R23.1, U7.7 (GPIO5)
/GPIO6_LED_CVIn2: R27.1, U7.8 (GPIO6)
/GPIO7_LED_CVIn1: R28.1, U7.9 (GPIO7)
/GPIO8_GateInput1: Q1.3 (C), U7.11 (GPIO8)
/GPIO9_GateInput2: Q2.3 (C), U7.12 (GPIO9)
/GPIO10_SWM: SW1.2 (COM_1), SW1.5 (COM_2), U7.13 (GPIO10)
/GPIO11_LED_A3: R32.1, U7.14 (GPIO11)
/GPIO12_LED_D1: R33.1, U7.15 (GPIO12)
/GPIO13_LED_D2: R34.1, U7.16 (GPIO13)
/GPIO14_LED_A1: R25.1, U7.17 (GPIO14)
/GPIO15_SWT: SW3.1 (A), U7.18 (GPIO15)
/GPIO16_Digital3: TP7.1, U7.27 (GPIO16), U9.5 (+)
/GPIO17_Digital2: U7.28 (GPIO17), U10.5 (+)
/GPIO18_Digital1: U7.29 (GPIO18), U10.3 (+)
/GPIO19_PWM3: R43.1, U7.30 (GPIO19)
/GPIO20_PWM2: R42.1, U7.31 (GPIO20)
/GPIO21_PWM1: R41.1, U7.32 (GPIO21)
/GPIO22_LED_D3: R35.1, U7.34 (GPIO22)
/GPIO23_SWTB: SW3.3 (C), U7.35 (GPIO23)
/GPIO24_TEST_LED: R65.1, U7.36 (GPIO24)
/GPIO25: U7.37 (GPIO25)
/GPIO26_ADC0: C6.1, R13.2, TP5.1, U3.1, U7.38 (GPIO26_ADC0)
/GPIO27_ADC1: C7.1, R14.2, U3.7, U7.39 (GPIO27_ADC1)
/GPIO28_ADC2: U7.40 (GPIO28_ADC2)
/GPIO29_ADC3: U7.41 (GPIO29_ADC3)
/QSPI_SCLK: U7.52 (QSPI_SCLK), U11.6 (CLK)
/QSPI_SD0: U7.53 (QSPI_SD0), U11.5 (DI(IO0))
/QSPI_SD1: U7.55 (QSPI_SD1), U11.2 (DO(IO1))
/QSPI_SD2: U7.54 (QSPI_SD2), U11.3 (IO2)
/QSPI_SD3: U7.51 (QSPI_SD3), U11.7 (IO3)
/QSPI_SS: R29.1, R30.2, U7.56 (QSPI_SS), U11.1 (~CS)
/RUN: S1.2, U7.26 (RUN)
/SWCLK: J15.1, U7.24 (SWCLK)
/SWD: J15.3, U7.25 (SWD)
/USB_D+: J1.A6 (D+), J1.B6 (D+), R21.1
/USB_D-: J1.A7 (D-), J1.B7 (D-), R22.1
/XIN: C27.1, U7.20 (XIN), Y1.1
/XOUT: R36.1, U7.21 (XOUT)
GND: C1.2, C2.2, C3.2, C4.1, C5.2, C8.2, C9.2, C10.2, C11.2, C12.2, C13.2, C14.2, C15.2, C16.2, C17.2, C18.2, C19.1, C20.2, C21.2, C22.1, C23.1, C24.2, C25.1, C26.1, C27.2, C28.2, C29.1, C30.1, C31.1, C32.1, C33.2, C34.2, C35.2, C36.2, C37.2, C38.2, C39.2, C40.1, C41.2, C42.1, D1.2 (A), D2.2 (A), D5.1 (K), D6.1 (K), D7.1 (K), D8.1 (K), D9.1 (K), D10.1 (K), D11.1 (K), D12.1 (K), D13.1 (K), D14.1 (K), D15.1 (K), H1.3, H1.4, H1.5, H1.6, H1.7, H1.8, J1.13 (SHIELD), J1.A1B12 (GND), J1.A12B1 (GND), J2.S, J3.S, J4.S, J5.S, J9.S, J10.S, J11.S, J12.S, J13.S, J14.S, J15.2, Q1.2 (E), Q2.2 (E), R3.2, R6.2, R17.2, R20.2, R38.1, R39.1, R40.1, R47.1, R48.1, R49.1, R68.2, S1.1, S2.1, SW1.3 (NO_1), SW1.6 (NO_2), SW3.2 (B), U1.3 (GND), U1.5 (GND), U1.7 (PAD), U2.3 (+), U2.5 (+), U3.3 (+), U3.4 (V-), U3.5 (+), U4.3 (GND), U4.5 (GND), U4.7 (PAD), U5.3 (A), U6.2 (K), U7.19 (TESTEN), U7.57 (GND), U11.4 (GND), U12.3 (A), Y1.2, Y1.4
unnamed: C28.1, R36.2, Y1.3
unnamed: D1.1 (K), Q2.1 (B), R5.1
unnamed: D2.1 (K), Q1.1 (B), R4.1
unnamed: D3.1 (K), FB1.2
unnamed: D4.2 (A), FB2.2
unnamed: D5.2 (A), R23.2
unnamed: D6.2 (A), R24.2
unnamed: D7.2 (A), R25.2
unnamed: D8.2 (A), R26.2
unnamed: D9.2 (A), R27.2
unnamed: D10.2 (A), R28.2
unnamed: D11.2 (A), R32.2
unnamed: D12.2 (A), R33.2
unnamed: D13.2 (A), R34.2
unnamed: D14.2 (A), R35.2
unnamed: D15.2 (A), R65.2
unnamed: FB1.1, H1.9, H1.10
unnamed: FB2.1, H1.1, H1.2
unnamed: J1.A5 (CC1), R6.1
unnamed: J1.B5 (CC2), R3.1
unnamed: J2.T, R4.2
unnamed: J3.T, R5.2
unnamed: J4.T, R1.1
unnamed: J5.T, R2.1
unnamed: J9.T, R59.1
unnamed: J10.T, R60.1
unnamed: J11.T, R61.1
unnamed: J12.T, R62.1
unnamed: J13.T, R63.1
unnamed: J14.T, R64.1
unnamed: R1.2, RV1.2
unnamed: R2.2, RV2.2
unnamed: R7.2, R11.1, U2.1
unnamed: R8.2, R12.1, U2.7
unnamed: R29.2, S2.2
unnamed: R38.2, R44.1
unnamed: R39.2, R45.1
unnamed: R40.2, R46.1
unnamed: R53.2, R59.2, U8.1
unnamed: R54.2, R60.2, U8.7
unnamed: R55.2, R61.2, U9.1
unnamed: R56.2, R62.2, U10.1
unnamed: R57.2, R63.2, U10.7
unnamed: R58.2, R64.2, U9.7
unnamed: R7.1, RV1.3, U2.2 (-)
unnamed: R8.1, RV2.3, U2.6 (-)
unnamed: C6.2, R9.2, R11.2, R13.1, RV1.1, U3.2 (-)
unnamed: C7.2, R10.2, R12.2, R14.1, RV2.1, U3.6 (-)
unnamed: R16.2, R17.1, U5.1 (REF)
unnamed: R19.2, R20.1, U6.1 (REF)
unnamed: R22.2, U7.46 (USB_DM)
unnamed: R21.2, U7.47 (USB_DP)
unnamed: C34.1, R41.2, TP6.1, U8.3 (+)
unnamed: R44.2, R50.2, R53.1, U8.2 (-)
unnamed: C35.1, R42.2, U8.5 (+)
unnamed: R45.2, R51.2, R54.1, U8.6 (-)
unnamed: C36.1, R43.2, U9.3 (+)
unnamed: R46.2, R52.2, R55.1, U9.2 (-)
unnamed: R49.2, R58.1, U9.6 (-)
unnamed: R47.2, R56.1, U10.2 (-)
unnamed: R48.2, R57.1, U10.6 (-)
unnamed: R67.2, R68.1, U12.1 (REF)

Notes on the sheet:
Digital Out
CV Input, scale -5-5 => 0-3.3 with attenverter
shift/scale 0-3-3 -> -5-5
scale 0-3.3 -> 0-5
CV Out
lpf 1.5kHz
lpf 10kHz
Crystal
1mA req
1.5mA req
Extension connector
https://modwiggler.com/forum/viewtopic.php?t=253062 https://electronotes.netfirms.com/AN235.pdf
1.5uA
Make sure R3 and R4 are close to RP2040
note: debouncing not required, bounces will have little effect Can use PIO debounce if necessary
Flash
Left
Make sure C10 is close to pin 44 of RP2040
Make sure C8 is close to pin 45 of RP2040
try https://jlcpcb.com/partdetail/3151464-SX3B12000F1510F30/C2901651
Jan 2024
50uA
uSEQ
-50uA, 250uW
Right

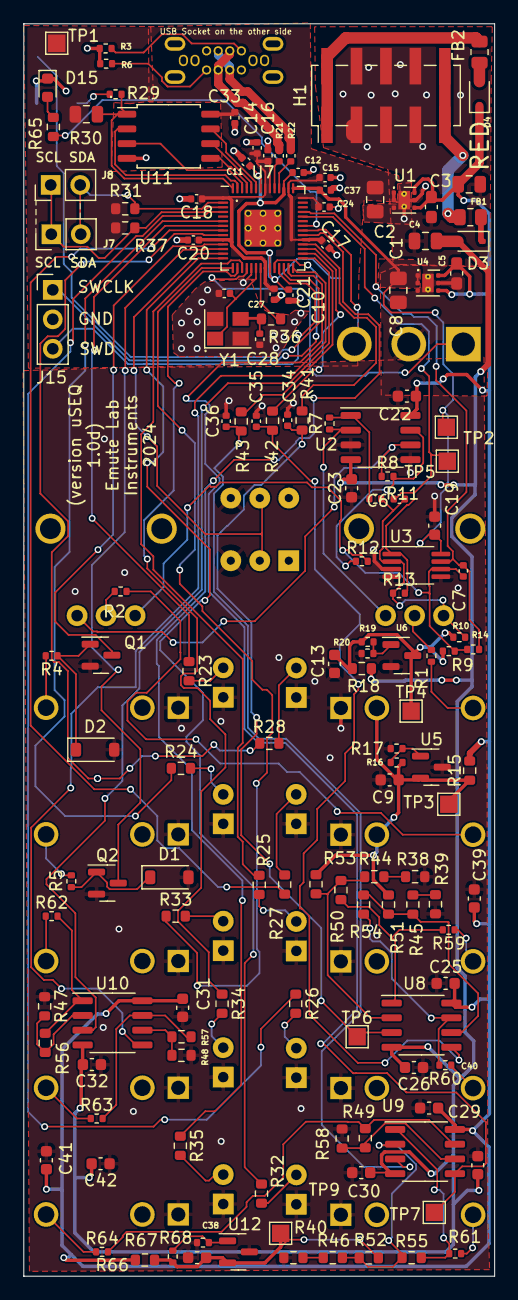
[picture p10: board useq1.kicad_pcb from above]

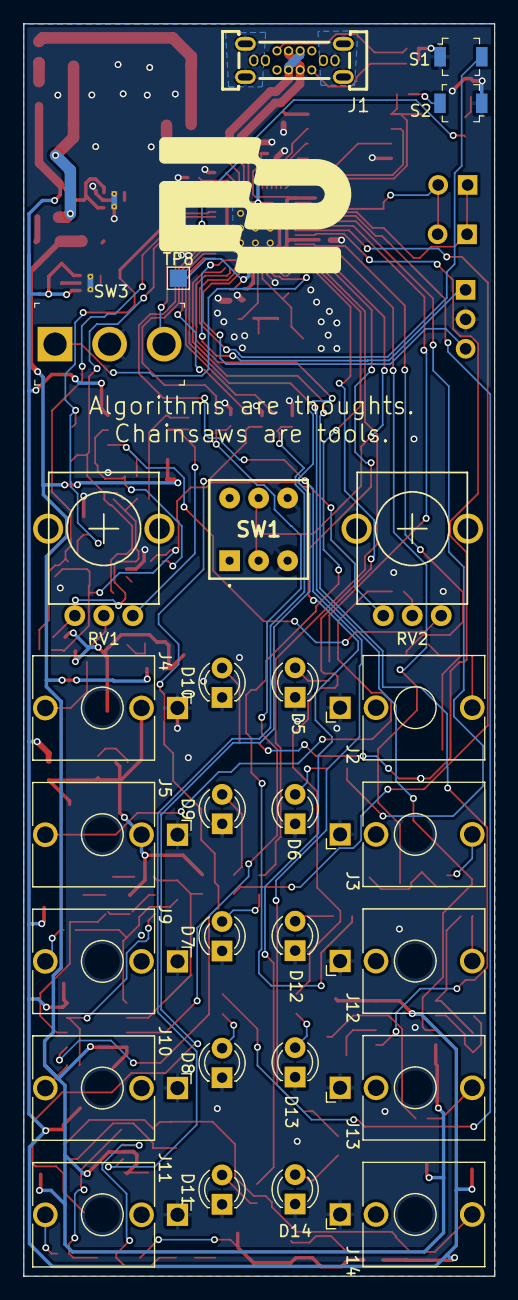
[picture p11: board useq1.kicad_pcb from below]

Board: 2 copper layers, 40.6 x 108.0 mm, 172 parts (28 on the bottom side), 110 nets.

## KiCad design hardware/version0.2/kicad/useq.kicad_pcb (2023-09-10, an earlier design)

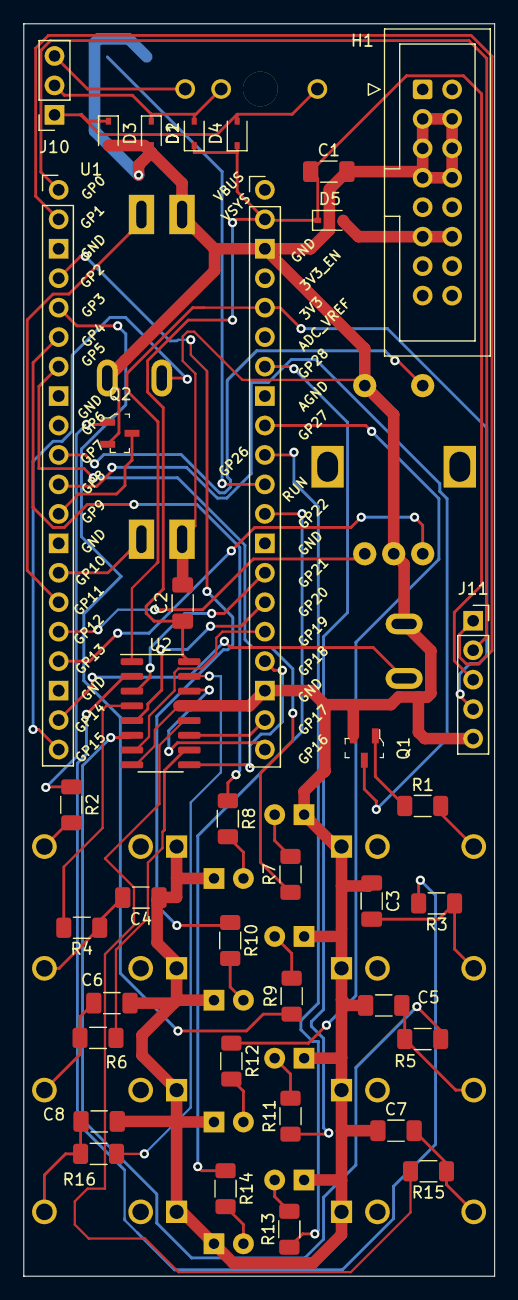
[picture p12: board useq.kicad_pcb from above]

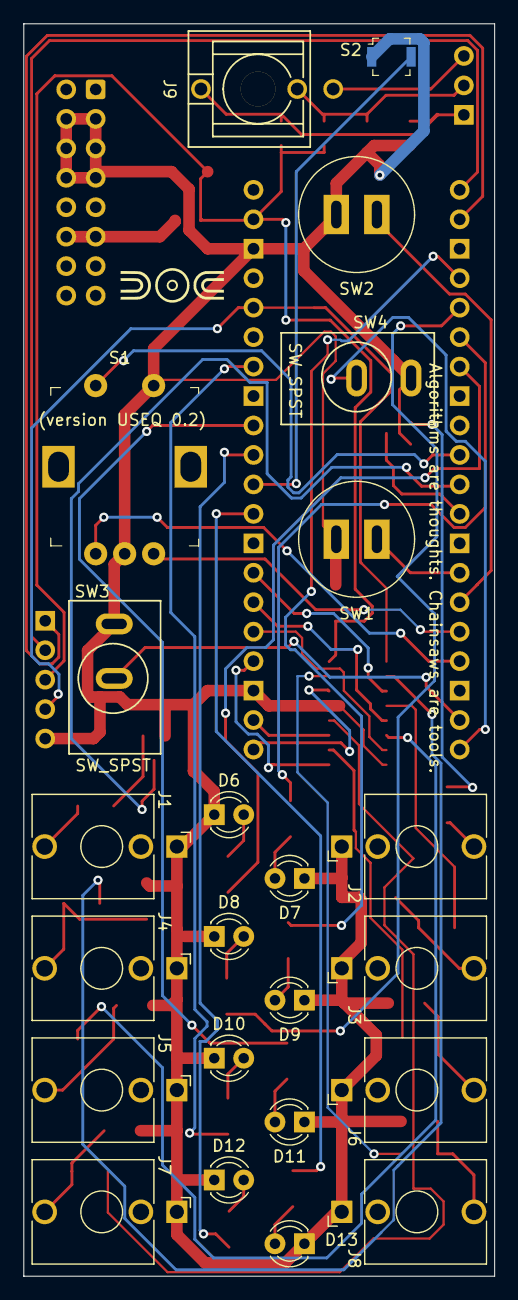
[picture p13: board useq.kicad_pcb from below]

Board: 2 copper layers, 40.6 x 108.0 mm, 59 parts (23 on the bottom side), 57 nets.

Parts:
C1: 10u; C_1206_3216Metric_Pad1.33x1.80mm_HandSolder
C2: 100n; C_1206_3216Metric_Pad1.33x1.80mm_HandSolder
C3, C4: 10n; C_1206_3216Metric_Pad1.33x1.80mm_HandSolder
C5, C6, C7, C8: (10n); C_1206_3216Metric_Pad1.33x1.80mm_HandSolder
D1, D2, D3, D4, D5: 1N5819; D_SOD-323
D6, D7, D8, D9, D10, D11, D12, D13: LED; LED_D3.0mm
H1: PIN_HEADER_2x8; IDC-Header_2x08_P2.54mm_Vertical
J1, J2, J3, J4, J5, J6, J7, J8: AudioJack2_SwitchT; Jack_3.5mm_QingPu_WQP-PJ398SM_Vertical_CircularHoles
J9: PJ366ST
J10: Conn_01x03; PinSocket_1x03_P2.54mm_Vertical
J11: Conn_01x05; PinSocket_1x05_P2.54mm_Vertical
Q1, Q2: 2N3904; SOT-23-3
R1, R2: 100k; R_1206_3216Metric_Pad1.30x1.75mm_HandSolder
R3, R4, R5, R6, R7, R8, R9, R10, R11, R12, R13, R14, R15, R16: 1k; R_1206_3216Metric_Pad1.30x1.75mm_HandSolder
S1: PEC11R-4215F-S0024; Rotary_Encoder_Switched_PEC11R
S2: B3U-1000P; Switch_Tactile_SMD_B3U-1000P
SW1, SW2: SW_Push; PBS-105
SW3, SW4: SW_SPST; ToggleSwitch_MTS-101_SPST
U1: Pico; RPi_Pico_Pinheaders
U2: 4504; SOIC-16_3.9x9.9mm_P1.27mm

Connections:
/3V3: J11.4, U1.36 (3V3), U2.1 (VCC)
/5V: C1.1, C2.1, D1.1 (K), D4.1 (K), D5.1 (K), J11.3, U1.39 (VSYS), U2.16 (VDD)
/D Out 1: R5.2, U2.6 (Cout)
/D Out 2: R6.2, U2.10 (Dout)
/D Out 3: R15.2, U2.12 (Eout)
/D Out 4: R16.2, U2.15 (Fout)
/PWM Out 1: R3.2, U2.2 (Aout)
/PWM Out 2: R4.2, U2.4 (Bout)
GND: C1.2, C2.2, C3.1, C4.1, C5.1, C6.1, C7.1, C8.1, D2.2 (A), D3.2 (A), D6.1 (K), D7.1 (K), D8.1 (K), D9.1 (K), D10.1 (K), D11.1 (K), D12.1 (K), D13.1 (K), H1.3, H1.4, H1.5, H1.6, H1.7, H1.8, J1.S, J2.S, J3.S, J4.S, J5.S, J6.S, J7.S, J8.S, J11.5, Q1.2 (E), Q2.2 (E), S1.2, S1.C (COM), S2.1, SW1.1, SW2.1, SW3.1 (A), SW4.1 (A), U1.23 (GND), U1.38 (GND), U2.8 (VSS), U2.13 (Select)
unnamed: C3.2, J4.T, R3.1
unnamed: C4.2, J3.T, R4.1
unnamed: C5.2, J5.T, R5.1
unnamed: C6.2, J6.T, R6.1
unnamed: C7.2, J7.T, R15.1
unnamed: C8.2, J8.T, R16.1
unnamed: D1.2 (A), D2.1 (K), J9.2, J10.2
unnamed: D3.1 (K), D4.2 (A), J9.3, J10.1
unnamed: D5.2 (A), H1.11, H1.12
unnamed: D6.2 (A), R7.2
unnamed: D7.2 (A), R8.2
unnamed: D8.2 (A), R9.2
unnamed: D9.2 (A), R10.2
unnamed: D10.2 (A), R11.2
unnamed: D11.2 (A), R12.2
unnamed: D12.2 (A), R13.2
unnamed: D13.2 (A), R14.2
unnamed: J1.T, R1.2
unnamed: J2.T, R2.2
unnamed: J9.1, J10.3
unnamed: J11.1, U1.2 (GPIO1)
unnamed: J11.2, U1.1 (GPIO0)
unnamed: Q1.1 (B), R1.1
unnamed: Q1.3 (C), U1.11 (GPIO8)
unnamed: Q2.1 (B), R2.1
unnamed: Q2.3 (C), U1.12 (GPIO9)
unnamed: R7.1, U1.7 (GPIO5)
unnamed: R8.1, U1.6 (GPIO4)
unnamed: R9.1, U1.5 (GPIO3)
unnamed: R10.1, U1.4 (GPIO2)
unnamed: R11.1, U1.34 (GPIO28_ADC2)
unnamed: R12.1, U1.32 (GPIO27_ADC1)
unnamed: R13.1, U1.31 (GPIO26_ADC0)
unnamed: R14.1, U1.29 (GPIO22)
unnamed: S1.1, U1.10 (GPIO7)
unnamed: S1.A (CH_A), U1.17 (GPIO13)
unnamed: S1.B (CH_B), U1.16 (GPIO12)
unnamed: S2.2, U1.30 (RUN)
unnamed: SW1.2, U1.14 (GPIO10)
unnamed: SW2.2, U1.15 (GPIO11)
unnamed: SW3.2 (B), U1.19 (GPIO14)
unnamed: SW4.2 (B), U1.20 (GPIO15)
unnamed: U1.21 (GPIO16), U2.14 (Fin)
unnamed: U1.22 (GPIO17), U2.11 (Ein)
unnamed: U1.24 (GPIO18), U2.9 (Din)
unnamed: U1.25 (GPIO19), U2.7 (Cin)
unnamed: U1.26 (GPIO20), U2.5 (Bin)
unnamed: U1.27 (GPIO21), U2.3 (Ain)

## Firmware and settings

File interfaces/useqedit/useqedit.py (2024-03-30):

import argparse
import curses
import sys
from art import *
from copy import deepcopy
from Clipping import MultiClip
from Lispy import Lispy
from Buffer import Buffer
from Cursor import Cursor
from Window import Window
from midiIO import midiIO
from SerialStreamMap import SerialStreamMap
import re
import json
import os
from SerialIO import SerialIO
from Console import Console
from SerialOutMappings import SerialOutMappings

import logging
logger = logging.getLogger(__name__)



def clamp(x, lower, upper):
    if x < lower:
        return lower
    if x > upper:
        return upper
    return x

def left(window, buffer, cursor):
    cursor.left(buffer)
    window.up(cursor)
    window.horizontal_scroll(cursor)


def right(window, buffer, cursor):
    cursor.right(buffer)
    window.down(buffer, cursor)
    window.horizontal_scroll(cursor)


redrawFlag = True


def main():

    global redrawFlag

    logging.basicConfig(filename='useqedit.log', level=logging.DEBUG)
    logger.info("Editor started")

    parser = argparse.ArgumentParser()
    parser.add_argument("filename", help="A file to edit")
    parser.add_argument("-cw", "--conswidth", help="console width", default=40, type=int)
    parser.add_argument("-p", "--port", help="serial usb port", default="")
    parser.add_argument("-lm", "--listmidi", help="show midi ports", action='store_true')
    args = parser.parse_args()

    stdscr = curses.initscr()
    curses.start_color()
    curses.mousemask(curses.ALL_MOUSE_EVENTS | curses.REPORT_MOUSE_POSITION)
    curses.mouseinterval(20)
    curses.init_pair(1, curses.COLOR_CYAN, curses.COLOR_BLACK)
    curses.init_pair(2, curses.COLOR_YELLOW, curses.COLOR_MAGENTA)
    curses.init_pair(3, curses.COLOR_GREEN, curses.COLOR_BLACK)
    curses.init_pair(4, curses.COLOR_BLUE, curses.COLOR_WHITE)
    curses.init_pair(5, curses.COLOR_CYAN, curses.COLOR_BLACK)
    curses.init_pair(6, curses.COLOR_WHITE, curses.COLOR_BLACK)
    curses.raw()
    consoleWidth = args.conswidth
    window = Window(curses.LINES - 1, curses.COLS - 1 - consoleWidth)
    editor = curses.newwin(curses.LINES - 1, curses.COLS - 1 - consoleWidth)
    Console.init(consoleWidth)

    cursor = Cursor()
    editor.keypad(True)


    def findMatchingLeftParenthesis(buffer, cursor):
        searchCursor = Cursor.createFromCursor(cursor)
        stack = 0
        found = False
        while searchCursor.left(buffer):
            searchChar = buffer.getch(searchCursor)
            if (searchChar == ')'):
                stack = stack + 1
            elif (searchChar == '('):
                if stack == 0:
                    found = True
                    break
                else:
                    stack = stack - 1
        return (searchCursor if found else None)

    def findMatchingRightParenthesis(buffer, cursor, stack=0):
        searchCursor = Cursor.createFromCursor(cursor)
        found = False
        while searchCursor.right(buffer):
            searchChar = buffer.getch(searchCursor)
            if (searchChar == '('):
                stack = stack + 1
            elif (searchChar == ')'):
                stack = stack - 1
                if stack == 0:
                    found = True
                    break
        return (searchCursor if found else None)

    def highlightCurrentCodeblock(buffer, cursor, editor, window):
        outerBrackets = None
        innerBrackets = None
        #find the nearest bracket to the left
        leftParenCursor = cursor if buffer.getch(cursor) == '(' else findMatchingLeftParenthesis(buffer, cursor)
        if leftParenCursor:
            #find the matching cursor to the right
            rightParen = findMatchingRightParenthesis(buffer, leftParenCursor, 1)
            if rightParen:
                #we've found at least one set of brackets
                innerBrackets = (leftParenCursor, rightParen)

                #search for outermost brackets
                outerBrackets = innerBrackets
                searching=True
                while searching:
                    testLeft = findMatchingLeftParenthesis(buffer, outerBrackets[0])
                    if (testLeft):
                        testRight = findMatchingRightParenthesis(buffer, testLeft,1)
                        if (testRight):
                            outerBrackets = [testLeft, testRight]

                    if testLeft==None or testRight==None:
                        searching=False


                if innerBrackets:
                    leftInnerBracketPos = window.translateCursorToScreenCoords(innerBrackets[0])
                    if window.isInWindow(leftInnerBracketPos):
                        editor.chgat(*leftInnerBracketPos, 1, curses.A_BOLD | curses.color_pair(1))
                    rightInnerBracketPos = window.translateCursorToScreenCoords(innerBrackets[1])
                    if window.isInWindow(rightInnerBracketPos):
                        editor.chgat(*rightInnerBracketPos, 1, curses.A_BOLD | curses.color_pair(1))
                    if outerBrackets != innerBrackets:
                        leftBracketPos = window.translateCursorToScreenCoords(outerBrackets[0])
                        if window.isInWindow(leftBracketPos):
                            editor.chgat(*leftBracketPos, 1, curses.A_BOLD | curses.color_pair(2))
                        rightBracketPos = window.translateCursorToScreenCoords(outerBrackets[1])
                        if window.isInWindow(rightBracketPos):
                            editor.chgat(*rightBracketPos, 1, curses.A_BOLD | curses.color_pair(2))
                        codestr = buffer.copy(outerBrackets[0], outerBrackets[1])
                        tokens = Lispy.tokenize_lisp(codestr)
                        ast = Lispy.get_ast(tokens.copy())
                        def doHighlights(v):
                            Console.post(v)
                        # Lispy.traverseAST(tokens, doHighlights)

            else:
                pass
        return outerBrackets, innerBrackets

    #serial setup
    SerialIO.openSerialCx(args.port)

    try:
        with open(args.filename) as f:
            buffer = Buffer(f.read().splitlines())
    except:
        buffer = Buffer([""])

    editor.nodelay(True) #nonblocking getch

    codeQueue = []
    undoList = []
    startMarker=None
    endMarker=None


    #midi setup
    midiIO.init()

    if args.listmidi:
        Console.post("MIDI Input Ports:")
        for i, midiport in enumerate(midiIO.listMIDIInputs()):
            Console.post(f"[{i}] {midiport}")

        Console.post("MIDI Output Ports:")
        for i, midiport in enumerate(midiIO.listMIDIOutputs()):
            Console.post(f"[{i}] {midiport}")

    # midi output mappings
    SerialStreamMap.init()
    configFile='useqedit.json'
    if os.path.exists(configFile):
        try:
            with open(configFile, 'r') as f:
                data = json.load(f)
                if "serialMap" in data:
                    error = SerialStreamMap.loadJSON(data["serialMap"])
                    if error:
                        Console.post("There was a configuration error, some settings may not have been applied")

        except Exception as e:
            Console.post("Error loading config")
            Console.post(e)

    def markedSection():
        return startMarker != None and endMarker != None

    def saveUndo(buffer, cursor):
        undoList.append([deepcopy(buffer), deepcopy(cursor)])
        #limit the size of the undo list
        if sys.getsizeof(undoList) > 1024 * 1024 * 128:
            undoList.pop(0)

    def clearMarkedSection():
        startMarker = None
        endMarker = None

    redrawFlag = True


    # Console.post(curses.has_colors());
    # Console.post(curses.COLORS);
    #make gradiented colors for brackets
    #todo: check if terminal has enough colors
    import colorsys
    for i in range(25):
        rgb = colorsys.hsv_to_rgb(0.3, i/25, 1.0)
        curses.init_color(200+i,  int(rgb[0]*1000), int(rgb[1]*1000), int(rgb[2]*1000))

    while True:
        editor.refresh()
        if redrawFlag:
            # stdscr.erase()
            # console.erase()
            editor.erase()
            # console.border(1)
            # Console.post()

            highlightOn = False
            for row, line in enumerate(buffer[window.row:window.row + window.n_rows-1]):
                if row == cursor.row - window.row and window.col > 0:
                    line = "«" + line[window.col + 1:]
                if len(line) > window.n_cols:
                    line = line[:window.n_cols - 1] + "»"
                for i, ch in enumerate(line):
                    editor.addch(row,i,ch)
                    if markedSection():
                        if (row == startMarker.row and i == startMarker.col):
                            highlightOn = True
                        if  (row == endMarker.row and i == endMarker.col):
                            highlightOn = False
                        if (highlightOn):
                            editor.chgat(row, i, curses.color_pair(1))

                # editor.addstr(row, 0, line)
            editor.move(*window.translateCursorToScreenCoords(cursor))

            outerBrackets = None
            innerBrackets = None

            #do highlighting
            outerBrackets, innerBrackets = highlightCurrentCodeblock(buffer, cursor, editor, window)
            # if still didn't find outerbrackets, we need to move leftwards because we might be between lisp statements
            if outerBrackets==None:
                searchCursor = Cursor.createFromCursor(cursor)
                while searchCursor.left(buffer):
                    searchChar = buffer.getch(searchCursor)
                    if (searchChar == ')'):
                        outerBrackets, innerBrackets = highlightCurrentCodeblock(buffer, searchCursor, editor, window)
                        break




            #highlight keywords
            for row in range(window.row, min(window.bottom, len(buffer))):
                # updateConsole(row)
                line = buffer.getLine(row)
                # updateConsole(line)
                if len(line) > 0 and line[0] == "#":
                    for highlightPos in range(window.col, min(len(line), window.col + window.n_cols)):
                        editor.chgat(row - window.row, highlightPos, 1, curses.A_DIM | curses.color_pair(6))
                else:
                    def searchAndHighlight(regexStr, colourIdx):
                        for match in re.finditer(regexStr, line):
                            for highlightPos in range(match.start(), min(match.end(), window.col + window.n_cols)):
                                if line[highlightPos] not in ['(',')']:
                                    editor.chgat(row-window.row, highlightPos, 1, curses.color_pair(colourIdx))
                    searchAndHighlight(r'd1|d2|d3|d4|d5|d6|a1|a2|a3|a4|a5|a6|in1|in2|swm|swt|swr|rot|q0|s1|s2|s3|s4|s5|s6|s7|s8',3)
                    searchAndHighlight(r'fast|fromList|sqr|gatesw|trigs|\+|\-|\*|\/|perf|pm|dw|dr|useqaw|useqdw|delay|delaym|millis|micros|pulse|slow|flatIdx|flat|looph|dm|gates|setbpm|settimesig|interp|mdo|sin|cos|tan|abs|min|max|pow|sqrt|scale|seq|step|euclid|defun',4)
                    searchAndHighlight(r'(\s|\()(bar|phrase|beat|section|time|t)(\s|\))',5)

            editor.move(*window.translateCursorToScreenCoords(cursor))
            redrawFlag=False

        def sendTouSEQ(codestr, prefix=''):
            #reformat to single line
            tokens = Lispy.tokenize_lisp(codestr)
            ast = Lispy.get_ast(tokens.copy())
            codestr = Lispy.astToOneLineCode(ast)
            if not SerialIO.sendTouSEQ(prefix + codestr):
                Console.post("uSEQ disconnected")
                SerialIO.openSerialCx(args.port)
        def cutSection(st, en):
            code = buffer.copy(st, en)
            buffer.deleteSection(st, en)
            return code

        Console.postQueuedMessages()

        k = editor.getch()

        if (k!=-1):
            redrawFlag=True
            # Console.post(f"key {k}")
            if (k == curses.KEY_MOUSE):
                _, mx, my, _, bstate = curses.getmouse()
                # Console.post(f"mouse {bstate}")
                if bstate==1:
                    # if (my < window.n_rows and mx < window.n_cols):
                    my = max(0,my)
                    mx = max(0,mx)
                    newCursor = window.translateScreenCoordsToCursor(my, mx)
                    Console.post(f"{newCursor.row} {newCursor._col} {my} {mx}")
                    # newCursor._clamp_row(buffer)
                    # Console.post(f"{newCursor.row} {newCursor._col}")
                    # newCursor._clamp_col(buffer)
                    # Console.post(f"{newCursor.row} {newCursor._col}")
                    newCursor.clamp(buffer)
                    cursor.move(newCursor.row, newCursor.col, buffer)
                elif bstate==65536:
                    cursor.down(buffer)
                    window.down(buffer, cursor)
                    window.horizontal_scroll(cursor)
                elif bstate==2097152:
                    cursor.up(buffer)
                    window.up(cursor)
                    window.horizontal_scroll(cursor)
            else:
                # Console.post(f"input {k}")
                if k == 23: #ctrl-w
                    SerialIO.close()
                    curses.endwin()
                    sys.exit(0)
                elif k == 260: #left arrow
                    left(window, buffer, cursor)
                # elif k == 393:  # shift-left arrow
                #     None
                # elif k == 550:  # left arrow
                #     None
                elif k == 258: #down arrow
                    cursor.down(buffer)
                    window.down(buffer, cursor)
                    window.horizontal_scroll(cursor)
                elif k == 259: #up arrow
                    cursor.up(buffer)
                    window.up(cursor)
                    window.horizontal_scroll(cursor)
                elif k == 261: #right arrow
                    right(window, buffer, cursor)
                # elif k == 402:  # shift-right arrow
                #     None
                # elif k == 565:  # ctrl-right arrow
                #     None
                # elif k == 566:  # ctrl-shift-right arrow
                #     None
                elif k == 10: #enter
                    saveUndo(buffer, cursor)
                    buffer.split(cursor)
                    right(window, buffer, cursor)
                elif k in [330]: #delete
                    saveUndo(buffer, cursor)
                    ch = buffer.delete(cursor)
                elif k in [127, 263]: #backspace
                    if (cursor.row, cursor.col) > (0, 0):
                        saveUndo(buffer, cursor)
                        left(window, buffer, cursor)
                        buffer.delete(cursor)
                elif k == 12: #ctrl-l - run, quantised
                    if outerBrackets:
                        code = buffer.copy(outerBrackets[0], outerBrackets[1])
                        sendTouSEQ(code)
                    else:
                        Console.post("missing a bracket?")
                elif k == 11:  # ctrl-k - run immediately
                        if outerBrackets:
                            code = buffer.copy(outerBrackets[0], outerBrackets[1])
                            sendTouSEQ(code, '@')
                        else:
                            Console.post("missing a bracket?")
                elif k == 3:  # ctrl-c - copy
                    def copySection(st, en):
                        code = buffer.copy(st, en)
                        return code
                    if markedSection():
                        MultiClip.copy(copySection(startMarker, endMarker))
                        clearMarkedSection()
                    elif outerBrackets:
                        sect = copySection(outerBrackets[0], outerBrackets[1])
                        Console.post(sect)
                        MultiClip.copy(sect)
                    Console.post(f"pb << {MultiClip.paste()}")
                elif k == 24:  # ctrl-X - cut
                    if markedSection():
                        saveUndo(buffer, cursor)
                        MultiClip.copy(cutSection(startMarker, endMarker))
                        clearMarkedSection()
                        cursor = startMarker
                    elif outerBrackets:
                        saveUndo(buffer, cursor)
                        MultiClip.copy(cutSection(outerBrackets[0], outerBrackets[1]))
                        cursor = outerBrackets[0]
                    Console.post(f"pbx << {MultiClip.paste()}")
                elif k == 22:  # ctrl-v - paste
                    saveUndo(buffer, cursor)
                    buffer.insert(cursor, MultiClip.paste())
                    for i in range(len(MultiClip.paste())):
                        right(window, buffer, cursor)
                elif k == 9: #ctrl-i
                    #add statement to queue
                    if outerBrackets:
                        code = buffer.copy(outerBrackets[0], outerBrackets[1])
                        codeQueue.append(code)
                        Console.post(f"Qd: {code}")
                elif k == 15: #ctrl-o, send Q
                    Console.post(f"Sending Q: {len(codeQueue)}")
                    for i, statement in enumerate(codeQueue):
                        Console.post(f"{i} {statement}")
                        sendTouSEQ(statement)
                    codeQueue = []
                elif k == 26: #ctrl-z - undo
                    if len(undoList) > 0:
                        newState = undoList.pop()
                        buffer = deepcopy(newState[0])
                        cursor = deepcopy(newState[1])
                elif k == 28: #ctrl-\, asciiart the current line as a  comment
                    currentLine = buffer.deleteLine(cursor)
                    Console.post(currentLine)
                    s = text2art(currentLine)
                    #add ;comment symbols to the text
                    s = ";" + s
                    s = s.replace('\n', '\n;')
                    s = s + '\n'
                    # s = "11111\n2222222\n333\n4444\n"
                    Console.post(s)
                    buffer.insert(cursor, s)
                elif k == 2: #ctrl-b - begin
                    startMarker = Cursor.createFromCursor(cursor)
                elif k == 7: #ctrl-g
                    endMarker = Cursor.createFromCursor(cursor)
                elif k == 6:  # ctrl-f - format statement
                    if (outerBrackets):
                        saveUndo(buffer,cursor)
                        cursor = outerBrackets[0]
                        code = cutSection(outerBrackets[0], outerBrackets[1])
                        tokens = Lispy.tokenize_lisp(code)
                        ast = Lispy.get_ast(tokens.copy())
                        codestr = Lispy.astToFormattedCode(ast)
                        buffer.insert(cursor, codestr)
                elif k==27: #alt-...
                    esck = editor.getch()
                    Console.post(f"esc {esck} ")
                    if esck==102: #alt-f, unformat
                        if (outerBrackets):
                            saveUndo(buffer, cursor)
                            cursor = outerBrackets[0]
                            code = cutSection(outerBrackets[0], outerBrackets[1])
                            tokens = Lispy.tokenize_lisp(code)
                            ast = Lispy.get_ast(tokens.copy())
                            codestr = Lispy.astToOneLineCode(ast)
                            buffer.insert(cursor, codestr)

                else:
                    kchar = chr(k)
                    if (kchar.isascii()):
                        saveUndo(buffer,cursor)
                        if (kchar=='('):
                            buffer.insert(cursor, ')')
                        buffer.insert(cursor, kchar)

                        right(window, buffer, cursor)
                        editor.refresh()

                #save the buffer
                if buffer.hasNewChanges():
                    with open(args.filename, "w") as f:
                        [f.write(x + '\n') for x in buffer]
                    buffer.resetNewChanges()


        SerialIO.readSerial()
        SerialOutMappings.process()
        #save some cpu
        curses.napms(5)






if __name__ == "__main__":
    main()

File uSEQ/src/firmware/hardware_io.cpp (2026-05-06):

#include "hardware_io.h"

// ── Pin definitions and hardware constants ──────────────────────────────────
// We define pin numbers directly rather than including pinmap.h to avoid
// ODR violations from the non-inline arrays declared there.  These values
// are exact copies of the constants in pinmap.h — if pinmap.h changes,
// these must be updated in lockstep.

#ifdef ARDUINO
#include <Arduino.h>
#include <SPI.h>
#include <hardware/gpio.h>
#include <hardware/pio.h>
#include "utils/piopwm.h"
#include "utils/ResponsiveAnalogRead.h"
#include "../utils/serial_message.h"
#include <algorithm>

// PIO PWM helpers (same as in the old io_manager)
static inline void hw_pio_pwm_set_level(PIO pio, uint sm, uint32_t level) {
    pio_sm_put_blocking(pio, sm, level);
}
static inline void hw_pio_pwm_set_period(PIO pio, uint sm, uint32_t period) {
    pio_sm_set_enabled(pio, sm, false);
    pio_sm_put_blocking(pio, sm, period);
    pio_sm_exec(pio, sm, pio_encode_pull(false, false));
    pio_sm_exec(pio, sm, pio_encode_out(pio_isr, 32));
    pio_sm_set_enabled(pio, sm, true);
}

// ── Music Thing pin map ──────────────────────────────────────────────────
#ifdef MUSICTHING

// Digital gate inputs
static constexpr int PIN_I1 = 2;
static constexpr int PIN_I2 = 3;

// LED pins
static constexpr int LED_AUDIO_L = 10;
static constexpr int LED_AUDIO_R = 11;
static constexpr int LED_A3      = 12;
static constexpr int LED_A4      = 13;
static constexpr int LED_D1      = 14;
static constexpr int LED_D2      = 15;

// Output pins: aL, aR, a3, a4, d1, d2
static constexpr int OUTPUT_PINS[]     = { -1, -1, 23, 22, 8, 9 };
static constexpr int OUTPUT_LED_PINS[] = { LED_AUDIO_L, LED_AUDIO_R,
                                           LED_A3, LED_A4,
                                           LED_D1, LED_D2 };

// Mux / analog
static constexpr int MUX_IN_1_PIN  = 28;
static constexpr int MUX_IN_2_PIN  = 29;
static constexpr int MUX_LOGIC_A_PIN = 24;
static constexpr int MUX_LOGIC_B_PIN = 25;
static constexpr int AUDIO_IN_L_PIN = 26;
static constexpr int AUDIO_IN_R_PIN = 27;

// DAC SPI
static constexpr int DAC_SCK_PIN = 18;
static constexpr int DAC_SDI_PIN = 19;
static constexpr int DAC_CS_PIN  = 21;

static constexpr int HW_NUM_CONTINUOUS = 4;
static constexpr int HW_NUM_BINARY     = 2;
static constexpr int HW_NUM_OUTPUTS    = 6;  // continuous + binary

// Inversion flags (Music Thing specific)
static constexpr bool INVERT_ANALOG  = true;
static constexpr bool INVERT_DIGITAL = true;

// MCP4822 SPI DAC — aL (channel 0) and aR (channel 1)
static SPISettings dac_spi_settings(20000000, MSBFIRST, SPI_MODE0);

static inline void dac_write(uint8_t channel, uint16_t value_12bit) {
    if (value_12bit > 4095) value_12bit = 4095;
    // MCP4822: [channel | 0 | gain=1x | active | 12-bit data]
    uint16_t cmd = 0x3000 | (value_12bit & 0x0FFF);
    if (channel & 1) cmd |= 0x8000;
    SPI.beginTransaction(dac_spi_settings);
    digitalWrite(DAC_CS_PIN, LOW);
    SPI.transfer16(cmd);
    digitalWrite(DAC_CS_PIN, HIGH);
    SPI.endTransaction();
}

// Input channels: 0-3 via MUX_IN_1, 4-5 via MUX_IN_2, 6-7 audio direct
static constexpr int NUM_RESPONSIVE_CHANNELS = 8;
static constexpr int OVERSAMPLE_COUNT = 4;

#endif // MUSICTHING

// ── Hardware v1.0 pin map ────────────────────────────────────────────────
#ifdef USEQHARDWARE_1_0

static constexpr int PIN_I1 = 8;
static constexpr int PIN_I2 = 9;

static constexpr int PIN_AI1 = 26;
static constexpr int PIN_AI2 = 27;

static constexpr int LED_I1  = 5;
static constexpr int LED_I2  = 4;
static constexpr int LED_AI1 = 25;
static constexpr int LED_AI2 = 24;
static constexpr int LED_A1  = 3;
static constexpr int LED_A2  = 2;
static constexpr int LED_A3  = 11;
static constexpr int LED_D1  = 12;
static constexpr int LED_D2  = 13;
static constexpr int LED_D3  = 22;

static constexpr int OUTPUT_PINS[]     = { 21, 20, 19, 18, 17, 16 };
static constexpr int OUTPUT_LED_PINS[] = { LED_A1, LED_A2, LED_A3,
                                           LED_D1, LED_D2, LED_D3 };

static constexpr int PIN_SWITCH_M1 = 10;
static constexpr int PIN_SWITCH_T1 = 14;
static constexpr int PIN_SWITCH_T2 = 23;

static constexpr int HW_NUM_CONTINUOUS = 3;
static constexpr int HW_NUM_BINARY     = 3;
static constexpr int HW_NUM_OUTPUTS    = 6;

static constexpr bool INVERT_ANALOG  = false;
static constexpr bool INVERT_DIGITAL = false;

#endif // USEQHARDWARE_1_0

// ── Hardware v0.2 pin map ────────────────────────────────────────────────
#ifdef USEQHARDWARE_0_2

static constexpr int PIN_I1 = 8;
static constexpr int PIN_I2 = 9;

static constexpr int LED_I1 = 5;
static constexpr int LED_I2 = 4;
static constexpr int LED_A1 = 3;
static constexpr int LED_A2 = 2;
static constexpr int LED_D1 = 28;
static constexpr int LED_D2 = 27;
static constexpr int LED_D3 = 26;
static constexpr int LED_D4 = 22;
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

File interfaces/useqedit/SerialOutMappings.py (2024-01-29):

from Console import Console
from midiIO import midiIO
from SerialIO import SerialIO
import struct

# double
# val = result.as_float();
# Serial.write((u_int8_t)
# 31);
# Serial.write((u_int8_t)(i + 1));
# char * byteArray = reinterpret_cast < char * > (& val);
# for (size_t b = 0; b < 8; b++) {
#     Serial.write(byteArray[b]);
# }


class SerialOutMappings:

    channels = [0]

    @classmethod
    def process(cls):
        #flip back to zero after triggering
        if (cls.channels[0] == 1.0):
            cls.channels[0] = 0.0
            cls.sendSerialValue(1, 0.0)

        for port in midiIO.inports:
            for msg in port.iter_pending():
                # Console.post(msg.dict())
                if msg.dict()['type'] == 'note_on':
                    if msg.dict()['note'] == 36:
                        cls.channels[0] = 1.0
                        cls.sendSerialValue(1, cls.channels[0])

                # v = 1
                # channel = 1
                # cls.sendSerialValue(channel, v)

    @classmethod
    def sendSerialValue(cls, channel, v):
        msgBegin = [31, channel ]
        SerialIO.sendBytes(bytearray(msgBegin))
        valueBytes = struct.pack('d', v)
        SerialIO.sendBytes(bytearray(valueBytes))

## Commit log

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2025-09-30 fix(hardware): add Arduino guards to ResponsiveAnalogRead for desktop builds
    Add conditional compilation guards to allow ResponsiveAnalogRead to
    compile in desktop/test environments without Arduino libraries.
    [ResponsiveAnalogRead.cpp]
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2026-03-28 feat: implement signal engine (Phase 0) — reactive graph architecture
    New signal engine per docs/SIGNAL_ENGINE_SPEC.md, built alongside the
    existing bytecode VM. Replaces the conceptual stack of Value + Environment
    + bytecode compiler + dual executors with a flat array of arithmetic nodes.
    Components (uSEQ/src/signal_engine/):
    - types.h: constants and limits
    - token.h/cpp: zero-allocation tokenizer (Token 16 bytes, 256 buffer)
    - cell_store.h/cpp: Cell (16 bytes), CellStore, SourceArena, data pool
    - node_pool.h/cpp: Node (20 bytes), hash-consed CSE, constant folding,
    algebraic simplification, topological sort
    - graph_builder.h/cpp: recursive-descent compiler with temporal templates,
    ti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
    [cell_store.h, cold_eval.h]
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2026-03-28 feat: complete signal engine features — 6 parallel workstreams merged
    Source text storage fix (foundational):
    - do_define/do_defn now store expression body text in SourceArena
    - do_output_assign stores output source for dependency recompilation
    - on_cell_changed() can now recompile affected outputs
    - Graph builder returns dependency info via GraphBuildResult
    Euclid fix (useq-cxv):
    - Replaced Bresenham with old engine's modular arithmetic algorithm
    - Added pulse width gating, matching old engine's exact semantics
    - euclid(1,4), euclid(3,8), euclid(4,1) all match old engine
    Random/index-rand (useq-ddy):
    - New HashIndex NodeOp with deterministic bit-mixing hash
    - random()/random(lo,hi) hash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
    [cold_eval.h, node_pool.h]
2026-03-28 refactor: X-macro symbol table, dispatch table, const_cast fix, error recovery, expt
    Symbol management (symbols.def):
    - Single X-macro .def file defines all ~90 symbols with categories
    - Struct fields, init_symbols(), and classification functions generated
    from one source of truth
    - All operator symbols (+,-,*,/,>,<,>=,<=,=) now cached — no more
    runtime intern() calls in is_arithmetic_op/comparison_sym_to_op
    Form dispatch (compile_form):
    - 100-line if-chain replaced with sorted lookup table (28 entries)
    - Binary search dispatch for standard-signature form handlers
    - Category-based fallthrough for math/comparison/logic
    - Special-case forms (gates, tri, lambda, quote, input) remain expl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
    [node_pool.h]
2026-03-28 refactor: architecture hardening — 9 improvements merged
    SignalEngine struct (bundles all state):
    - CellStore, SourceArena, NodePool, EngineState, OutputSources in one struct
    - init_defaults() convenience method
    - eval_cold() overload taking SignalEngine& (legacy overload preserved)
    ExecutionContext struct (replaces 10-parameter executor):
    - Bundles t, cell_values, hw_inputs, data_pool, offsets, lengths,
    prev_outputs, output_values, workspace
    - execute_all_outputs(pool, ctx) is the primary interface
    CellStore::init_timing_defaults():
    - Eliminates 15-line boilerplate in every caller
    - Used by tests, probe, WASM wrapper
    Bounds-checked node accessor (NodePool::get()):
    - Returns static nu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
    [cell_store.h, cold_eval.h]
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2026-03-29 feat: firmware architecture — composition-based rewrite per FIRMWARE_SPEC.md
    Replace the monolithic uSEQ class (~4,500 lines) with a composition of
    independent modules orchestrated by a Firmware struct with a clean tick loop.
    New firmware/ modules (2,764 lines total):
    - Firmware: tick loop (time→inputs→eval→execute→outputs→commit→stream→watchdog)
    - HardwareIO: pin access, input sampling, output writing, LEDs (all variants)
    - SerialProtocol: JSON-framed USB protocol (hello/ping/eval/stream-config)
    - FlashStorage: CRC32-validated cell/output persistence to RP2040 flash
    - I2CNetwork: multi-module communication with ring buffer + timeout
    - DSPEngine: core 1 audio synthesis with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
    [firmware.cpp]
2026-03-29 feat: prev-output refs, beat-dur/bar-dur, recompile-on-load
    Signal engine additions:
    - (prev a1) form and bare output refs (a1, d1, etc.) in expressions
    compile to PrevOutputLoad — reads previous tick's output value.
    Enables feedback loops: (a2 (+ (prev a1) 0.1))
    - beat-dur and bar-dur timing symbols — expose beat/bar duration
    in seconds (60/bpm and 60/bpm*beats-per-bar). Use with offset
    for beat-relative time shifts: (offset (* 0.5 beat-dur) expr)
    - compile_prev() form handler with error messages for invalid args
    - Output refs checked before cell table in compile_symbol()
    Cold-path additions:
    - recompile_all_outputs(SignalEngine&) — rebuilds all output graphs
    from stored so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
    [cold_eval.h, firmware.cpp]
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2026-04-30 feat: TDD roadmap phases 1-5,7 — test harness, semantic gaps, diagnostics, robustness, reactivity, defstate/integrate
    Phase 1: Enhanced GoldenHarness with expect_error, sample_window, verify_batch_matches_single,
    tick_sequence helpers. Created coverage ledger mapping all spec sections to test status.
    Phase 2: Closed core semantic gaps — nullary (+)/(*)=identity, unary (/ x)=reciprocal,
    variadic min/max, let* sequential bindings, arity boundary checks, for unrolling,
    quote rejection, alias verification, non-numeric root diagnostics.
    Phase 3: Fixed 28 error reporting sites to use correct DiagnosticCategory (was all Runtime).
    Added category-aware report_error_cat/report_error_at_cat. Test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
    [cold_eval.h, node_pool.h]
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2026-05-01 feat(firmware): F4 hello response uses type:"response" wrapper (bd: useq-83w)
    Per wire-protocol.md §5.1+§5.2: every response to a request must carry
    type:"response". Prepends the field to the handle_hello() response builder.
    Also fixes extract_last_json() test helper to find the last top-level JSON
    line rather than the last '{' (which was matching nested braces). Removes
    the [.][!shouldfail] tag from contract test F5.
    [serial_protocol.cpp]
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2026-05-01 feat(firmware): F3 log envelope replaces TEXT/MSG_TO_EDITOR (bd: useq-l23)
    Add SerialProtocol::send_log(level, text) emitting {type:"log",level,text}\n
    via the existing write_json_str bare-JSON path (no 0x1F/0x65 framing).
    Remove [.][!shouldfail] from F3 contract test; replace FAIL placeholder with
    real assertions: call send_log("info", "Hello from uSEQ"), drain stdout,
    extract_last_json, assert type/level/text fields, assert no 0x1F/0x65 prefix.
    All 10 meson tests pass. Legacy Protocol::println / message_editor in
    utils/log.cpp still use TEXT/MSG_TO_EDITOR bytes but are only reached by the
    legacy uSEQ.cpp interpreter path, not the new firmware::Firmware composition.
    TEXT and MSG_TO_EDITOR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
    [serial_protocol.cpp, serial_protocol.h]
2026-05-01 feat(firmware): F5 set-live-inputs protocol-level handler (bd: useq-3ur)
    Add handle_set_live_inputs() to firmware::SerialProtocol per wire-protocol.md
    §5.8. Refactor read_command into a testable dispatch_message() helper (public).
    Counts slots in the inbound JSON object; emits {type:response,success:true,
    applied:N} ack when requestId present; fire-and-forget when absent. Slot-table
    write deferred with TODO pointing at live-edit.md §5.3. Replace F6 placeholder
    test with passing contract tests for both the ack and fire-and-forget paths.
    [serial_protocol.cpp, serial_protocol.h]
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2026-05-03 feat(signal-engine): output classification pass + WASM ABI exports
    Add per-output purity classification (Pure/InputDep/Stateful) computed
    after each compilation. The sampler can use this to skip projection fork
    work for pure outputs and selectively invalidate on input changes.
    - OutputClass enum in types.h
    - classify_outputs() in executor.cpp — iterative DFS over node trees
    - useq_output_classifications() / useq_output_dependencies() WASM exports
    - 18 golden tests covering all classification cases
    [node_pool.h]
2026-05-03 feat(state-sync): get-state protocol handler + apply_state_snapshot WASM export + bug fixes
    Firmware:
    - Add get-state JSON protocol handler that serialises full interpreter
    state (transport, cells, outputs with source, state slots, live slots)
    - Wire engine pointer into SerialProtocol for state access
    - Add useq_apply_state_snapshot WASM export with proper JSON parsing
    (string-aware depth tracking, escape handling, structural field lookup)
    - Add _useq_apply_state_snapshot to EXPORTED_FUNCTIONS in build_wasm.sh
    - 4 golden tests for get-state response shape, cells, outputs, and
    null-engine failure (all passing, 49 assertions in 11 tests total)
    [firmware.cpp, serial_protocol.cpp, serial_protocol.h]
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2026-05-04 chore: delete ~10K lines dead old-architecture code + signal engine hygiene
    Bloat audit (useq-z2x, useq-gal) cleanup:
    Delete dead code:
    - uSEQ/src/uSEQ/ (IOManager, OutputManager, i2c, pinmap, configure.h)
    - uSEQ/src/dsp/ (DSPatch library + 20 uSeqGen components)
    - uSEQ/src/io/std.cpp (broken, never compiled)
    - 5 unused port interfaces + mocks (keep IStorage/MockStorage)
    - error_messages.h/cpp, logger_bridge, default_logger (zero references)
    - compiler_config.h: trim to just warning-suppression macros
    Signal engine hygiene:
    - Remove phantom NodeOps: DataLoad, Scale5, USinBi, UCosBi
    - Merge NodeOp::Fmod into NodeOp::Mod (identical semantics)
    - Merge NodeOp::Pow into NodeOp::Expt (swap args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
    [ResponsiveAnalogRead.cpp, compiler_config.h]
2026-05-04 refactor: migrate legacy test API to SignalEngine, delete legacy overloads
    - Migrated 49 eval_cold(src, len, cells, arena, pool) callsites in
    test_signal_engine.cpp to eval_cold(src, len, engine)
    - Migrated all 10-param execute_all_outputs calls to ExecutionContext version
    - Transport tests now check engine.state instead of deleted g_engine_state
    - Deleted legacy 5-param eval_cold overload (cold_eval.cpp, ~50 lines)
    - Deleted legacy on_cell_changed overload (cold_eval.cpp, ~35 lines)
    - Deleted legacy 10-param execute_all_outputs overload (executor.cpp, ~25 lines)
    - Deleted globals: g_engine_state, output_sources[]
    - Deleted corresponding declarations from cold_eval.h and executor.h
    - Fixed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
    [cold_eval.h]
2026-05-04 fix: recover piopwm.h to firmware/utils/, update firmware spec
    - Move piopwm.h from deleted uSEQ/src/uSEQ/ to firmware/utils/ (fixes
    broken #include in hardware_io.cpp for Arduino builds)
    - Rewrite firmware.md source-file pointers to match post-cleanup layout
    - Add §4.5 (SPI DAC gap), §4.6 (input filtering gap), §8 (known gaps
    table) documenting implementation vs spec discrepancies
    - Update persistence section for LittleFS migration plan
    - Add Expander variant to variant table
    - Remove all references to deleted files (configure.h, pinmap.h,
    io_manager, output_manager, unused port interfaces)
    [hardware_io.cpp]
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2026-05-04 feat: add StateResourceRegistry for keyed state identity (Phase 1a)
    Add data structures for the state-identity system:
    - StateResourceKey: (state_id, resource_kind, role) triple that uniquely
    identifies a state resource within a stateful expression
    - StateResourceRegistry: maps keys to dense state slot indices with
    resolve(), mark_all_inactive(), and clear() operations
    - ResourceKind enum covers all stateful primitives (oscillator phase,
    trigger memory, slew, integrate, one-pole, etc.)
    - Registry preserves accumulated state values across recompilation —
    resolve() returns existing slot for matching keys
    - Added to SignalEngine as registry member
    - 5 unit tests covering allocation,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
    [cold_eval.h]
2026-05-04 feat(firmware): SPI DAC for Music Thing aL/aR + restore ResponsiveAnalogRead
    - Add MCP4822 SPI DAC write function for Music Thing variant. Outputs
    0-1 (aL, aR) now use SPI DAC instead of analogWrite(). Outputs 2-3
    (a3, a4) remain PWM.
    - SPI init added to HardwareIO::init() for MUSICTHING.
    - Recover ResponsiveAnalogRead library to firmware/utils/ (adaptive
    threshold, noise gating, activity detection). Replace simple EMA
    filter for MUSICTHING analog inputs.
    - Median-of-3 filter kept for USEQHARDWARE_1_0 AI1/AI2.
    Addresses useq-0iq and useq-i7o.
    [ResponsiveAnalogRead.cpp, hardware_io.cpp]
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2026-05-04 feat(firmware): I2C networking with expander discovery and broadcasting (useq-dtq)
    - Expander scan now records discovered device addresses (up to 5)
    - Add sync_all(): send $sync to all expanders
    - Add send_eval_to(): send code to a specific expander
    - Add broadcast_tempo(): send BPM + beat phase to all expanders
    - Add broadcast_output_values(): send output values for expander playback
    - Fix broken #include of deleted configure.h; use PIO build flags for
    I2C pin definitions instead
    - Desktop path remains no-op
    [i2c_network.cpp, i2c_network.h]
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2026-05-04 fix: Scale op formula was wrong + skip invalid pin in MUSICTHING init
    - Scale: was c*(b-a)+a, should be a*(c-b)+b (maps value from [0,1] to
    [min,max]). This was the pre-existing bug causing (scale 0.5 100 200)
    to return 19900.5 instead of 150.0. All 136+1107 tests now pass.
    - MUSICTHING: skip OUTPUT_PINS[i] == -1 in pinMode loop (first two
    outputs use SPI DAC, not GPIO — passing -1 to pinMode is UB).
    [hardware_io.cpp]
2026-05-04 fix: vec_buf ownership + bracket nesting in vector eval
    Two bugs in top-level vector evaluation:
    1. Static vec_buf replaced with engine.eval_text_buf member. The static
    buffer was safe in current call paths (only last result survives in
    do/implicit-do) but fragile — any future path storing an intermediate
    Text result across another eval_form call would clobber it. Member
    ownership makes the lifetime explicit.
    2. Element-skipping now handles bracket nesting, not just parens.
    Previously [(expr) [1 2 3]] would skip just the '[' token for the
    inner vector, producing wrong source spans for eval_expression.
    Now tracks depth for both LParen/RParen and LBracket/RBracket.
    [cold_eval.h]
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2026-05-04 fix(firmware): 3 hardware bugs — PIO/LED conflict, audio inputs, batch commit
    - MUSICTHING: skip PIO PWM setup for LED pins (MUSICTHING uses
    analogWrite, not PIO — was claiming pins then writing with the
    wrong peripheral). Closes useq-263.
    - MUSICTHING: store audio L/R inputs at INP_AUDIO_L/R (slots 14/15).
    Previously read but discarded — signal engine saw 0.0. Bump
    num_hw_inputs from 14 to 16. Closes useq-3ny.
    - WASM execute_batch_sequential: add commit_outputs() between samples
    so PrevOutputLoad sees updated values. Save/restore prev_output_values
    and lkg_value alongside state. Closes useq-u95.
    [hardware_io.cpp]
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2026-05-04 feat(live-edit): compiler feature completion + firmware handler + bug fixes
    Compiler features (epic useq-fc2):
    - LiveSlot struct: variant (numeric/boolean/keyword), options, step, precision
    - Boolean/keyword seed support in compile_live_edit
    - Type-aware validation in set_live_slot_value (NaN/Inf, clamp, cast)
    - Cross-output duplicate :id detection via SharedLiveEditIDs
    - Eager-consume rejection (set-bpm, set-time-sig, set-time-offset, nudge-time)
    - defstate :initial rejection via next_is_live_edit() + reject_live_edit flag
    - Dead-slot DFS warning for unreferenced SlotLoad nodes
    - Unknown keyword rejection, OutputDeps slot tracking
    - MAX_LIVE_SLOTS: 256 on WASM/desktop, 32 on firmware (#ifde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
    [node_pool.h, serial_protocol.cpp]
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2026-05-05 fix(firmware/v1.0): add clamping to LED exponential curve result
    The exponential curve calculation (led_val * led_val) >> 11 can produce
    values that overflow or behave unexpectedly if not clamped. Add explicit
    bounds checking to ensure led_val stays within [0, MAX_PWM_I] after the
    curve is applied. This fixes incorrect brightness and cross-talk on
    USEQHARDWARE_1_0 continuous output LEDs.
    [hardware_io.cpp]
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2026-05-06 Revert: remove LED clamping that didn't fix v1.0 LED bugs
    The clamping lines added in the previous commit did not resolve the
    LED brightness and cross-talk issues on USEQHARDWARE_1_0. Revert to
    the exact working code from useq-fresh.
    [hardware_io.cpp]
2026-05-06 fix(firmware/v1.0): restore LED pipeline + production hardware control
    Two bugs were preventing v1.0 LEDs from working:
    1. firmware.cpp was remapping output_values into a compact "continuous
    then binary" layout in io.outputs[], but hardware_io::write_outputs()
    reads the engine layout (a's at 0..7, d's at 8..15). Net result:
    d-outputs were written to io.outputs[3..5] but write_outputs read
    d-outputs from io.outputs[8..10] (always zero). Fix: mirror the
    full output_values array faithfully.
    2. hardware_io::init() called pinMode(OUTPUT_LED_PINS[i], OUTPUT_2MA)
    on all LED pins after pwm_program_init had already assigned the
    continuous-output LED pins to PIO. pinMode -> gpio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
    [firmware.cpp, hardware_io.cpp]
2026-05-06 feat(firmware/serial): restore StreamChannel API with input streaming
    Replaces the flat stream_channel_enabled[] flag array with a structured
    stream_channels[] array of StreamChannel entries:
    { enabled, source: Time|Output|Input, source_idx, on_change_only,
    last_sent }
    Wire channels are now a separate namespace from output indices: channel
    1 is always time, channels 2+ map to editor-subscribed signals (ain1,
    ain2, output values, etc.). The editor declares the mapping via
    stream-config.
    Updates the F7 STREAM-frame test to the new API and refreshes the
    wire-protocol spec section 5.3 that still referenced the old field.
    [serial_protocol.cpp, serial_protocol.h]
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2026-06-14 fix(signal_engine): bound DFS stacks (OOB), widen slot_count guard, compile-depth limit, prev-batch, classify refresh, oversize diagnostics
    FW1: bounds-guard DFS reachability stacks in NodePool::rebuild_execution_order + gc_unreachable_nodes (+child<node_count guard) — was OOB write on dense DAGs.
    FW2: widen OutputDeps::slot_count uint8_t->uint16_t — 'slot_count < MAX_LIVE_SLOTS(256)' was always-true on WASM, guard never fired.
    FW3: MAX_COMPILE_DEPTH=64 RAII guard in compile_expr — was unbounded recursion on RP2040 stack inside tick().
    FW4: route prev-feedback (no defstate) outputs through sequential batch path — fast path read stale prev() per sample (prev.md §1.4/1.6).
    FW5: classi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
    [node_pool.h, serial_protocol.cpp]
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2026-07-02 fix(serial_protocol): resync RX ring on oversized line / impossible binary frame (F2)
    The serial RX path could permanently deadlock (all serial input dead
    until reboot) via two triggers against the fixed 2048-byte ring buffer:
    (a) A JSON line >2048 bytes with no newline fills the ring;
    try_extract_message found no '\n' and returned false without
    flushing, so drain_serial_into_rx_buf could never add more bytes.
    Reachable in normal use (a ~2KB eval envelope exceeds the ring).
    (b) try_consume_binary_frame computed frame_len = 4 + count*10 with
    count a u16 (up to 65535 -> ~655KB); for count >= 205 the frame can
    never fit, so 'if (m_rx_len < frame_len) return Incomplete' was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
    [serial_protocol.cpp, serial_protocol.h]
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2026-07-14 perf(firmware): skip per-tick cell snapshot when cells unchanged (A12)
    The tick loop copied all MAX_CELLS cell values every tick — measured at
    ~40% of the engine tick — even though cells only change on cold evals.
    CellStore gains a store-wide revision counter bumped at the coarse
    mutation entry points (eval_cold, init_timing_defaults, flash
    deserialize); the firmware tick re-snapshots only when it changes.
    Overcounting is safe by construction, undercounting impossible since
    all cell mutations flow through those entry points. No semantic change
    single-threaded. Firmware e2e suite and pio musicthing build green.
    [cell_store.h, firmware.cpp]
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2026-07-14 feat(engine): configurable non-finite failure mode — LKG fallback by default
    Two independent audits flagged spec drift against failure-model.md
    §2.1/§3.1: non-finite values were silently squashed to 0.0 per node
    instead of triggering the mandated whole-output LKG fallback. Ruling:
    both behaviours ship as a global runtime option, LKG being the default.
    Engine (executor):
    - sig::FailureMode {LkgFallback (default), ZeroSquash (legacy)} with
    set_failure_mode()/get_failure_mode(); per-node isfinite squash now
    runs only in ZeroSquash mode.
    - LkgFallback: a non-finite value reaching an output root substitutes
    OutputSlot.lkg_value (neutral 0 when no LKG, §2.4) in both the
    single-sample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
    [node_pool.h, serial_protocol.cpp, serial_protocol.h]
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2026-07-18 fix(signal-engine): reclaim source-arena space on re-eval (B1)
    The source arena is an append-only bump allocator, so every re-eval of an
    output/define/defstate re-stored its text and leaked the previous copy,
    exhausting the arena after ~139 re-evals of a 250-char expr (16KB desktop,
    4KB firmware). Add SourceArena::store_reuse(existing_offset, existing_length,
    ...): when a slot is re-stored and the new text fits its prior region, it
    overwrites in place without advancing write_head; only longer text appends a
    fresh region. Wire all five re-store sites (do_define, do_defn, eval_form
    cell-store, do_defstate, do_output_assign) through it, resolving each slot before
    storing. Also harden store() ov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
    [cell_store.h]
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2026-07-19 feat(synth): versioned synth artefact ABI and native/WASM equivalence (VAL-COMP-015,016)
    - synth_graph.h: SYNTH_ARTIFACT_ABI_VERSION (=1) constant plus
    synth_artifacts_supports_abi() (rejects incompatible consumers
    explicitly) and synth_artifacts_render_abi_wrapper() that emits
    the canonical {abi,revision,declarations,controls} envelope the
    WASM wrapper already produced. Incompatible consumers receive a
    minimal abi_error JSON object instead of the body.
    - synth_graph.cpp: single-pass synth_graph_render_json() (removes
    the prior wasteful double-emit), and the new ABI wrapper renders
    through the same scratch path so native and WASM payloads are
    byte-equal for the same engine st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
    [synth_graph.h]
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2026-07-20 fix(signal-engine): with-state-id wrapper id becomes synth identity (ergo e58f128f)
    The cold-path with-state-id handler consumed the wrapper's identity
    string and discarded it, while do_synth's anonymous fallback keyed off
    synth_graph.revision — which advances every eval — so the second eval of
    an unnamed (editor-wrapped) synth minted a fresh identity and failed the
    M1 single-node capacity check with 'another identity already active'.
    This broke the M1 click-free re-eval acceptance (synth-nodes.md §5.1/§5.5).
    Fix, per state-identity.md §2.2 (wrapper and :id normalise to the same
    identity annotation):
    - SignalEngine gains an eval-scoped pending_state_identity slot and a
    per-eval an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
    [cold_eval.h]
2026-08-01 feat(compiler): harden transactional semantics and synth ABI 2
    Reconstructed from surviving 2026-08-01 Codex session transcripts after the unpublished /tmp candidate was lost on reboot. Equivalent tree diff to recorded candidate boundary 6e5292b: 45 files, 3110 insertions, 600 deletions.
    [cell_store.h, cold_eval.h, firmware.cpp]
2026-08-01 fix(signal-engine): reclaim retired compiler resources
    Reconstructed from the recorded integrated resolution at former candidate 8e3b04a.
    [node_pool.h]
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
